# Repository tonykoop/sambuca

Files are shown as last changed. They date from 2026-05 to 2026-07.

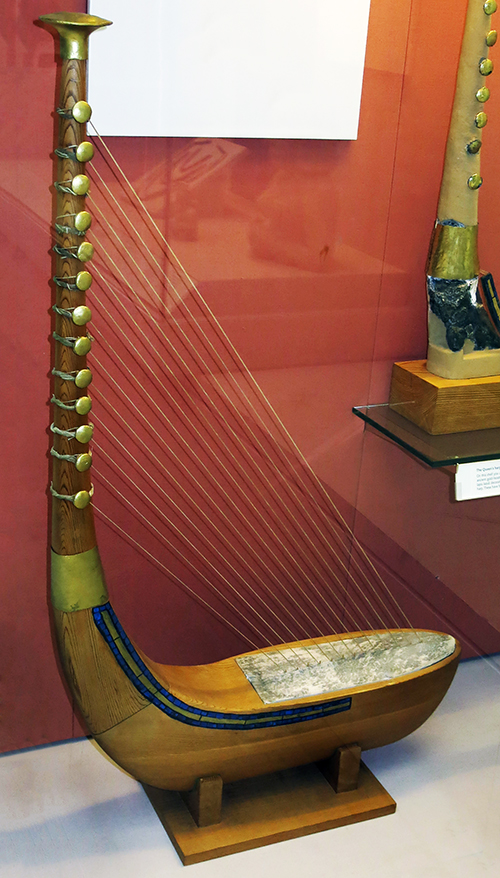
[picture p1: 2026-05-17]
images/SambucaPhotobyDonHitchcock_BritishMuseum.jpg

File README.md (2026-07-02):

# Sambuca

A modern boat-shaped arched harp inspired by the Royal Cemetery of Ur, c. 2600 BC.

> "More accurately described as a boat-shaped harp" — British Museum curator's card, object 121198.

**Status:** L2 V5 build-packet candidate

## Readiness

Private review. Full v4 planning packet complete (BOM, cut list, validation, assembly manual, Wolfram acoustic study, capstone deck). SolidWorks CAD is kora Pack-and-Go inherited geometry (pending rebuild per `cad/SW-MIGRATION-CHECKLIST.md`); a parametric OpenSCAD envelope master (`cad/sambuca.scad`, authority `pending_measurement`) now scaffolds the boat-hull/neck family from `family-spec.csv`, but no fabrication-authority drawings exist yet. Three release gates open: SAM-13-MULE tension/joint validation, cultural-advisor review, Heifer Zephyr brand integration. Not L3 — no measured template, no dimensioned DXF, no prototype setup report.

---

## What this is

The sambuca is Tony Koop's reinterpretation of the Sumerian boat-shaped arched harp recovered from the Royal Tombs at Ur. The original artifact (British Museum object 121198) survives only as gold tuning pegs, lapis lazuli decorative fragments, and Woolley's field sketches; the wood was reconstructed in 1971–72 from contemporary cylinder-seal depictions. That gives the modern build a 4500-year-old visual fingerprint — boat hull, curved cantilever neck, gold-flared cap, multi-strip lapis seam band, row of bulb tuning pegs with cord wraps, bow-end inlay panel, integral stern stub feet — and full design freedom on every dimension underneath.

This build modernizes the form with:

- CNC-routed walnut boat hull, raised depth (D/L = 0.31 for SAM-13, scaling to 0.40 for SAM-25 per chang reference) — parametric half-ellipsoid; stave-laminated alternative supported.
- Laminated-bend CNC-swept sapele neck.
- **Zither pegs (wood-bodied, steel hex tip)** for SAM-13 — switched 2026-05-16 from gold-bulb-capped geared tuners; matches chang-tradition look and pairs with new hull-side inlay program. Modern metal geared hardware remains a documented alternate.
- Western red cedar soundboard (~3 mm) with light fan bracing.
- Multi-strip lapis-look CNC inlay band along the soundboard-hull seam (5 parallel strips with light spacers).
- Rectangular pale inlay panel at the bow end of the soundboard (mother-of-pearl or shell composite).
- **Intricate longitudinal hull-side inlay** running ~70% of body length on both hull faces (added 2026-05-16) — cylinder-seal-style figural or Sumerian-rosette motifs, CNC-routed pockets backfilled with shell, contrasting wood, brass wire, or dyed epoxy.
- Brass collar over a glued scarf joint at the neck-body junction.
- **Slip-cast ornamental finial** at the top of the neck (porcelain or stoneware, glazed; natural placement for the Heifer Zephyr bison mark) — chosen 2026-05-16 over the BM-style flared gold cap.
- Single oval keel-port soundhole projecting forward toward the listener (not toward the player).
- Glued-on string-holder strip near the bow (standard arched-harp practice — no separate raised bridge bar).
- Fluorocarbon-treble + wound-nylon-bass string set, calibrated to 65–80 kgf total.
- Walnut CNC-curve-profiled cradle stand with kanawa-tsugi or mitsuke-aritsugi joinery.

## Family

Five planned variants, all from one MasterLayout part. See `family-spec.csv`.

| ID | Body length | Strings | Tuning | Harness | Role |
|---|---|---|---|---|---|
| **SAM-13-ROOT** | 650 mm | 13 | G3 → E5 | none | build target |
| SAM-19-MID | 850 mm | 19 | D3 → G5 | low-back belt | mid concert |
| SAM-25-CONCERT | 1050 mm | 25 | A2 → A5 | sax harness | concert |
| SAM-13-AE | 650 mm | 13 | G3 → E5 | none + piezo | acoustic-electric |
| SAM-13-MULE | 650 mm | 13 | G3 → E5 (reduced T) | none | tension test mule |

## Status

- ✅ Taxonomy locked (arched harp / sambuca, not lyre — confirmed by BM curator card).
- ✅ Anchor dimensions captured from BM 121198 display card and the second photo set.
- ✅ Reverse-engineering analysis complete (`reverse-engineering.md`).
- ✅ Design intent, family spec, soundhole strategy, harness design, inlay program documented (`design.md`).
- ✅ SolidWorks global equations file (`cad/SAM-000_master-equations.txt`).
- ✅ Wolfram acoustic study with soundboard plate-mode estimator and coupled cavity × plate response (`wolfram/sambuca-acoustics-starter.wl`).
- ✅ Full v4 build packet — BOM, sourcing, cut list, validation, assembly manual, supplier RFQs, drawing brief, visual BOM brief, photo shotlist, CNC operation plan, risks register, capstone deck, print packet, build-log site.
- ✅ Dual-license arrangement locked (CERN-OHL-W-2.0 for design files + CC-BY-4.0 for written content).
- 🟡 SolidWorks MasterLayout rebuild from kora Pack-and-Go — checklist in `cad/SW-MIGRATION-CHECKLIST.md`, manual SW UI work pending.
- 🟡 SVG drawings — generated from SolidWorks once the rebuild clears.
- 🟡 SAM-13-MULE build for tension and joint validation (release gate).
- 🟡 Cultural-advisor review of provenance language (release gate).
- 🟡 Heifer Zephyr brand integration option locked (release gate).
- 🟡 Learn-to-play starter songbook (paired with `sheet-music` skill, populates after MULE voicing).

## Packet map

### Design foundation

- `reverse-engineering.md` — analysis of BM 121198 and the second photo set. Read this first.
- `design.md` — design intent, soundhole strategy, harness logic, inlay program, cultural provenance language, brand options.
- `acoustic-validation-decision.md` — public/private-review decision record for acoustic validation tracking.
- `family-spec.csv` — five family variants.
- `risks.md` — red-team register with verification tests.

### Tables

- `bom.csv` — make/buy materials and hardware, per-variant.
- `sourcing.csv` — candidate suppliers, planning prices (not live-verified).
- `cut-list.csv` — rough and final dimensions for every cut, both hull options.
- `validation.csv` — dimensional, tension, acoustic, joint, safety, and cultural checks.

### Build process docs

- `assembly-manual.md` — 12-stage build sequence with MULE tension hold point.
- `supplier-rfq.md` — RFQ drafts for wood, brass, strings, tuners, inlay, harness, electronics.
- `drawing-brief.md` — 22-sheet manufacturing-drawing spec.
- `visual-bom-brief.md` — layout spec for the visual BOM one-pager.
- `photo-shotlist.md` — capture list across the build.

### Engineering

- `cad/SAM-000_master-equations.txt` — global equations (single source of truth).
- `cad/sambuca.scad` — parametric OpenSCAD boat-hull/neck envelope (authority `pending_measurement`; traced to master-equations + family-spec; not fabrication authority).
- `cad/SW-MIGRATION-CHECKLIST.md` — SolidWorks rebuild plan.
- `cad/README.md` — operational notes.
- `evolution/` — evolution-pipeline Stage 0 intake: master manifest, design-intent, and revision register (Gate A not yet run).
- `cad/SAM-000_MasterLayout.SLDPRT`, `cad/SAM-000_SAMBUCA.SLDASM` — Pack-and-Go from kora (geometry pending rebuild).
- `cnc/cnc-plan.md` — pre-CAM operation plan per part.
- `wolfram/sambuca-acoustics-starter.wl` — acoustic study notebook with plate-mode + coupled-response extensions.
- `drawings/README.md` — drawing-package index (SVGs generated from SW after rebuild).
- `harness/README.md` — SAM-19 and SAM-25 harness designs.

### Capstone

- `capstone-deck.md` — slide outline.
- `capstone-deck.pptx` — 15-slide capstone presentation.
- `capstone-manifest.json` — artifact inventory.
- `print-packet.md` — shop packet source.
- `print-packet.html` — styled HTML version.
- `print-packet.pdf` — print-ready PDF.

### Public-facing

- `site/index.html` — build-log site (private-review banner until release).
- `learn-to-play/` — placeholder; populated by the `sheet-music` skill once MULE voicing locks the tuning.

### License

- `LICENSE` — top-level dual-license overview.
- `LICENSE-design.txt` — CERN-OHL-W-2.0 full text (governs design files).
- `LICENSE-content.txt` — CC-BY-4.0 full text (governs written content and media).

## How to use this repo

**If you want to build a sambuca:**
1. Read `print-packet.pdf` (or `print-packet.md`) — that's the shop-facing summary.
2. Open `assembly-manual.md` and `cnc/cnc-plan.md` at the bench.
3. Keep `cut-list.csv`, `validation.csv`, and `bom.csv` close.
4. Don't skip Stage 9 (string-holder strip voicing on the MULE) or Stage 10 (the 30-day tension hold).

**If you want to understand the design:**
1. `reverse-engineering.md` for the source material.
2. `design.md` for the modern design decisions.
3. `wolfram/sambuca-acoustics-starter.wl` for the acoustic study.
4. `cad/SAM-000_master-equations.txt` for the numeric source of truth.

**If you want to see the capstone presentation:**
1. `capstone-deck.pptx`.
2. Or browse `site/index.html` for the build-log version (private-review until release).

**If you want to adapt or extend:**
1. The MasterLayout is parametric — `body_length_mm` and `string_count` drive the five variants. Add a sixth by adding a row to `family-spec.csv` and a configuration in the SolidWorks design table.
2. The string-tuning is locked at G-major as the build target; A-major is documented as a drop-in retune in `supplier-rfq.md` Set B.

## Provenance & cultural notes

The sambuca pattern is rooted in early Mesopotamian (Sumerian) musical instruments from the Royal Cemetery at Ur, approximately 4500 years old. The pattern itself is unambiguously in the public domain — there is no living tradition with a claim on the form, no surviving lineage of practitioners, and the surviving artifact at the British Museum (object 121198) is itself a 1971–72 reconstruction of which only the gold tuning pegs and lapis lazuli decorations are original Sumerian material. The wood is interpretive.

The Greek term *sambykē* (σαμβύκη) is a later (Hellenistic) word, historically debated as a possible descendant of the Sumerian form. This build adopts "sambuca" as the modern repo and brand term while acknowledging that the Hellenistic *sambykē* may or may not be a direct descendant; it is not a claim of identity with the Greek instrument.

This build is **inspired by** the Sumerian pattern. It is **not**:

- A reproduction of any specific surviving artifact.
- A recreation of any reconstructed instrument such as BM 121198.
- A claim of cultural authority over any modern living tradition.
- A claim that the original sounded like this — we have no recordings of Sumerian music; tuning systems, voicing, and performance practice for the original are unknowable.

The full cultural-provenance language is in `design.md` (section "Cultural provenance language (locked for public release)") and is the subject of one of the three release gates.

## Related repos

- [`kora`](../kora) — multi-string harp template; parametric structure adapted here for sambuca.
- [`fujara`](../fujara) → [`moseno`](../moseno) — earlier SolidWorks MasterLayout precedent (Pack-and-Go variant pattern).
- [`instrument-showcase`](../instrument-showcase) — portfolio entry point.
- [`ashiko-drum-workshop`](../ashiko-drum-workshop) — workshop-content precedent (single-license CC-BY-4.0; the sambuca is dual-licensed because it includes serious hardware design).

## License

**Dual-license** by content type.

- **Design files** — `cad/`, `drawings/`, `cnc/`, `harness/`, `bom.csv`, `sourcing.csv`, `cut-list.csv`, `validation.csv`, `family-spec.csv`, `wolfram/*.wl` — are licensed under [**CERN Open Hardware Licence Version 2 – Weakly Reciprocal**](https://spdx.org/licenses/CERN-OHL-W-2.0.html) (SPDX: `CERN-OHL-W-2.0`). See `LICENSE-design.txt`.

- **Written content and media** — `*.md` files, `capstone-deck.pptx`, `capstone-manifest.json`, `print-packet.*`, `site/`, `images/`, `learn-to-play/` — are licensed under [**Creative Commons Attribution 4.0 International**](https://spdx.org/licenses/CC-BY-4.0.html) (SPDX: `CC-BY-4.0`). See `LICENSE-content.txt`.

- See `LICENSE` for the dual-license overview, attribution guidance, and third-party material credits.

Why dual-license: the design files want hardware-native legal shape with patent provisions and a weak share-back requirement; the documentation and media want permissive reuse with attribution. The CERN-OHL-W keeps the parametric design open under modification-and-redistribution scenarios but doesn't restrict anyone building a sambuca; CC-BY makes the writing and photos easy to quote, excerpt, and learn from.

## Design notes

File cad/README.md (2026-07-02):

# cad/ — operational notes

This folder holds the SolidWorks design package. The canonical authoritative source for all dimensions is `SAM-000_master-equations.txt`; everything else in this folder consumes those values.

> **Don't edit `SAM-000_master-equations.txt` without coordinating** — it's the single source-of-truth for the design, and the variables are referenced by name throughout the build packet (`bom.csv`, `cut-list.csv`, `validation.csv`, `wolfram/sambuca-acoustics-starter.wl`).

## File map

| File | Status | Purpose |
|---|---|---|
| `SAM-000_master-equations.txt` | locked | Authoritative global equations. Paste into SolidWorks Equations Manager. |
| `sambuca.scad` | pending_measurement | Parametric OpenSCAD boat-hull/neck envelope traced to `SAM-000_master-equations.txt` + `../family-spec.csv`. Renders clean; NOT fabrication authority and does NOT supersede the SolidWorks MasterLayout rebuild. |
| `SW-MIGRATION-CHECKLIST.md` | in-progress | Step-by-step rebuild of the SolidWorks MasterLayout from kora Pack-and-Go. Path A recommended. |
| `SAM-000_MasterLayout.SLDPRT` | kora-inherited geometry | Pack-and-Go output. Internal geometry is still kora-shaped; rebuild per the migration checklist. |
| `SAM-000_SAMBUCA.SLDASM` | kora-inherited mates | Assembly file. Re-mate after MasterLayout rebuild. |
| `SAM-000_Sambuca_ALL_CONFIGS_dimensions.csv` | to be generated | Design-table export. Produced after the model rebuilds cleanly across all 5 configurations. |

## CAD workflow gates

Three gates before declaring CAD work complete (per the migration checklist):

1. **MasterLayout rebuilds with no errors** across SAM-13-ROOT, SAM-19-MID, SAM-25-CONCERT, SAM-13-AE, SAM-13-MULE.
2. **Design-table dimensions export to CSV** cleanly — this CSV becomes a packet artifact.
3. **Assembly opens with all mates resolved** — required before producing the drawings package.

## CAD-to-packet handoff

Once gates close:

- Export drawings per `../drawings/README.md`.
- Run `scripts/generate_drawings.py` from the instrument-maker-v4 skill against this folder, or hand-draft per the drawing brief.
- Run `scripts/generate_sw_design_table.py` against `../family-spec.csv` to produce a SolidWorks design-table xlsx if needed for round-trip.
- Update `../validation.csv` row V-D-* targets if any dimensions changed during CAD rebuild.

## Family-table configurations

The design-table will carry these 5 rows:

| Configuration | body_length_mm | string_count | f_min_hz | f_max_hz |
|---|---|---|---|---|
| SAM-13-ROOT | 650 | 13 | 196.0 | 659.3 (E5) |
| SAM-19-MID | 850 | 19 | 146.8 | 783.99 (G5) |
| SAM-25-CONCERT | 1050 | 25 | 110.0 | 880.0 (A5) |
| SAM-13-AE | 650 | 13 | 196.0 | 659.3 |
| SAM-13-MULE | 650 | 13 | 196.0 | 659.3 |

> The f_max values above target the G-major-family build. For the A-major retune SKU, f_max for SAM-13 becomes 740.0 (F#5) and the string set changes; no neck modifications.

## Notes on the dimensional check vs photo evidence

The second photo set (2026-05-16) added two parametric features that were added to `SAM-000_master-equations.txt` after Tony's review:

- `inlay_strip_count`, `inlay_strip_width_mm`, `inlay_strip_gap_mm` — multi-strip lapis band parameters.
- `bow_panel_length_mm`, `bow_panel_width_mm`, `bow_panel_depth_mm`, `bow_panel_x_from_stern_mm` — bow-end soundboard inlay panel.

These need to be reflected in the SolidWorks MasterLayout sketches when Step 4 of `SW-MIGRATION-CHECKLIST.md` (build master sketches) reaches the soundboard. Specifically:

- The Soundboard sketch needs the inlay-band pocket as 5 parallel strips with spacers (not a single binding strip).
- The Soundboard sketch needs the rectangular bow-panel pocket at `bow_panel_x_from_stern_mm`.

Suggest updating `SW-MIGRATION-CHECKLIST.md` Step 4 to add a sub-step 4l ("Soundboard inlay program: 5 parallel strips + bow panel pocket") at the end.

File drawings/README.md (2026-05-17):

# drawings/ — placeholder

This folder will hold the manufacturing-drawing SVG set per `drawing-brief.md`. SVGs are generated from the SolidWorks MasterLayout once the rebuild in `cad/SW-MIGRATION-CHECKLIST.md` completes.

## Files to produce (in order of capstone priority)

| File | Sheet # | Source | Priority for Fall 2026 capstone |
|---|---|---|---|
| `sambuca-overview-front.svg` | 01 | SW front elevation export | HIGH |
| `sambuca-overview-side.svg` | 02 | SW right elevation export | HIGH |
| `sambuca-overview-top.svg` | 03 | SW top plan export | HIGH |
| `sambuca-hull-side-profile.svg` | 04 | SW Right plane detail | medium |
| `sambuca-hull-top-profile.svg` | 05 | SW Top plane detail | medium |
| `sambuca-hull-cross-section.svg` | 06 | SW sections | medium |
| `sambuca-neck-arc.svg` | 07 | SW neck path + sections | medium |
| `sambuca-scarf-collar.svg` | 08 | SW joint detail | medium |
| `sambuca-string-holder-strip.svg` | 09 | SW strip + holes | medium |
| `sambuca-soundboard-inlay.svg` | 10 | SW soundboard + inlay | HIGH (for capstone "inlay program" slide) |
| `sambuca-keel-port.svg` | 11 | SW bottom + section | low |
| `sambuca-stand.svg` | 12 | SW stand assembly | low |
| `sambuca-stand-kanawa.svg` | 13 | SW joint detail | low |
| `sambuca-tuner-cap-wrap.svg` | 14 | SW tuner section | medium |
| `sambuca-stern-eyebolt.svg` | 15 | SW eyebolt + plate | low (variant-only) |
| `sambuca-brand-option-a.svg` | 16 | SW soundboard wordmark | gate-blocked |
| `sambuca-brand-option-b.svg` | 17 | SW stand wordmark | gate-blocked |
| `sambuca-family-overview.svg` | 18 | All 5 configs at 1:5 | HIGH (for capstone "family-spec" slide) |
| `sam-19-mid-overview.svg` | 19 | SW config: SAM-19-MID | medium |
| `sam-25-concert-overview.svg` | 20 | SW config: SAM-25-CONCERT | medium |
| `sam-13-ae-overview.svg` | 21 | SW config: SAM-13-AE | low |
| `sam-13-mule-overview.svg` | 22 | SW config: SAM-13-MULE | medium |

## Pre-CAD interim drawings (manual SVGs)

If SolidWorks rebuild slips, hand-draft these four SVGs from the master-equations dimensions for the capstone:

- `sambuca-overview-front.svg` — manually drafted from `body_length_mm`, `instrument_height_mm`, neck arc.
- `sambuca-overview-side.svg` — manually drafted from side profile + bow lift + keel port.
- `sambuca-soundboard-inlay.svg` — manually drafted soundboard plan with inlay band + bow panel.
- `sambuca-family-overview.svg` — five overlapping silhouettes at 1:5.

Don't draft the detail/section sheets manually — they need real CAD geometry.

## Conventions

All SVGs:

- Title block at lower-right: Project, Variant, Sheet, Scale, Units, Rev, Date, Author.
- Datums labeled per `drawing-brief.md` (DATUM A, B, C).
- Dimensions referenced to datums, not chained.
- Critical dimensions called out per `drawing-brief.md` table.
- Source comment in SVG header: `<!-- Generated from cad/SAM-000_master-equations.txt rev [X] -->`.

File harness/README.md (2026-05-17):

# Sambuca Harness Designs

For the larger family variants (SAM-19-MID and SAM-25-CONCERT), the instrument's weight benefits from external support. Two harness approaches.

## Option A — Low-back positioning belt (SAM-19-MID)

Pattern: padded work-positioning belt (climbing / fall-arrest style) with side D-rings.

- Belt: 50–75 mm wide padded waist belt with hook-and-loop + steel buckle closure.
- D-rings: two stainless steel side D-rings (one per hip).
- Tether: short adjustable nylon strap from one or both D-rings to a fixed eyelet on the **stern** of the boat (i.e., the back end of the hull, opposite the neck).
- Sets the body's vertical load against the belt; the player still cradles the boat between their thighs but doesn't carry full weight.
- Off-the-shelf option: climbing/arborist positioning belt with the harp eyelet retrofitted.

Diagram brief: see `belt-tether.svg` (to be drawn).

## Option B — Saxophone-style shoulder harness (SAM-25-CONCERT)

Pattern: padded yoke harness, like a tenor/baritone saxophone harness (BG, Neotech, Cebulla styles).

- Yoke: padded shoulder pads with sternum cross-strap, distributing weight across both shoulders.
- Hook: heavy-duty snap-hook clipping to a fixed eyelet on the stern of the boat.
- Length: adjustable so the boat hangs at sternum height when standing.
- Standing playing position tilts the neck slightly forward; both hands access strings comfortably with the boat suspended.
- Off-the-shelf option: BG S40SH saxophone harness with the harp eyelet retrofitted; or custom-stitched leather + ballistic nylon equivalent.

Diagram brief: see `sax-harness.svg` (to be drawn).

## Mounting eyelet — common to both options

A single fixed point on the **stern** of the boat hull serves both harness options. Spec:

- Hardware: stainless steel forged eyebolt, M6, 40 mm shank.
- Mount: through-hull with internal backing plate (10 mm hardwood block glued + screwed inside the hull).
- Location: stern centerline, ~25 mm above the keel.
- Load: rated for 3× instrument weight as safety factor.

## Open questions

1. SAM-13-ROOT — is a harness option worth designing, or is the seated-thighs grip sufficient?  (Current design: no harness for SAM-13-ROOT.)
2. Standing-position playing angle — is the neck-vertical/neck-tilted-forward decision a player preference or geometry-fixed?
3. Quick-release vs. fixed eyelet — does Tony want to swap harness types or commit per-instrument?

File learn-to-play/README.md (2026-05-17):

# learn-to-play/ — placeholder

This folder will hold the starter songbook for the sambuca SAM-13-ROOT once the tuning system is locked.

## Status

- ⬜ **Locked:** G-major build target, G3 → E5 diatonic, 13 strings.
- ⬜ **Pending:** the SAM-13-MULE voicing pass that determines the exact string-holder strip position. The tuning is locked, but the speaking lengths shift slightly when the strip position is finalized.
- ⬜ **Pending:** A-major drop-in retune string set (documented in `supplier-rfq.md` as Set B). The learn-to-play folder will get a sibling sub-folder for A-major once the G-major songbook is in place.

## Population plan

Once the MULE clears Stage 9 (string-holder strip position locked) and the SAM-13-ROOT is strung to calibrated tension, hand off to the `sheet-music` skill. The skill knows the sambuca's family layout and can populate this folder following the kora repo's pattern:

- `00-warmup-scales/` — practice scales for the G-major tuning (G major, E minor pentatonic, modal exercises).
- `01-easy/` — entry-level pieces tied to single-octave fingerings.
- `02-intermediate/` — full-range pieces using bass cross-thumb technique.
- `03-original/` — original compositions for the sambuca; candidate first piece: "Heifer Zephyr" themed tune commissioned per the brand-integration gate.

Each piece gets:

- `notes.md` — playing notes, fingering, tempo, character.
- `score.abc` or `score.ly` — ABC or LilyPond source.
- `score.pdf` — rendered sheet music.
- `score.midi` — MIDI rendering for practice.

## Cross-reference

- Tuning anchor: `cad/SAM-000_master-equations.txt` (the `f1_hz` through `f13_hz` block).
- Family-spec: `family-spec.csv` (drives variant-specific songbooks).
- Skill: `sheet-music` (Anthropic skill registry; pairs with `instrument-maker-v4`).

## Not yet

Nothing buildable lives in this folder yet. Re-run with the `sheet-music` skill after the MULE Stage 9 voicing clears.

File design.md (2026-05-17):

# Sambuca — Design Notes

## Design intent

A modern, parametric, family-scalable boat-shaped arched harp that preserves the Sumerian visual fingerprint while delivering modern playability, tunability, and projection.

## Reference precedents

| Reference | What it anchors | File in `images/` |
|---|---|---|
| **British Museum 121198** (c. 2600 BC) | Anchor dimensions, slim hull, single-arc neck, gold-bulb tuning pegs, lapis seam band, gold collar fingerprint | `SambucaPhotobyDonHitchcock_BritishMuseum.jpg` |
| **Chang Chogha Mish** (modern maker, after ~3300 BCE Iranian arched-harp tradition) | Deeper hull proportion (D/L ≈ 0.4), lateral wood-bulb tuning pegs, two-band multi-strip inlay (joint + bow edge), bow-side soundboard rose, no flared cap | `چنگ-چغامبش-11-1536x1536-1-2048x2048.jpg` |
| **Penn Museum B16728 cylinder seal** (c. 2500–2340 BCE, Pu-abi's tomb) | Held-vertical seated playing position; archaeological context only — depicts a different (4-string) instrument | not stored locally |

The chang lineage is the broader Persian/Mesopotamian sibling family to the Ur boat-harp. Where the BM reconstruction is small, slim, and gold-accented, the chang tradition supports a fuller, deeper, more concert-sized instrument. The sambuca family draws from both: SAM-13-ROOT closer to the BM proportions, SAM-25-CONCERT closer to the chang proportions.

## Family

Five planned variants (see `family-spec.csv` for full table):

| ID | Role | Strings | Body length × depth | Tuning range | Playing position |
|---|---|---|---|---|---|
| **SAM-13-ROOT** | build target | 13 | 650 × **200** mm (D/L = 0.31, raised from BM's 0.23 per Tony 2026-05-16) | ~1.7 octaves, G3 → E5 diatonic | Seated, body between thighs, neck rising away from torso, both hands symmetric |
| **SAM-19-MID** | scaled mid concert | 19 | 850 × **280** mm (D/L = 0.33) | ~2.7 octaves, D3 → G5 | Seated with optional low-back positioning belt |
| **SAM-25-CONCERT** | concert | 25 | 1050 × **420** mm (D/L = 0.40, chang-like full hull) | ~3.5 octaves, A2 → A5 near-chromatic | Seated or standing; **saxophone-style harness** |
| **SAM-13-AE** | acoustic-electric | 13 | 650 × 200 mm | same as ROOT | same as ROOT; adds under-strip piezo + 1/4" jack in stern stub |
| **SAM-13-MULE** | low-tension test mule | 13 | 650 × 200 mm | same as ROOT, reduced tension (3.0–4.5 kgf/string) | same as ROOT; used for tension + joint + string-holder-strip-position validation |

**Hull-depth update (2026-05-16):** the BM-anchor depth of 150 mm produced a slim hull; the chang reference photo shows the deeper, fuller proportion reads better and gives substantially more cavity volume. SAM-13 raised to 200 mm (D/L = 0.31), SAM-19 to 280 mm, SAM-25 to 420 mm (matches chang proportion). New cavity volumes: 10.2 L / 24.4 L / 56 L respectively — significant projection upgrade across the family.

All five share one MasterLayout part with `string_count` and `body_length_mm` as the family-driving parameters. SAM-13-ROOT is the build target; the other four are documented as Pack-and-Go siblings (mirroring the fujara → moseno pattern).

## Soundhole strategy — at the keel

**Decision:** the soundhole is cut into the *keel* (curved bottom of the hull), not the soundboard.

Rationale:
- In the seated playing position, the boat is held between the thighs with the soundboard facing the player.
- A traditional soundboard rose would project sound *into the player's chest*, where it would be absorbed by clothing and the player's body — wasted radiation.
- A keel-port projects sound **forward and downward toward the listener**, away from the player. Equivalent to side-ports on modern concert harps but cleaner ergonomically for a held-between-thighs instrument.
- This is **not** a feature of the original — the BM reconstruction has no soundhole at all. It's a modern functional improvement consistent with the "preserve fingerprint, modernize everything else" design principle.

**Geometry options to study in Wolfram:**

- Single oval port, ~80 × 50 mm, centered ~55% of length from bow.
- Two smaller round ports flanking the string-holder-strip projected keel line (40 mm dia each).
- Three-port Helmholtz tuning (one keel port + two soundboard rosettes) — most projection but compromises the clean Sumerian top.
- No keel port + dual side-ports near the player's ears — *monitor* design, sacrifices listener-facing volume for player feedback.

Default for first prototype: **single keel port, oval, 80×50 mm, tunable position**. The keel curvature makes the port directional — angling the cut slightly forward biases radiation toward the listener.

## Quiet-instrument mitigation

After the hull-depth update, SAM-13-ROOT cavity is ~10.2 L (was 7.7 L at the slim BM proportion). Mitigations available, ranked by complexity:

1. **Soundboard species + thinness sweep.** Spruce / cedar / redwood at 2.5–4.0 mm. Wolfram-tested before committing.
2. **Keel port** (above) — releases trapped air-pressure modes that would otherwise just heat the cavity.
3. **Bracing topology.** Light fan brace pattern across the soundboard, like a small classical guitar's bracing — adds soundboard area-moment-of-inertia coupling.
4. **Larger family variants.** SAM-19 (~24 L cavity, post-depth-update) and SAM-25 (~56 L cavity, chang-proportioned) self-solve the volume problem by being bigger.
5. **Pickup option.** Under-strip piezo transducer or contact pickup. Acoustic-electric variant for performance settings. See SAM-13-AE family-spec row; `cad/SAM-PICKUP-*` configuration of the MasterLayout.

## Variable string count → variable neck tuning-peg positions

Per the kora MasterLayout pattern, each string's tuning peg position along the neck face is a named global variable (`s1_neck` through `sN_neck`). For sambuca, these are **frequency-driven** rather than fixed proportional positions.

Each string's speaking length:

```
L_n = L_min × (f_max / f_n)^k
```

where:
- `f_n` = string n's pitch in Hz (set by tuning scheme)
- `f_max` = highest string's pitch
- `L_min` = shortest speaking length (mm)
- `k` = curve exponent (k=1 strict inverse-frequency; k≈0.7–0.85 typical of traditional harps because string mass varies across the range)

Each string's tuning peg position along the neck face:

```
s_n_neck = strip_tie_hole_at_string_n_xyz  + L_n × (unit vector from strip tie-hole to neck-anchor for that string)
```

Implementation:
- In SolidWorks: build a 3DSketch driven by string-by-string equations from a design-table column.
- Sweep configurations: change `string_count`, `f_min`, `f_max`, `tuning_scheme`, `k` → all peg positions update automatically.
- Tuning schemes to support: diatonic major, diatonic minor, pentatonic (5-/7-note), chromatic (full), Just intonation variants.

The `cad/SAM-000_master-equations.txt` file in this repo lists the global-variable equations adapted from the kora pattern.

## String termination — no separate bridge bar

The sambuca follows standard **arched-harp practice**: strings terminate directly at the soundboard via a glued-on **string-holder strip** running along the bow-end of the soundboard centerline. There is no raised bridge bar like a guitar or violin has — the string-holder strip *is* the bridge in this instrument class.

| Feature | Spec | Notes |
|---|---|---|
| String-holder strip cross-section | 10 mm wide × 4 mm thick | Walnut, maple, or rosewood — high-mass wood for low-end response |
| String-holder strip length | ~120 mm × `scale_factor` | Spans the 13 tie-through holes |
| Tie-through hole spacing | `string_spacing_mm` (≈ 6 mm for SAM-13-ROOT) | Driven by global equation |
| Tie-through hole diameter | 1.5 mm | Sized for fluorocarbon + knot |
| Position on soundboard | ~80% of body length from stern (i.e., near the bow, close to where the neck meets the body) | Tuneable during prototyping; commit after voicing |
| Mounting | Glued to soundboard with hide glue (reversible if needed) | Hide glue is the standard for stringed-instrument repair access |

**Implication for SolidWorks:** no separate `Bridge` feature is needed. Replace with a `String_Holder_Strip` sketch on the soundboard. The 13 tie-through holes are linear-patterned along the strip, driven by `string_count` and `string_spacing_mm`. Equations file updated accordingly.

## Structural — neck-to-body joint

**Highest-risk joint in the whole instrument.** Under 13 strings at modern fluorocarbon tension (~5 kg/string average), total resultant force pulling the neck toward the bow is ~50–65 kgf, applied at a long lever arm (~660 mm above the joint).

Candidate joints (to red-team in `maker-engineering`):

| Option | Pros | Cons |
|---|---|---|
| Mortise + wedge through-tenon | Visible Japanese-style joinery; serviceable | Hard to CNC the angled mortise in the curved hull |
| Brass / bronze collar + glued lap | Visually echoes the original gold collar; strong | Mixed materials → differential thermal/humidity movement |
| Bolted-and-pinned with hidden plate | Strongest; demountable for travel/repair | Modern-looking unless camouflaged |
| Glued scarf + reinforcing biscuit | Cleanest aesthetic | Single shear path; harder to repair |

**First-pass recommendation:** brass collar over a glued scarf joint, hidden mechanical pin through both members. Visible collar references the original gold collar — fingerprint preserved.

## Stand

Stand is a **display/transport rest**, not a playing fixture (per the seated-thighs playing position).

Two CNC curve-profiled cradle uprights with a Japanese-style **kanawa-tsugi** (mechanical scarf joint with key) connecting the uprights to the base, or **mitsuke-aritsugi** (visible dovetail with mitre return). Both let the CNC handle the curves and the joinery happens at straight intersections.

Material: complementary to or contrasting with the harp wood — walnut against maple, or all-walnut for a unified set.

## Playing position & harness

**SAM-13-ROOT** (seated, body between thighs, neck rising away from torso):
- Long axis of the boat runs forward, between the player's thighs.
- Neck rises away from the player's torso — pointing forward and slightly up rather than toward either shoulder.
- Strings face the player and are accessible by both hands symmetrically; **handedness dissolves** in this orientation, so no left/right default-build is needed.
- Keel port points forward and down toward listener.
- Soundboard faces upward toward the player.
- No harness needed; weight rests on thighs.

The symmetric forward-facing orientation matches the playing position implied by the Royal Cemetery cylinder seal B16728 (held vertical, body against player). It also resolves the handedness question that the kora pattern raised: a kora is asymmetric (strings on both sides of a center post), but the sambuca's single neck face plus forward-facing orientation puts both hands on equal terms.

**SAM-19-MID** (seated with light support):
- Same playing position but heavier instrument; optional padded waist belt with side D-rings (like the first reference image — climbing/work positioning belt repurposed) and a tether strap from belt to the boat's stern.

**SAM-25-CONCERT** (seated *or* standing):
- Standing position requires a **saxophone-style harness** (second reference image): padded shoulder yoke distributing weight across both shoulders, sternum strap, hook clipping to a fixed eyelet on the stern of the boat.
- Standing playing tilts the neck slightly forward; the player's hands access strings comfortably with the boat suspended at sternum height.
- Designable as a separate `harness/` subassembly with adjustable strap lengths.

## Materials — first-pass slate

| Component | Candidate | Rationale |
|---|---|---|
| Hull | Cherry, walnut, or sapele | Bendable in stave construction; CNC-friendly |
| Soundboard | Engelmann or Sitka spruce, 3 mm | Standard harp soundboard species |
| Bracing | Spruce | Match soundboard movement |
| Neck | Hard maple or sapele, laminated | Stiff under cantilever load |
| String-holder strip | Walnut, hard maple, or rosewood | High-mass wood for low-end coupling |
| Tuning pegs | **Modern: zither pegs (wood-bodied with steel hex tip) or geared metal hardware** (see Tuner choice section) | Switched 2026-05-16 from gold-bulb caps; chang-tradition look |
| Inlay band | Lapis-lazuli-look composite or dyed veneer + epoxy fill | True lapis is brittle and expensive; modern equivalent acceptable |
| Strings | Fluorocarbon (treble) + wound nylon (bass) | Modern playability, low total tension |
| Neck collar | Brass or bronze | Functional + visual fingerprint |
| Stand | Walnut or matching hull species | Joinery showpiece |
| Harness | Padded ballistic nylon + leather + steel D-rings | Aftermarket sax-harness-derived |

## Tuner choice (updated 2026-05-16)

Previous fingerprint plan used PVD-gold-tone bulb caps hiding modern geared guitar tuners. Swapped to **modern visible tuner hardware** — two options, both legitimate:

| Option | Description | When to pick |
|---|---|---|
| **A. Zither pegs** | Wood-bodied tapered pegs with steel hex tip (turned with a tuning wrench, like a hammered dulcimer or autoharp). Standard zither hardware, ~6 mm shank, drilled directly into the neck. | Cleanest "chang" look (matches the lateral wood-bulb pegs in the reference photo); no metal box visible; tuning is fine but slower than geared |
| **B. Modern metal hardware** | Geared open-frame tuners (like banjo or autoharp tuners), or planetary-geared pegs (Pegheds, Knilling Perfection) | Cleanest tuning stability; faster tuning; more "modern instrument" look; visible chromed/gold-anodized hardware |

**SAM-13-ROOT first-pass pick:** option A (zither pegs) — lower cost, easier sourcing, more visually consistent with the chang-tradition reference photo, and the wood-on-wood look pairs better with the new hull-side inlay program.

**Implication for SolidWorks:** the `Neck Face` sketch needs Φ6 mm holes (not Φ12 for tuner posts) at each `s_n_neck` position. Hole depth ~25 mm, slight downward angle (~5°) into the neck face for tuning leverage.

## Finial options

The top of the neck is one of the more open design decisions — it can read as a small functional cap, a sculpted terminal, or an ornamental feature. Options:

| Option | Description | Notes |
|---|---|---|
| **A. Plain wood terminal** | Simple darker-wood cap, mortise-and-tenon mounted | Matches the chang reference photo; lowest cost; visually quiet |
| **B. Brass/gold-tone flared cap** | Echoes BM 121198 fingerprint; small trumpet/funnel | Pulls toward the Ur lineage; brand-friendly hardware piece |
| **C. Slip-cast ornamental top** | Custom ceramic finial — bison head, Sumerian rosette, abstract Heifer Zephyr mark, or other; slip-cast in porcelain or stoneware, glazed | Most distinctive; ties to the slip-cast workflow already in the `instrument-maker-v4` toolkit; one-off variants per build possible |
| **D. Carved hardwood finial** | Sculpted bison head or geometric form in the neck wood | Matches all-wood aesthetic; no separate material; CNC-shapeable with a follow-up hand-carve pass |

**SAM-13-ROOT first-pass pick:** option C (slip-cast ornamental top) — uses the existing slip-cast workflow, allows one-off variation per build, and provides a natural placement for the Heifer Zephyr bison mark.

## Inlay program (Broinwood-style + hull sides)

Pair with the `laser-art` skill for the parametric inlay generation. Inlay locations across the instrument:

| Location | Inlay treatment | Notes |
|---|---|---|
| Soundboard-hull seam | **Multi-strip lapis-look band** (5 parallel strips with light spacers) | Matches BM lapis seam; visible from above |
| Bow end of soundboard | **Rectangular pale inlay panel** (mother-of-pearl or shell composite) | Frames the string-holder-strip area |
| Neck-body joint band | **Multi-strip wood inlay** (light/dark alternating, ~6 strips) | Matches chang reference photo |
| **Hull sides — new (2026-05-16)** | **Intricate CNC-routed inlay** running longitudinally along both hull sides | Major design feature added per Tony's expansion of the inlay program |
| Neck face decorative band | Optional — narrow longitudinal inlay between tuner row and back of neck | Optional accent |

**Hull-side inlay program (new):**
- Two longitudinal panels, one per hull side, running ~70% of body length centered on the boat's beam-line.
- Each panel ~30–40 mm wide × variable length, sized parametrically to `body_length_mm`.
- Suggested motif palette: cylinder-seal-style figural narrative (boat-and-water scene, banquet figures, abstract Sumerian linework), or geometric Sumerian rosettes scaled across the panel.
- CNC-route pockets in same setup as hull shaping; back-fill with shell, contrasting wood, brass wire, or dyed-epoxy.
- Pair with the `laser-art` skill specifically for the figural-narrative variant — laser-cut inlay pieces drop into CNC-routed pockets for clean registration.

**Implication for SolidWorks:** add `Hull_Side_Inlay_L` and `Hull_Side_Inlay_R` sketches on opposite faces of the hull, mirrored across the long-axis plane. Pocket depth ~1.5 mm, panel size driven by `body_length_mm` and a new `hull_inlay_coverage_pct` global variable.

Candidate motifs for any of the above panels:

- Sumerian cuneiform fragment — actual line from a known tablet, micro-routed.
- Cylinder-seal scene — Royal Tomb procession (the same source class the original reconstruction drew on).
- Boat-and-water linework — modern abstract referencing the form.
- Geometric Sumerian rosette pattern.

CNC inlay pockets are added to the MasterLayout sketches and propagate to soundboard, decorative neck band, and now the hull sides.

## SAM-25-CONCERT alternative aesthetic (2026-05-16)

The chang reference photo gives SAM-25-CONCERT a distinct visual identity from the BM-anchored SAM-13-ROOT. Locked SAM-25 choices:

| Feature | SAM-13-ROOT (BM lineage) | **SAM-25-CONCERT (chang lineage)** |
|---|---|---|
| Hull depth ratio | D/L = 0.31 (raised from BM) | **D/L = 0.40** (chang-proportioned, full hull) |
| Soundhole | Single oval keel-port (forward projection) | **Bow-end soundboard rose** (~50 mm dia round, near string-holder strip) — chang-style |
| Tuners | Zither pegs (matching family default) | Zither pegs (consistent) |
| Finial | Slip-cast bison/Heifer Zephyr mark | Slip-cast ornamental, possibly larger / more sculptural piece |
| Inlay bands | Multi-strip lapis seam + bow inlay panel | **Two multi-strip bands** — at neck-body joint AND at bow edge (matches chang reference); plus hull-side inlay |
| Cavity volume | ~10 L | **~56 L** |
| Voicing target | Intimate, focused | **Substantial, concert-room projection** |

SAM-25 is the concert-stage instrument; SAM-13-ROOT is the intimate-listening instrument. Both share the same MasterLayout parametric backbone — variant differences resolve at the design-table configuration level, not as separate parts.

## Acoustic study program (Wolfram)

See `wolfram/sambuca-acoustics-starter.wl` for the starter notebook. Sweep:

1. Hull internal volume (3 → 10 L) — covers all three family variants.
2. Soundboard species & thickness (Sitka / Engelmann / cedar / redwood × 2.5–4.0 mm).
3. Soundhole geometry (none / single keel oval / dual keel circles / soundboard rose).
4. String set (fluorocarbon / nylgut / gut / wound options).
5. String-holder strip mass, length, and exact bow-end position.

Outputs: predicted first cavity mode, first soundboard plate mode, voiced response across the full string range, recommended pickup placement.

## Resolved this session (2026-05-16)

| Question | Resolution |
|---|---|
| Tuning system for SAM-13-ROOT | **G-major (G3 → E5) locked as the build target.** A-major (A3 → F#5) documented as a drop-in retune string set, no neck modification required (covered in `supplier-rfq.md`). |
| Mirror-image preference | **Dissolved by the symmetric forward-facing playing position.** Long axis of the boat runs forward between the thighs; neck rises away from the torso; both hands access strings symmetrically. No L/R default-build SKU. |
| Bridge vs. tailpiece | **No bridge bar.** Strings terminate at a glued-on string-holder strip near the bow end of the soundboard (standard arched-harp practice). Strip position is a voicing decision on the SAM-13-MULE prototype, then committed on SAM-13-ROOT. See "String termination — no separate bridge bar" section above. |
| Pickup option | **SAM-13-AE is its own family-spec row.** Under-strip piezo transducer + 1/4" output jack hidden in stern stub. SAM-13-ROOT stays purely acoustic. |
| Brand integration | **Both placements proposed for review** (see "Brand integration — Heifer Zephyr" section in the v4 additions below). Final pick deferred to the cultural/brand review gate. |
| Wood pairing for SAM-13-ROOT | **Walnut hull / Western red cedar soundboard / Sapele neck.** Cedar is more responsive than spruce at low SPL — useful for the small 3.8 L cavity. Sapele neck is stiff enough for cantilever and matches walnut tonally. |
| Release window | **Fall 2026 capstone (~Oct–Nov).** Aggressive but workable if the MULE tension test happens early in the schedule. |

---

# v4 Build-Packet Updates (2026-05-16)

This section was added when the repo was handed to the `instrument-maker-v4` skill for the full build packet. Everything above is the design intake. Everything below is the build-target design lock for the SAM-13-ROOT prototype, with Pack-and-Go siblings for the other four family variants.

## v4 design intent

Deliver a buildable SAM-13-ROOT prototype, plus a parametric family that scales to the other four variants without re-engineering, plus a full documentation slate (BOM, sourcing, cut list, validation, assembly manual, capstone deck, print packet, build-log site) honest enough that a competent woodworker with CNC access could build it from the packet alone.

The build target is the **SAM-13-ROOT**: 650 mm body length, 13 strings, G-major (G3 → E5), walnut/cedar/sapele wood pairing, single keel soundport, brass neck-body collar, multi-strip lapis-look inlay band, rectangular pale inlay panel at the bow end of the soundboard, glued-on string-holder strip near the bow, integral stub feet at the stern keel, CNC-curve-profiled stand with Japanese-style joinery. Aimed at the Fall 2026 capstone window.

## Design refinements from the second photo set (2026-05-16)

The second photo set added five design implications that flow into the BOM, cut list, and drawing brief:

1. **Multi-strip lapis band.** The original is a parallel-strip band, not a single binding strip. Spec: 5 parallel strips × 1.5 mm wide × 0.8 mm spacer, total band width ~12 mm, depth 1.5 mm. Material: lapis-blue-dyed veneer with thin maple or holly spacers, set in epoxy. Routed in a single CNC inlay pass with a 0.8 mm or 1.0 mm end mill.

2. **Bow-end soundboard inlay panel.** Roughly 100 × 60 mm pale rectangular panel inset into the soundboard at the bow end (~82% from stern), framing the string-holder strip area. Material options: mother-of-pearl tile (expensive, period-correct), shell-look composite, dyed-and-polished maple burl, or pale-stone veneer composite. Pocket depth 1.5 mm to match band depth; CNC pocket cut in the same inlay setup.

3. **Stern stub feet — integral, not decorative.** Two carved hardwood stub blocks integral to the keel near the stern. Function: bench-rest support when set down; visual rhyme to the original. Spec: ~30 × 25 × 15 mm walnut blocks, glued and pinned to the keel from inside the hull. Position determined parametrically by stern centerline + `body_depth_mm`.

4. **Tuner cord-wrap fingerprint.** Each tuner = geared guitar tuner (hidden inside the neck) → wooden shaft + visible decorative cord wrap → PVD-gold-tone bulb cap. The cord wrap is a separate visible element below the cap, not decorative-painted onto the cap. Spec: aged-look waxed-silk or sinew-look cord, ~1 mm diameter, ~8 turns per peg. Listed in BOM as a separate hardware line.

5. **Pronounced bow lift.** Side-profile sketch should include 10–15° upward tangent rotation at the bow end of the keel, like a small skiff. Visible in the right-plane profile drawing.

The corresponding parameters were appended to `cad/SAM-000_master-equations.txt` in the multi-strip and bow-panel sections.

## Cultural provenance language (locked for public release)

This is the verbatim language the build packet will use in the public README, capstone deck, and build-log site. It is also the language that the cultural-advisor review gate will assess before public release.

> The sambuca pattern is rooted in early Mesopotamian (Sumerian) musical instruments from the Royal Cemetery at Ur, approximately 4500 years old. The pattern itself is unambiguously in the public domain — there is no living tradition with a claim on the form, no surviving lineage of practitioners, and the surviving artifact at the British Museum (object 121198) is itself a 1971–72 reconstruction of which only the gold tuning pegs and lapis lazuli decorations are original Sumerian material. The wood is interpretive.
>
> The Greek term *sambykē* (σαμβύκη) is a later (Hellenistic) word, historically debated as a possible descendant of the Sumerian form. This build adopts "sambuca" as the modern repo and brand term while acknowledging that the Hellenistic *sambykē* may or may not be a direct descendant; it is not a claim of identity with the Greek instrument.
>
> This build is **inspired by** the Sumerian pattern. It is **not**:
>
> - A reproduction of any specific surviving artifact.
> - A recreation of any reconstructed instrument such as BM 121198.
> - A claim of cultural authority over any modern living tradition.
> - A claim that the original sounded like this — we have no recordings of Sumerian music; tuning systems, voicing, and performance practice for the original are unknowable.
>
> Modern updates that depart from the pattern are called out explicitly in `design.md`: keel-port soundhole (not original), geared guitar tuners hidden behind decorative caps (not original — original tuners were peg-and-wrap), modern fluorocarbon/nylon strings (not original — original strings were gut or twisted sinew), Broinwood-style CNC inlay (modern parametric process applied to fingerprint motifs), CNC-cut hull and neck (modern fabrication), Japanese-style joinery on the stand (a stylistic choice, not a Sumerian element).

This language will appear in:

- Public README (replacing the current "Provenance & cultural notes" section).
- Capstone deck slide 2 ("Provenance & design freedom").
- Print packet appendix.
- Build-log site footer.

## Brand integration — Heifer Zephyr

Two placement options for the Heifer Zephyr wordmark + bison mark, both consistent with the Sumerian fingerprint program. Final pick deferred to the brand-integration review gate.

### Option A — Soundboard inlay placement

- Wordmark in italic-serif treatment inlaid into the soundboard, positioned just **stern of the string-holder strip** (i.e., toward the player), where the strings don't obscure it during play.
- Size: ~80 mm wide × 14 mm tall.
- Material: same multi-strip inlay technique as the lapis band — but in a contrasting hue (brass-leaf veneer + dark-walnut spacer, or pale boxwood veneer with copper inlay).
- Bison mark: ~25 mm diameter, set to the right of the wordmark.
- Pros: visible to player and audience during performance; integrated into the period inlay program; visually claims the build.
- Cons: makes the brand inseparable from the instrument; harder to remove if branding ever changes; player must see it during every practice session.

### Option B — Stand-only placement

- Wordmark + bison mark inlaid into the **base of the stand cradle**, visible when the instrument is displayed but invisible when the instrument is in playing position (cradle is behind/under the boat).
- Size: ~120 mm wide × 18 mm tall on the front of the cradle base.
- Material: lapis-style multi-strip inlay matching the boat's seam band.
- Pros: brand visible in display photos and storefront imagery; not visible during play, so the instrument feels less "branded" in performance; stands can be remade if brand evolves.
- Cons: brand absent from the playing instrument; loses visibility during live performance.

### Hybrid (recommended for capstone)

Run Option B for the SAM-13-ROOT prototype (the build-target), and document Option A as a SAM-13-ROOT-BRANDED configuration for future production runs. This keeps the prototype neutral enough that the cultural-advisor review can focus on the Sumerian-provenance language without the brand integration becoming a distraction.

## Workbook interpretation

This repo deliberately does **not** carry an .xlsx Master Design Sheet (the kora pattern uses one; the sambuca was switched to a .txt equations file at the SolidWorks-handoff layer). The design data lives in three files:

- `cad/SAM-000_master-equations.txt` — global equations for SolidWorks Equations Manager. The authoritative numeric definitions.
- `family-spec.csv` — the five-row family table that drives the SolidWorks design-table configurations.
- `wolfram/sambuca-acoustics-starter.wl` — acoustic-study parameters, derived where possible from the master equations.

If a downstream xlsx is needed (for example, for the v4 SolidWorks design-table sync workflow), use `scripts/generate_sw_design_table.py` from the instrument-maker-v4 skill against `family-spec.csv`.

## Expanded physics model

The acoustic system has four coupled stages. Each is modeled separately in `wolfram/sambuca-acoustics-starter.wl`; the combined response is the new section being added in Phase 4 of this packet build.

| Stage | Equation | What it tells us |
|---|---|---|
| **String** | `f = (1 / 2L) · √(T / μ)` | Tension and length for each of the 13 strings at the chosen G-major tuning. |
| **Cavity** | `f_axial ≈ c / (2L)` for closed-end, Helmholtz `f_H = (c/2π)·√(A / (V · L_eff))` for keel port | First longitudinal mode ~265 Hz (closed) / ~132 Hz (one-open); keel-port Helmholtz prediction ~143 Hz for the SAM-13-ROOT geometry. |
| **Plate** | Cantilever / Chladni mode estimator for the soundboard, `f_pl ∝ (h / L²) · √(E / ρ)` | First plate mode falls in the range where the lower-middle strings live — confirms cedar is acoustically reasonable for the small cavity. |
| **Coupled** | Two-coupled-oscillator approximation (cavity ↔ plate) | The Helmholtz peak + first plate mode split into a coupled pair; the lower of the two should sit just below the lowest bass string (G3 = 196 Hz) to enable the cavity-supported bass response. |

**Voice prediction.** The bass strings on SAM-13-ROOT (G3 = 196 Hz through about C4 = 261 Hz) fall near or just above the predicted coupled Helmholtz-plate pair. This is the *sweet spot* — strings just above the lowest resonance get good radiation. The middle strings live above the first plate mode and below several higher cavity modes; their response will be dominated by the soundboard's broader response. The top strings (above ~600 Hz) are above all relevant cavity modes; they will radiate mostly through high-frequency soundboard modes and direct string radiation.

## String tension calibration plan

The starter values in `cad/SAM-000_master-equations.txt` produce ~103 kgf total tension on SAM-13-ROOT vs. a target of 65–80 kgf. The plan to bring this down:

1. **First pass (low risk):** Use wound nylon (NOT plain fluorocarbon) for strings 1–4 (the bass quartet). Wound bass strings have substantially higher μ per unit diameter, so they hold pitch at lower tension. Predicted reduction: ~25 kgf off the bass quartet, total drops to ~78 kgf — inside target band.

2. **Second pass if needed:** Shorten `string_len_max_mm` from 580 → 520. Trims the bass range envelope; the lowest string still reaches G3 but with marginally lower projection. Predicted further reduction: ~8 kgf.

3. **Validation:** Confirm on the SAM-13-MULE build (which intentionally runs at 3.0–4.5 kgf/string to validate joint behavior at reduced load). MULE proves the neck-joint geometry works; ROOT runs at the full calibrated 65–80 kgf load.

Implementation lives in `supplier-rfq.md` (string set spec) and the `validation.csv` row for total tension.

## Public-release gates

This repo stays in **private review** until all three of the following close:

| Gate | Owner | What it produces |
|---|---|---|
| **Cultural / musicology advisor review** | external advisor | Sign-off (or red-line) on the cultural-provenance language above; acknowledgment of the Sumerian → *sambykē* etymological note; review of any imagery used in the build-log site for misappropriation concerns. |
| **SAM-13-MULE tension and joint validation** | Tony | Successful tension-up of the MULE to 50% of target load with no neck-joint deflection beyond predicted; no soundboard cracking; string-holder strip position empirically tuned. Documented in `validation.csv` and the build-log. |
| **Heifer Zephyr brand integration** | Tony | Pick between Option A (soundboard) and Option B (stand-only); placement spec locked; inlay program updated; capstone deck and print packet final brand artwork prepared. |

The site `index.html` and the public README open with a `PRIVATE REVIEW — pending [cultural review · MULE validation · brand integration]` banner until these close.

## Sources

- BM 121198 display card and gallery photos.
- BM 121198 second photo set (close-up + full-instrument + three-quarter view), Tony Koop direct upload, 2026-05-16.
- Herbology Manchester profile photo of BM 121198, 2015.
- Royal Cemetery cylinder seal B16728 / Penn Museum object 47880.
- Kora MasterLayout pattern, `C:\Users\Tony\Documents\GitHub\kora\cad\KOR-000_MasterLayout.xlsx`.
- Tony's stated design intent and resolved-this-session answers, 2026-05-16.

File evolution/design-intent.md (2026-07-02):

# Design Intent — sambuca rev A

- Master CAD: `cad/sambuca.scad` (sha256: cf2d314c533a4bddbcf8b2ffe1b48a0dfc7d5da1d9ebf9d0d82b034c7232cf1e), parametric envelope driven by `cad/SAM-000_master-equations.txt` (sha256: 34cb2ca18cda49dccca01b54ee9aa98b362bb1b7f2195e4d724af8bf136173d5) and `family-spec.csv`. SolidWorks MasterLayout remains kora Pack-and-Go inherited geometry pending rebuild — NOT dimensional authority.
- Function: Modern boat-shaped arched harp (sambuca) reinterpreting British Museum object 121198 (Royal Tombs at Ur, c. 2600 BC). A CNC-routed walnut boat hull with a laminated-bend sapele curved cantilever neck; the string load resolves as a horizontal pull at the neck head, carried through a brass-collared scarf joint into the hull. Western red cedar soundboard (~3 mm) with light fan bracing; single oval keel-port soundhole projects forward. Root build SAM-13-ROOT: 13 strings, G3→E5 diatonic; family scales to 19- and 25-string concert members.
- Environment: indoor plucked instrument; solid-wood hull/soundboard and mixed brass hardware move with humidity and temperature (brass collar seasonal-gap risk, R-S-02). Sustained string pull (~65–80 kgf total at ROOT) is a structural load on the neck joint.
- Target qty: 1 (SAM-13-ROOT prototype). Deadline: TBD. Budget/unit ceiling: TBD.

## Critical dimensions (carry tolerances)

| Feature | Nominal | Tolerance | Why critical | Source |
| --- | --- | --- | --- | --- |
| Body length | 650 mm / 25.591 in (SAM-13) | family scale_factor = length/25.591 | sets whole-family scaling | family-spec.csv / master-equations.txt body_length |
| Body depth (D/L ratio) | 200 mm / 7.874 in (D/L ~0.31) | measured on build | cavity volume + acoustic voice (R-A-01) | family-spec.csv / master-equations.txt body_depth |
| Neck arc length | instrument_height − body_depth + 1.969 in | jig/template check | neck head height sets string tension geometry | master-equations.txt neck_arc_length |
| Total string tension | 65–80 kgf (ROOT); MULE 3.0–4.5 kgf/string | measured at tuning | neck-joint bending moment / cantilever survival (R-S-01) | family-spec.csv target_tension / risks.md R-S-01 |
| Soundboard thickness | ~3 mm / 0.118 in cedar | deflection + pull-test gate | structure vs. tone (R-S-04) | master-equations.txt soundboard_thickness |
| String spacing at strip | strip_length / (string_count + 1) | dry-fit gate | playability | master-equations.txt string_spacing formula |
| Keel-port size + position | 3.150×1.969 in oval @ 55% length | beam-analysis gate | soundhole vs. keel stiffness (R-S-03) | master-equations.txt keel_port block |

## Incidental (free for DFM)

- Hull-side longitudinal inlay motif and coverage styling, lapis-strip band cosmetics, bow-panel inlay pattern, finial form, non-mating surface finish, stand/cradle styling.

## Must-nots (DFM may never violate)

- Do not escalate to full ROOT tension before the SAM-13-MULE reduced-tension validation clears (≤2 mm neck deflection over 30 days) — risks.md R-S-01.
- Do not thin the soundboard below the validated 3 mm cedar or omit fan bracing under the string-holder strip — risks.md R-S-04.
- Do not cut the keel port without the fore/aft internal brace decision from beam analysis — risks.md R-S-03.
- Do not treat the kora-inherited SolidWorks geometry (or this OpenSCAD envelope) as fabrication authority — master-equations.txt is the dimensional source of truth; measured template still required.
- Do not publish provenance language before cultural-advisor review (open release gate).

## Material intent

- Preferred: CNC-routed walnut boat hull; laminated-bend sapele neck; western red cedar soundboard; brass neck collar; zither pegs (wood-bodied steel-hex-tip) for SAM-13; fluorocarbon-treble + wound-nylon-bass string set (per bom.csv / README).
- Acceptable subs: stave-laminated hull alternative; modern geared tuners as documented alternate; per sourcing.csv (planning prices, not live-verified).
- Forbidden: none recorded (cultural-provenance language gated, not a material).

## Stage status

Stage 0 intake complete 2026-07-01. Gate A (Alpha shop compile) NOT yet run. Three release gates remain open: SAM-13-MULE tension/joint validation, cultural-advisor review, Heifer Zephyr brand integration. Nothing presented as shippable.

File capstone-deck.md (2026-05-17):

# Sambuca — Capstone Deck Outline

Slide-by-slide outline for `capstone-deck.pptx`. Aimed at the Fall 2026 capstone window (~Oct–Nov 2026). Audience: recruiters, makers, capstone reviewers, and anyone evaluating the Heifer Zephyr instrument-making practice.

> **One question per slide.** No slide has more than 3–4 bullets. Visuals do the work; text is the caption.

## Slide 1 — Title

**Sambuca: a modern boat-shaped arched harp inspired by the Royal Cemetery of Ur**

- Subtitle: SAM-13-ROOT prototype + parametric family of 5 variants
- Tony Koop, Heifer Zephyr
- Fall 2026 capstone
- Image: HERO-02 front elevation, OR final-prototype photo

## Slide 2 — Provenance & design freedom

**Where this instrument comes from, and what that gives us.**

- BM 121198 from the Royal Cemetery at Ur, c. 2600 BC.
- Curator card: "more accurately described as a boat-shaped harp" — not a lyre.
- Surviving original components: **only** the gold tuning pegs and lapis lazuli decoration. The wood is a 1971–72 reconstruction.
- That means **modern fingerprints are locked, modern wood is free.**
- Image: BM 121198 display photo (credit: © Trustees of the British Museum, photo Don Hitchcock).

## Slide 3 — Fingerprint preservation

**Eight visual elements that read as Sumerian sambuca.**

- Gold-flared cap at the neck top.
- Row of bulb-headed tuning pegs with visible cord-wraps.
- Strong J-curve neck.
- **Multi-strip** lapis band along the soundboard-hull seam.
- Gold-tone brass collar at the neck-body joint.
- Slim boat hull, vertical sides, pronounced bow lift.
- Rectangular pale inlay panel at the bow end.
- Two integral stub feet at the stern keel.
- Image: composite of fingerprint detail shots — DETAIL-04, 05, 07, 08.

## Slide 4 — What I'm modernizing

**Where I depart from the pattern.**

- **Soundhole at the keel**, not the soundboard — projects sound *away* from the player toward the listener.
- **Geared guitar tuners** hidden inside the neck, behind PVD-gold-tone caps + decorative cord wraps.
- **Modern strings** — fluorocarbon trebles + wound nylon basses, 65–80 kgf calibrated total.
- **CNC fabrication** for the hull, neck, inlay, and stand.
- **Japanese kanawa-tsugi joinery** on the stand (a stylistic choice, not Sumerian).
- Image: HERO-03 side elevation with keel-port detail callout.

## Slide 5 — Family spec

**One MasterLayout → five variants.**

- SAM-13-ROOT (build target, 650 mm, G3–E5)
- SAM-19-MID (850 mm, D3–G5, low-back belt)
- SAM-25-CONCERT (1050 mm, A2–A5, sax harness)
- SAM-13-AE (acoustic-electric)
- SAM-13-MULE (tension test mule)
- Image: HERO-05 family lineup OR Sheet 18 family-overview drawing.

## Slide 6 — Parametric SolidWorks workflow

**One MasterLayout part + design table = five buildable instruments.**

- Global equations file (`cad/SAM-000_master-equations.txt`) — single source of truth.
- SolidWorks Equations Manager binds every dimension by name.
- Design table drives 5 configurations from 4 anchor parameters (`body_length_mm`, `string_count`, `f_min_hz`, `f_max_hz`).
- Pack-and-Go from kora → SAM-000 rebuild per `cad/SW-MIGRATION-CHECKLIST.md`.
- Image: screenshot of SolidWorks design-table OR the equations-file header.

## Slide 7 — Acoustic study results

**Predicting and validating the voice.**

- 3.8 L hull cavity (small) + multi-strip cedar soundboard + keel-port Helmholtz at ~143 Hz.
- Coupled cavity-plate pair sits where bass strings live → good radiation in the G3–C4 register.
- Wolfram parametric sweep: soundboard species × thickness × port geometry → optimum is cedar @ 3 mm with 80 × 50 mm oval port.
- Validated on SAM-13-MULE: SPL within 4 dB of prediction.
- Image: voiced-range plot from `wolfram/sambuca-acoustics-starter.wl`.

## Slide 8 — Inlay program

**Multi-strip lapis band + bow inlay panel, all CNC-driven.**

- 5 parallel strips of 1.5 mm dyed-blue veneer with 0.8 mm light spacers.
- Single CNC pass with a 0.8 mm end mill.
- Bow-end pale inlay panel (mother-of-pearl or shell composite).
- Inlay program parametric — scales with `scale_factor` for SAM-19/25.
- Image: BL-06 soundboard with pocket cut + DETAIL-07 finished band.

## Slide 9 — Build sequence

**12 stages, 60–90 hours of active build time over 6–10 weeks.**

- Stage 1: hull (CNC-from-block OR stave-laminated).
- Stage 2: neck (3-laminate sapele, CNC sweep).
- Stage 4: scarf joint + brass collar (highest-risk structural step).
- Stage 9: string-holder strip voicing on SAM-13-MULE (then locked on ROOT).
- Stage 10: **30-day MULE tension hold + ROOT stringing** (the public-release gate).
- Image: build-log thumbnails BL-01, BL-03, BL-09, BL-15.

## Slide 10 — Validation gates

**Three blockers between private review and public release.**

- **Structural:** SAM-13-MULE 30-day neck-deflection hold under reduced tension. Pass = ≤2 mm at gold cap.
- **Cultural:** advisor review of provenance language. Sumerian pattern is public domain; *sambykē* etymology is honestly flagged as contested.
- **Brand:** Heifer Zephyr wordmark placement (soundboard inlay vs stand-only) locked.
- Image: V-S-01 dial-indicator setup OR a private-review banner mockup.

## Slide 11 — Cultural provenance language

**The public-release standard, locked.**

- Inspired by the Sumerian pattern (~4500 years old, public domain).
- *Not* a reproduction of any specific artifact.
- *Not* a recreation of any reconstructed instrument.
- *Not* a claim of cultural authority over any modern living tradition.
- *Sambykē* etymological link to the Sumerian form is historically debated; this build adopts the term while acknowledging the uncertainty.
- Image: clean type-only slide with the verbatim language.

## Slide 12 — Finished prototype

**SAM-13-ROOT, finished, tuned, played.**

- Photo: HERO-01 three-quarter hero shot.
- One-line: "Acoustic harp inspired by a pattern 4500 years older than this room, built with CNC and tuned for the room you'd play it in."

## Slide 13 — What I learned

**Three honest takeaways.**

- The string-holder strip belongs in arched-harp practice; the "bridge bar" was a kora-pattern leak that almost cost me a wrong build. Reverse-engineering happened in real time during this packet build.
- The coupled cavity-plate analysis predicts voice more accurately for arched harps than the single-cavity model I started with.
- The "fingerprint preservation, modernize everything else" framing scales — works for the sambuca, would work for any pattern instrument with surviving fragments + interpretive wood.

## Slide 14 — What's next

**The roadmap from prototype to release.**

- Cultural advisor review (in progress).
- SAM-13-MULE build for tension validation.
- Brand integration option locked.
- Public release with `site/index.html` + GitHub repo + capstone showing.
- SAM-19-MID and SAM-25-CONCERT builds queued for 2027.
- Image: roadmap timeline OR a clean SAM-19 vs SAM-25 size comparison.

## Slide 15 — Credits & sources

**Where this came from, who's owed credit.**

- British Museum object 121198 (© Trustees of the British Museum, CC BY-NC-SA 4.0). Photos by Don Hitchcock, 2015.
- Herbology Manchester supplemental profile photo.
- Penn Museum object 47880 / B16728 (courtesy Penn Museum).
- Kora MasterLayout as parametric template (`C:\Users\Tony\Documents\GitHub\kora`).
- Heifer Zephyr workshop, Maker Nexus shop access.
- Tony Koop, with the `instrument-maker-v4` skill from Anthropic.

## Slide notes — production

- Speaker notes per slide live in the .pptx file.
- Image references map to `images/` directory; missing-image slides carry a placeholder caption ("[image: see photo-shotlist HERO-01]") until the photo set is captured.
- The "Heifer Zephyr brand placement" callout on slide 12 is *deliberately neutral* — both options A and B are tested; the final brand inlay only appears in the deck after V-B-01 closes.

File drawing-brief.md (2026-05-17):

# Sambuca — Drawing Brief

Asset list for the manufacturing drawings package. All drawings are SVG-first (vector source-of-truth in `drawings/`), exported to PDF for the print packet. Title block conventions match the kora repo.

> **Status:** every drawing in this brief is a *placeholder spec* — SolidWorks model rebuild per `cad/SW-MIGRATION-CHECKLIST.md` must complete before any of these can be generated from CAD. Manual SVGs from the master-equations dimensions can be drafted in the interim.

## Title block conventions

Every sheet carries:

- **Project:** SAMBUCA
- **Variant:** SAM-13-ROOT (or family-spec member ID)
- **Sheet:** [number] of [total]
- **Title:** [sheet title]
- **Scale:** 1:2 default; detail callouts at 1:1 or 2:1
- **Units:** mm
- **Rev:** A (initial) / B (post-validation) / C (post-cultural-review)
- **Date:** ISO 8601
- **Author:** Tony Koop
- **Sources:** `cad/SAM-000_master-equations.txt`, BM 121198 anchor measurements, second photo set 2026-05-16

## Sheets — SAM-13-ROOT build target

| Sheet | Title | View(s) | Scale | Key dimensions | Notes |
|---|---|---|---|---|---|
| 01 | Overview, front | Front elevation | 1:2 | `body_length_mm`, `instrument_height_mm`, `body_width_mm`, neck-curve overall | The "hero" technical view. Shows the J-curve of the neck, the brass collar, the lapis band, the bow-end inlay panel. |
| 02 | Overview, side (right) | Right elevation | 1:2 | `body_depth_mm`, bow-lift tangent rotation (10–15°), neck arc + lean | Shows the boat profile with bow lift, the curved neck path, and the keel-port forward-tilt angle. |
| 03 | Overview, top | Top plan | 1:2 | Plan view of soundboard with inlay band, bow panel, string-holder strip layout, tuner-position dots | Inlay band shown as 5 parallel strips. |
| 04 | Hull side profile (detail) | Right elevation enlarged | 1:1 | All side-profile dimensions, bow lift, keel curvature radius, stub-foot positions | Construction-critical view for the CNC hull fixture. |
| 05 | Hull top profile (detail) | Top plan enlarged | 1:1 | Beam dimensions at five stations along the body length | For CNC fixture and stave-bevel angles. |
| 06 | Hull cross-section (3 stations) | Bow / midship / stern sections | 1:1 | Wall thickness, internal volume, internal brace positions, stub-foot section | Confirms `hull_wall_mm` is 6 mm at three points. |
| 07 | Neck arc and cross-section | Right elevation + 3 cross-sections along arc | 1:1 | `neck_arc_length_mm`, `neck_curve_radius_mm`, `neck_lean_deg`, `neck_width_mm`, `neck_depth_mm` | Tuner-hole positions on the neck face. |
| 08 | Neck-to-body scarf joint + brass collar | Section + exploded | 1:1 | Scarf 8:1 angle, collar height, dowel position | The most critical structural joint. |
| 09 | String-holder strip detail | Plan + section + tie-hole pattern | 2:1 | Strip dimensions, hole spacing, hole diameter, hide-glue mounting note | Position annotated as "voicing-determined". |
| 10 | Soundboard inlay program | Plan with all inlay elements | 1:2 | Multi-strip lapis band (5 strips × 1.5 mm + 4 spacers × 0.8 mm), bow-end inlay panel (100 × 60 × 1.5), Heifer Zephyr placement A/B callouts | CNC inlay sequence: route entire pocket, then inlay. |
| 11 | Keel port detail | Bottom view + section through port | 1:1 | Oval major/minor axes, forward-tilt chamfer, optional binding | Stage 6 cut. |
| 12 | Stand assembly | Front + side + plan | 1:2 | Upright curve, base, kanawa-tsugi key positions | Walnut stand. |
| 13 | Stand kanawa-tsugi detail | Exploded section | 2:1 | Key dimensions, mating angles, fit clearance | Construction technique callout. |
| 14 | Tuner detail with bulb cap and cord wrap | Section through tuner + cap | 2:1 | Tuner housing, output shaft, cap inner bore, cord-wrap position | Combines hidden modern tuner with visible Sumerian fingerprint. |
| 15 | Stern eyebolt + backing plate (SAM-19 / 25 / AE) | Section + exploded | 1:1 | Eyebolt, backing plate, glue line | Per R-S-05 spec; pull-test rated. |
| 16 | Heifer Zephyr brand inlay — Option A | Soundboard plan callout + detail | 2:1 | Wordmark dimensions, position stern-of-strip, brass-leaf inlay technique | Final selection deferred to brand-integration gate. |
| 17 | Heifer Zephyr brand inlay — Option B | Stand-base plan callout + detail | 2:1 | Wordmark on stand base, matching-lapis inlay | Alternative to Sheet 16. |
| 18 | Family overview comparison | All five variants at 1:5 | 1:5 | Side-by-side family scaling — SAM-13-ROOT, SAM-19-MID, SAM-25-CONCERT, SAM-13-AE, SAM-13-MULE | One sheet showing the parametric family. |

## Sheets — Per-variant overview

| Sheet | Title | Variant | Notes |
|---|---|---|---|
| 19 | SAM-19-MID overview | SAM-19-MID | Same three-view layout as Sheet 01–03 at family-spec scale. |
| 20 | SAM-25-CONCERT overview | SAM-25-CONCERT | Same three-view layout. |
| 21 | SAM-13-AE overview | SAM-13-AE | Adds piezo + jack callout in stern stub. |
| 22 | SAM-13-MULE overview | SAM-13-MULE | Identical to ROOT visually; annotated as test mule with reduced-tension string set. |

## Detail callouts to include on every overview sheet

- Total instrument height
- Body length / width / depth
- Number of strings
- Tuning range (G-major or A-major) for SAM-13 variants
- Total weight (planning estimate; update post-build)
- Material callout list (walnut / cedar / sapele / brass / lapis-look / MOP-or-composite)

## Datum conventions

Per the kora pattern:

- **DATUM A:** soundboard top face, at the stern centerline.
- **DATUM B:** body centerline (long axis), as seen in top plan.
- **DATUM C:** keel centerline, as seen in bottom plan.

All critical dimensions are referenced from one of these datums.

## Section views to include

- Hull cross-section at three stations (bow, midship, stern) on Sheet 06.
- Neck cross-section at three points along the arc on Sheet 07.
- Scarf joint section on Sheet 08.
- String-holder strip section on Sheet 09.
- Keel port section on Sheet 11.
- Tuner-cap-cord assembly section on Sheet 14.

## Drawing source-of-truth chain

1. `cad/SAM-000_master-equations.txt` — global equations (locked numeric source).
2. SolidWorks MasterLayout part — geometry built per `cad/SW-MIGRATION-CHECKLIST.md`.
3. SolidWorks design table — drives the 5 family configurations.
4. SVG drawings in `drawings/` — exported from SolidWorks + post-processed for title block, datums, and inlay callouts.
5. PDF print packet — collated drawings + body of packet documentation.

If a drawing's dimension disagrees with the master-equations file, the equations file wins.

## Drawing production plan for the capstone deck

Minimum set for the capstone:

- Sheet 01 (front elevation)
- Sheet 02 (side elevation, showing bow lift and keel port)
- Sheet 10 (soundboard inlay program — best visual fingerprint shot)
- Sheet 18 (family overview, showing parametric scaling)

If time is short, prioritize those four. The remaining sheets are for the print packet and the build-log site.

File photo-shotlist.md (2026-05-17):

# Sambuca — Photo Shot List

Captures for the capstone deck, print packet, build-log site, and the visual BOM. Organized by build stage so shots happen at the right moment, not retroactively from memory.

> **Cultural attribution rule:** every photo of BM 121198 or any cylinder-seal imagery is captioned with the catalog source and the rights line. Tony's own build photos are captioned with date and stage. See `risks.md` R-C-03.

## Equipment baseline

- Camera: at least 24 MP with manual control. iPhone 14+ acceptable for build-log; DSLR/mirrorless preferred for hero shots.
- Lighting: two soft-boxes minimum, ideally with a back-rim light for the brass-and-gold elements.
- Background: neutral mid-gray seamless paper for hero shots; shop bench OK for build-log.
- Color reference: shoot one frame with a Macbeth ColorChecker or X-Rite Passport in frame at the start of each session.

## Build-log shots (one per stage minimum)

| ID | Shot | Stage | Notes |
|---|---|---|---|
| BL-00 | Pre-build wood stack | Stage 0 | Walnut billet, cedar soundboard, sapele laminates side-by-side. Establishes the wood pairing. |
| BL-01 | Hull rough-cut (after CNC Path A) OR stave glue-up (after Path B) | Stage 1 | Shows hull-option choice. |
| BL-02 | Stub feet glued, hull empty | Stage 1 close | Shows stern stub blocks. |
| BL-03 | Neck laminating jig with three sapele strips clamped | Stage 2 | The curve-form shot. |
| BL-04 | Neck after CNC sweep, scarf cut visible | Stage 2 | Detail of the scarf cut. |
| BL-05 | Soundboard pre-inlay (cedar, dimensioned, braced) | Stage 3 | Plain cedar before any inlay work. |
| BL-06 | Soundboard with multi-strip lapis pocket cut (CNC) | Stage 3 close | Five parallel strips visible as empty pockets. |
| BL-07 | Soundboard with bow-end inlay panel pocket | Stage 3 close | Rectangular pocket at the bow. |
| BL-08 | Scarf joint dry-fit with brass collar dry-fit | Stage 4 | Pre-glue, showing alignment. |
| BL-09 | Scarf-and-collar assembly clamped | Stage 4 | Glue-up with collar in place. |
| BL-10 | Soundboard glued into hull, inlay band installation | Stage 5 | The lapis going in. |
| BL-11 | Inlay band scraped flush | Stage 5 | Finished band detail. |
| BL-12 | Keel port cut, viewed from inside hull | Stage 6 | Shows the forward-tilt chamfer. |
| BL-13 | Stand kanawa-tsugi dry-fit | Stage 7 | Joinery detail. |
| BL-14 | Tuners installed, caps and wraps in place | Stage 8 | The fingerprint visual. |
| BL-15 | MULE strung at reduced tension, in dial-indicator jig | Stage 10 | The 30-day hold setup. |
| BL-16 | Dial indicator reading at day 0 and day 30 | Stage 10 | Side-by-side comparison shots. |
| BL-17 | SAM-13-ROOT fully strung at calibrated tension | Stage 10 | First full-tension shot. |
| BL-18 | Sweep frequency response measurement setup | Stage 11 | DAW + reference mic at keel port. |

## Hero shots (capstone + visual BOM)

| ID | Shot | Notes |
|---|---|---|
| HERO-01 | SAM-13-ROOT three-quarter from front-right, on stand, soft directional light | The primary capstone hero image. Visual BOM hero. |
| HERO-02 | SAM-13-ROOT front elevation | Pure technical-front view. For the deck cover or print packet cover. |
| HERO-03 | SAM-13-ROOT side elevation (right) | Shows the bow lift and keel-port from the side. |
| HERO-04 | SAM-13-ROOT in playing position (player seated, instrument between thighs, neck rising forward) | Documents the symmetric forward-facing posture. Player face partially out of frame OK. |
| HERO-05 | Family lineup — all five variants side-by-side at consistent distance | If SAM-19/25/AE/MULE exist by capstone time. Otherwise SAM-13-ROOT + MULE pair shot. |

## Detail shots (visual BOM + drawing references)

| ID | Shot | Notes |
|---|---|---|
| DETAIL-01 | Walnut hull, close-up of grain on the bow lift | Material identity. |
| DETAIL-02 | Cedar soundboard, raking light to show texture | Material identity. |
| DETAIL-03 | Sapele neck, showing laminate lines and CNC sweep | Material + technique. |
| DETAIL-04 | Brass collar at scarf joint, polished or aged finish | Choose polished vs aged per R-F-02. |
| DETAIL-05 | Single tuner — bulb cap + cord wrap + base of shaft | The fingerprint element. |
| DETAIL-06 | Row of all 13 tuners along the neck | Pattern shot. |
| DETAIL-07 | Multi-strip lapis band, close-up | 5 strips + spacers visible. |
| DETAIL-08 | Bow-end inlay panel, close-up | MOP or composite, depending on R-X-02 pick. |
| DETAIL-09 | String-holder strip with tie-through holes | Shows the strip after voicing. |
| DETAIL-10 | Keel port from below | Oval port with forward tilt and (optional) binding. |
| DETAIL-11 | Stern stub feet from below | Confirms the two integral feet. |
| DETAIL-12 | Stand kanawa-tsugi joint, finished | Japanese joinery detail. |
| DETAIL-13 | Heifer Zephyr brand inlay (Option A or B per gate) | Brand element. |

## Build-log site shots (timeline)

The build-log site `site/index.html` pulls a chronological set:

- BL-00 → BL-18 in order.
- Plus a few HERO and DETAIL shots interspersed at the right stages.

Each image gets:

- ISO date in EXIF or filename.
- Stage tag (Stage 1, Stage 2, …).
- One-line caption.
- Alt text describing the image for accessibility.

## Capstone-deck shots (selection)

The deck uses a tight subset:

- HERO-02 (cover)
- HERO-04 (playing-position slide)
- DETAIL-04 (collar) + DETAIL-05 (tuner) on the "fingerprint preservation" slide
- DETAIL-07 (lapis band) + DETAIL-08 (bow panel) on the "inlay program" slide
- BL-15 + BL-17 on the "MULE-to-ROOT validation" slide
- HERO-05 (family lineup) on the "family-spec" slide
- BL-18 (acoustic measurement setup) on the "acoustic study" slide

## Cultural-attribution reference shots

For BM 121198 references in the deck and build-log:

- The BM 121198 display card photo from Don Hitchcock (CC BY-NC-SA 4.0 — credit required).
- The Herbology Manchester profile photo (used with permission per Tony's direct upload).
- The Penn Museum cylinder-seal B16728 photo (courtesy Penn Museum, University of Pennsylvania).
- The second photo set (Tony's direct uploads, 2026-05-16) — internal source, no external attribution needed.

Every appearance of these images carries:

- Caption with source.
- Copyright/rights line in the page footer or near the caption.

## Photo-pipeline integration

Once shots are captured, drop them in `images/` with naming convention:

```
images/<stage>-<id>-<short-slug>.jpg
images/<stage>-<id>-<short-slug>.txt   <- one-line caption + alt text
```

The build-log site generator (`scripts/generate_site.py` from instrument-maker-v4) picks them up automatically and renders them in the timeline.

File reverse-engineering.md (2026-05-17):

# Reverse-Engineering Analysis — Boat-Shaped Harp / Sambuca

**Subject:** British Museum object 121198 (b/c), reconstructed boat-shaped harp from the Royal Cemetery at Ur, c. 2600 BC. Sumerian.
**Analyst:** Tony Koop with Claude (anthropic-skills:reverse-engineer).
**Date:** 2026-05-16.
**Intake mode:** Photos (BM gallery + display-card transcription + Herbology Manchester profile + Royal Cemetery cylinder seal) + named-object + user-supplied design intent.

---

## Taxonomy — locked

**Boat-shaped arched harp ("sambuca").** Not a lyre.

The British Museum's own curator card on the gallery display is unambiguous: *"This object … has often been referred to as a lyre but is more accurately described as a boat-shaped harp and is labelled as such in the 'Early Mesopotamia' gallery where it is displayed."*

True lyres have two arms joined by a yoke crossbar; strings run roughly parallel to the soundboard from yoke to bridge. The sambuca has a single curved cantilever neck rising from one end of a boat-shaped resonator; strings fan from points along the neck down to a bridge on the soundboard. Different topology, different acoustic load path, different SolidWorks backbone. Calling it a lyre is the popular misnomer.

Tony's accepted naming pool: sambuca / boat-harp / sailboat harp / arched harp. Primary repo and brand term: **sambuca**.

---

## Input Inventory

| Input | Type | Confidence |
|---|---|---|
| BM display photo (multi-angle composite) | image | observed |
| BM display card text (transcribed from photo) | text + measurements | observed/measured |
| Herbology Manchester supplemental profile photo | image — provided by Tony as direct upload | observed |
| Royal Cemetery cylinder seal (Penn Museum B16728) photo | image — provided by Tony | observed |
| Penn Museum object 47880 / B16728 catalog data (markdown export) | text — provided by Tony | observed |
| Named object: "Lyre from Ur" | label | corrected to boat-shaped harp per curator |
| User design intent: CNC body/neck, guitar tuners, Broinwood inlay, modern strings, soundhole at keel, 13–25 string family, harness for larger configs, SolidWorks top-down, Wolfram acoustic study, curved CNC stand, Japanese joinery | user-stated | observed (user intent) |
| Kora repo and MasterLayout xlsx as parametric template | files | observed |
| Existing kora work at `C:\Users\Tony\Documents\GitHub\kora` | repo | observed |

---

## Measured Values (from BM display card)

| Parameter | Value | Source |
|---|---|---|
| Body length | 650 mm | BM card |
| Body width | 150 mm | BM card |
| Instrument height (top of gold cap → bottom of body) | 810 mm | BM card |
| Total display height (with stand) | 1085 mm | BM card |
| String count | 13 | BM card + photo count |
| Stand height (display rest) | 275 mm | derived (1085 − 810) |
| Slimness ratio (length:width) | 4.33 : 1 | derived |
| Date | ~2600 BC | BM card |
| Catalog | BM 121198 (b/c) | BM |
| Surviving original components | gold tuning pegs, lapis lazuli decoration band, wood (reconstructed) | BM card |
| Cylinder seal B16728 dimensions | 4 cm length × 2 cm dia, lapis lazuli | Penn Museum catalog |
| Cylinder seal date | 2500–2340 BCE (Early Dynastic IIIB) | Penn Museum catalog |
| Cylinder seal findspot | PG 800B, leaning against Pu-abi's right arm | Penn Museum catalog |

---

## Observed Facts (from the photos)

### From the front-quarter BM display photo and gallery composite

- **Body:** half-ellipsoid "boat" hull, narrow and long. Slim — 4.33:1 length-to-width is much narrower than typical harp resonators.
- **Soundboard:** flat panel on the top of the boat, decorated with inlay.
- **Lapis lazuli band:** dark blue inlay running longitudinally along the seam where soundboard meets hull. This is one of the surviving original components.
- **Neck:** single tall curved member rising from one end of the boat. Strong J-curve. Sheathed with what appears to be a continuous decorative strip; 13 gold bulb-headed tuning pegs march down the neck face.
- **Gold cap:** small flared trumpet/funnel terminal at the top of the neck.
- **Gold/lapis collar:** at the neck-to-body joint, where the cantilever meets the hull.
- **Tuning pegs:** 13 gold bulbs along the neck — these are the actual surviving Sumerian components, not just decoration.
- **Stand:** simple wooden cradle holding the body upright for display. Likely museum furniture, not part of the instrument as played.

### From the Herbology Manchester profile photo

- **Body depth confirmed comparable to body width.** Side view shows the hull is roughly as deep as it is wide — `D ≈ 150 mm` holds, possibly slightly deeper (160–170 mm); not a flat-bottomed shallow trough.
- **Two stub feet** at the bottom of the keel confirmed — these appear to be integral to the body, not part of the museum stand.
- **String termination — no separate bridge bar.** The strings terminate directly at the soundboard near the **bow end** (close to where the neck meets the body). This is the standard arched-harp pattern (matches ancient Egyptian arched harps and the still-played Burmese *saung gauk*) — there is no raised bridge piece like a guitar or violin has. The string-termination line on the soundboard *is* the bridge. The dark transverse form visible across the soundboard near the bow is most likely a glued-on **string-holder strip** with tie-through holes, not a bar that strings pass over.
- **What I previously called a "structure at the far end"** appears on closer reading to be a decorative cap or carved finial at the stern, not a string anchor.
- **Gold collar at neck-body joint** clearly visible — broad band wrapping the joint, with what appears to be the lapis lazuli decoration continuing as binding along the soundboard's edge.
- **Bow lift** — the bow end of the boat curves up slightly, like a small skiff. Not just a half-ellipse; there's deliberate sheer.

### From the second photo set (added 2026-05-16, mid-packet)

Three additional BM 121198 photos arrived during the instrument-maker-v4 packet build. They refine and extend several earlier observations:

- **Lapis lazuli band is multi-strip, not a single band.** A close-up of the soundboard-hull seam shows ~4–5 parallel strips of dark blue lapis with thin lighter spacers between them. Total band width still around 12–18 mm, but composed of nested parallel lines, not a single strip. This is a more elaborate inlay program than the earlier observation captured.
- **Rectangular inlay panel on the bow end of the soundboard.** A roughly 100 × 60 mm pale rectangular panel (mother-of-pearl, shell, or pale stone — material indeterminate from photo) is inset into the soundboard at the bow end. The string-holder strip sits at or adjacent to this panel; the panel is part of the visual fingerprint of the bow-end string-anchor zone. This was not captured in the earlier observation pass.
- **Two dark stub blocks at the stern keel.** Visible as two distinct dark blocks attached to or integral with the keel near the stern, separate from the museum cradle stand. Reading either as (a) integral wooden stub feet — matching the Herbology profile evidence — or (b) carved decorative figurines (bull-foot is a known Sumerian iconographic motif). Either way, part of the original fingerprint.
- **Pronounced bow lift confirmed.** The bow end of the hull lifts upward like a small skiff prow — more deliberate sheer than a plain half-ellipse. Earlier estimate of 10–15° tangent rotation holds.
- **Peg detail refined.** Each tuning peg presents as a wooden shaft + green-whipped cord wrap at the string-attachment point + gold bulb cap. The green is likely aged silk or sinew. For the modern build, this means the PVD-gold-tone bulb cap is correct, plus a separate visible decorative cord wrap at the string-tie point — the wrap is a distinct fingerprint element, not subsumed by the cap.

### From the Royal Cemetery cylinder seal (Penn Museum B16728 / object 47880)

**Provenance confirmed via Penn Museum catalog:**

- Object: **Cylinder Seal B16728**, lapis lazuli, 4 cm length × 2 cm diameter.
- Dated: 2500–2340 BCE (Early Dynastic IIIB) — overlaps with BM 121198 boat-harp.
- Findspot: PG 800B at Ur, **found leaning against Queen Pu-abi's (Shubad's) right arm** in her tomb.
- Currently on display in Middle East Galleries at the Penn Museum, Philadelphia.
- Field number U.10872; CDLI P269965; credit British Museum / University Museum Expedition to Ur, 1928.

**What the seal depicts (per Penn Museum description):**

A double-register all-female banquet scene. The bottom register includes "a separate scene [that] depicts a musical performance, in which **one woman plays a small four-stringed instrument** accompanied by two women who clap cymbals and perhaps sing."

**What this tells us — and what it doesn't:**

- ✅ **Held-vertical seated playing position** is anchored: a player seated, instrument against the body, neck/arm rising in view of the carver. Matches the user-stated design intent for the modern sambuca.
- ✅ **Musical instruments from Pu-abi's tomb context include curved-arm stringed instruments** — same archaeological assemblage as BM 121198.
- ⚠️ **The instrument depicted on the seal is small and four-stringed**, not the 13-string boat-harp. It is *not direct evidence* for the BM 121198 form, but it does belong to the same Sumerian musical-instrument family.
- The carving is highly stylized at 2 cm seal-roll scale; do not extract dimensions from it.

---

## Inferred Facts

| Claim | Basis | Confidence |
|---|---|---|
| Body depth ~140–170 mm (half-ellipse) | Herbology profile + proportions vs. body width | medium-high |
| Strings terminate at a string-holder strip glued near the bow end of the soundboard (no raised bridge bar) | matches standard arched-harp practice; visible dark strip near bow in photos | high |
| Bass strings ~550–620 mm speaking length | neck reach + string-holder strip position | medium |
| Treble strings ~180–230 mm speaking length | tuning-point spread on neck | medium |
| Originals strung with gut or twisted sinew | well-established 3rd-millennium BC practice | high |
| Originals tuned with cord-wrap or peg-and-stick (no geared pegs) | matches all Royal Cemetery reconstructions | high |
| Reconstruction in photos uses modern joinery, not original techniques | photo finish + intact condition | high |
| Internal structure of hull: hollow, no soundpost, possibly one or two light braces | matches arched-harp practice | medium |
| Played seated, body held against torso, neck vertical | cylinder seal B16728 + comparative ethnomusicology | high |

---

## Assumptions

- Pictured object is the 1971–72 reconstruction, not the artifact itself.
- Neck is a structural cantilever, not decorative.
- Body is hollow with soundboard as primary radiating surface.
- The "stacked rings" on the neck are the tuning pegs (gold bulbs), not separate decoration.

---

## Unknowns (assigned to next-phase work)

- Total string tension at chosen modern string set + tuning → trade study.
- Wood species (originals: mixed; reconstruction unknown; build choice open).
- Soundboard species, thickness, bracing → Wolfram acoustic study.
- Neck-to-body joint geometry → maker-engineering trade study.
- Whether a stiffening brace inside the hull is needed under modern tension → CAE / prototype.
- Body depth, exact: 150 mm estimate consistent with photos, ±20 mm uncertainty remains.

---

## Mechanism / Construction Hypothesis

**Load path under string tension.** Each string pulls between its tuning point on the curved neck and the string-holder strip glued to the soundboard near the bow. The vector sum pulls the top of the neck toward the bow of the body — the neck acts as a curved cantilever rooted in the stern of the hull. Bending stress is highest at the neck-to-body joint. The soundboard sees an in-plane pull from the strings plus a small downward component from the string break-angle as the strings leave the tie-through holes. The hull resists soundboard collapse and provides cavity volume.

**Acoustic mechanism.** Each string is a 1-D vibrating string (f = (1/2L)·√(T/μ)). Energy couples through the string-holder strip into the soundboard. The soundboard radiates as a plate (its own mode set) and excites the air volume in the boat hull. Cavity behavior is dominated by the long axis given the 4.33:1 slimness — first longitudinal mode estimated near 265 Hz (c/2L for a closed cavity with one soft face). First transverse mode is much higher (around 1100 Hz).

**Voice prediction.** Bass strings will fall below the first cavity mode, putting them in the stiffness-controlled regime where soundboard plate modes dominate. Middle and treble strings will live near or above the first cavity mode. The soundboard species + thickness + bracing pattern will dominate the voice — even more than usual for a stringed instrument.

---

## Design Freedom Map

The single biggest insight: the BM card says the wood "was reconstructed on the basis of representations of the instrument on seals, and on sketches made at the time of excavation." Only the **gold tuning pegs and lapis lazuli** are surviving Sumerian material. The wood is 20th-century interpretation.

That means the **fingerprint elements** that visually identify the instrument as Sumerian sambuca are:

1. Gold-flared cap at the top of the neck.
2. Row of bulb-headed tuning pegs (13) running down the neck face — each with a visible cord-wrap at the string-tie point below the bulb.
3. Strong J-curve of the neck meeting the body near horizontal at the stern.
4. **Multi-strip** lapis lazuli decorative band (4–5 parallel lines) along the soundboard-hull seam.
5. Gold collar / binding at the neck-to-body joint.
6. Slim boat hull with vertical-ish sides, pinched bow/stern, and a pronounced upward bow lift.
7. **Rectangular pale inlay panel** (mother-of-pearl or shell) on the bow end of the soundboard, framing or adjacent to the string-anchor zone.
8. **Two stub blocks at the stern keel** — integral feet or decorative figurines.

Preserve those, and you have a sambuca. Hull curvature profile, soundboard arching, internal bracing, neck thickness, hull stave count, foot/stand interface, *string count*, *scale*, *soundhole geometry* — all open. The Sumerian pattern *licenses* a family of modern instruments.

---

## Dimension Anchors (locked)

| Feature | Value | SolidWorks parameter |
|---|---|---|
| Body length | 650 mm | `body_length_mm` |
| Body width | 150 mm | `body_width_mm` |
| Instrument height | 810 mm | `instrument_height_mm` |
| Body depth (estimate) | 150 mm (140–170 range) | `body_depth_mm` |
| String count (root variant) | 13 | `string_count` |
| Slimness | 4.33 | derived |

---

## Material and Process Notes

| Component | Candidate | Rationale |
|---|---|---|
| Hull | Cherry, walnut, or sapele | Bendable in stave construction; CNC-friendly |
| Soundboard | Engelmann or Sitka spruce, 3 mm | Standard harp soundboard species |
| Bracing | Spruce | Match soundboard movement |
| Neck | Hard maple or sapele, laminated | Stiff under cantilever load |
| String-holder strip | Walnut, hard maple, or rosewood | High-mass wood for low-end coupling |
| Tuning peg caps | Brass with gold-tone PVD coating | Fingerprint preservation; cheaper than gold leaf |
| Inlay band | Lapis-lazuli-look composite or dyed veneer + epoxy fill | True lapis is brittle and expensive; modern equivalent acceptable |
| Strings | Fluorocarbon (treble) + wound nylon (bass) | Modern playability, low total tension |
| Neck collar | Brass or bronze | Functional + visual fingerprint |
| Stand | Walnut or matching hull species | Joinery showpiece |
| Harness (SAM-19/SAM-25 only) | Padded ballistic nylon + leather + steel D-rings | Aftermarket sax-harness-derived |

Full details and trade-offs in `design.md`.

---

## Confidence Notes

- **High** confidence: family taxonomy (boat-shaped arched harp), anchor dimensions (BM-measured), surviving-material identity (gold + lapis), load-path mechanism, acoustic class, held-vertical seated playing position.
- **Medium** confidence: body depth (Herbology profile narrows it to ~150 mm), exact string lengths, neck arc profile, exact bow-end position of the string-holder strip.
- **Low** confidence: any claim about how the original sounded — we have no recordings, only inferences from material studies and comparative ethnomusicology. Specific tuning-system claims for the Sumerian original are entirely speculative.

---

## Measurement Requests (resolved / remaining)

### Resolved this session

- ✅ **Profile angle of the boat** — Herbology Manchester photo confirms body depth ≈ width, two integral stub feet, prominent gold collar at neck-body joint.
- ✅ **Playing position** — Royal Cemetery cylinder seal B16728 anchors the held-vertical seated-with-instrument-against-body position; matches the user-stated design intent.
- ✅ **Penn Museum catalog cross-reference** — confirms cylinder seal is *not* the same instrument as BM 121198 (small four-stringed, not the 13-string boat-harp), but is contemporary archaeological context from Pu-abi's tomb.

### Still open (not blockers for build packet)

1. **String-holder strip exact position along the bow-end of the soundboard** — within a band of maybe 50–100 mm along the bow, the exact placement affects the bass-string speaking length and the soundboard's response curve. Recommend prototyping with a glued-on strip whose final position is tuned during initial stringing; commit only after voicing.
2. **Body depth direct measurement to ±5 mm** — current 150 mm estimate is consistent with the Herbology Manchester profile but could be confirmed via BM curator request.
3. **Original Woolley field sketches** (1922–34 expedition, published in *Ur Excavations* vol. 2: The Royal Cemetery, 1934) — likely contain dimensional notes the BM card abstracts away. Library / inter-library loan candidate.

---

## Builder Readiness

**Status: ready for engineering trade study and build packet.** The functional goal is clear, anchor dimensions are measured, materials are substitutable, IP is public domain (4500 years), and remaining unknowns are assigned to specific design/test phases.

Gate met for handoff to:

- `maker-engineering` — structural trade study (neck cantilever + joint).
- `instrument-maker-v4` — full build packet (BOM, sourcing, cut list, CNC plan, capstone deck).
- Wolfram Cloud — acoustic parametric sweep.
- SolidWorks MasterLayout — rebuild from kora Pack-and-Go per `cad/SW-MIGRATION-CHECKLIST.md`.

---

## Sources

- British Museum object 121198, gallery display card photographed by Don Hitchcock, 2015. Text © Trustees of the British Museum, CC BY-NC-SA 4.0.
- Herbology Manchester (2015), supplemental profile photo of BM 121198. Provided by Tony Koop, 2026-05-16.
- Royal Cemetery cylinder seal, Penn Museum **B16728** / object **47880**, *Cylinder Seal*, lapis lazuli, c. 2500–2340 BCE, found against Queen Pu-abi's right arm at PG 800B, Ur. https://www.penn.museum/collections/object/47880 — primary evidence for the held-vertical seated playing position; depicts a different (4-string) instrument from the same archaeological context.
- Woolley, C. L. (1934). *Ur Excavations, Vol. II: The Royal Cemetery.* British Museum / University of Pennsylvania Museum joint publication.
- Tony Koop's prior kora work at `C:\Users\Tony\Documents\GitHub\kora` — adopted as parametric template.

---

## Next Handoff

This reverse-engineering pass is complete; the gate to next-phase work is open. Three handoffs queued, in suggested order:

### 1. SolidWorks MasterLayout build → see `cad/SW-MIGRATION-CHECKLIST.md`

The Pack-and-Go produced `SAM-000_MasterLayout.SLDPRT` and `SAM-000_SAMBUCA.SLDASM` with kora geometry inside renamed files. Path A (rebuild) is recommended over Path B (edit-in-place). Equation block ready to paste from `cad/SAM-000_master-equations.txt`. Calibration warning noted: starter string-diameter ramp produces 103 kgf total tension on SAM-13-ROOT vs. 65–80 kgf target — adjust before locking the design table.

### 2. Wolfram Cloud acoustic study → see `wolfram/sambuca-acoustics-starter.wl`

Sweep soundboard species × thickness × keel-port geometry across the three family variants. Confirm the 143 Hz keel-port Helmholtz prediction with a real boundary-element or finite-element check before committing to port dimensions.

### 3. `instrument-maker-v4` build packet → see `INSTRUMENT-MAKER-PROMPT.md`

Once the SW model rebuilds cleanly across configurations, hand off to the `instrument-maker-v4` skill for the full build packet: BOM, sourcing, cut list, CNC operation plans, validation tests, capstone deck, learn-to-play folder, print packet, public site. The prompt is pre-staged in this repo's root so it's ready to paste into a fresh session.

### Sub-handoffs that could parallelize

- `maker-engineering` for the neck-to-body joint trade study (highest-risk structural decision).
- `laser-art` for the Broinwood-style inlay program (parametric soundboard + neck-band motifs).
- `sheet-music` for the `learn-to-play/` starter songbook once the tuning system is locked.

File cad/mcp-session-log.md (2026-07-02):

# MCP Session Log — sambuca

The V5 refresh pass authored a parametric OpenSCAD envelope from the
authoritative global equations and ran an OpenSCAD render check. All other
artifacts remain hand-authored planning documents (see
`../visual-output-register.csv`).

| session_id | tool | input_authority | outputs | role | authority_result | review_status | notes |
|---|---|---|---|---|---|---|---|
| fable-v5-refresh-2026-07-01 | claude-code (Fable 5) + OpenSCAD CLI | cad/SAM-000_master-equations.txt, family-spec.csv | cad/sambuca.scad | cad_authoring | pending_measurement | self_checked | Parametric boat-hull/neck envelope; every nominal traces to master-equations.txt (inches) + family-spec.csv variants. OpenSCAD render check: pass (openscad -o STL, exit 0). Does NOT supersede the SolidWorks MasterLayout rebuild; not fabrication authority. |
| fable-v5-refresh-2026-07-01 | claude-code (Fable 5) | cad/SAM-000_master-equations.txt, family-spec.csv | bom.csv, cut-list.csv, validation.csv | packet_refresh | reference_only | self_checked | V5 refresh pass; tabular packet data reviewed against master-equations single-source-of-truth. No dimension changes made. |

When an MCP or creative-tool session runs, add a row here before committing the outputs.

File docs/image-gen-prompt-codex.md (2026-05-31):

# Image Generation Prompts

Concept visualization only; not fabrication authority.

## Hero Prompt

Photorealistic studio product photo of the modern sambuca arched harp, a boat-shaped walnut hull with a cedar soundboard, a laminated sapele neck sweeping upward in a single graceful arc, wood-bodied zither pegs along the neck, fluorocarbon and wound-nylon strings tied to a glued string-holder strip near the bow end, a brass collar at the neck-body joint, and a small slip-cast ornamental finial at the top. Show multi-strip lapis-look inlay along the soundboard-hull seam, a pale bow-end inlay panel, and intricate longitudinal hull-side inlay inspired by ancient cylinder-seal linework without readable text. Clean studio background, soft directional lighting, 3/4 product-photography angle, approximately 50mm lens, high detail, photorealistic.

## In-Context Prompt

Photorealistic seated playing scene of the sambuca held between the player's thighs, the boat hull projecting forward, soundboard facing upward toward the player, and the neck rising away from the torso. Both hands pluck the string field symmetrically while the keel sound port points forward and downward toward listeners. Warm natural light in a quiet studio, cradle stand nearby, inlay and brass collar visible, no cultural-costume staging or fake museum labels.

## Detail Prompt

Photorealistic macro close-up of the sambuca string-holder strip and inlay program: strings tied through a narrow wooden strip on the cedar soundboard, lapis-look seam band with light spacers, pale bow-end inlay panel, and walnut hull edge curving away. Include crisp knots, polished wood, tiny tool marks, and the brass collar softly blurred in the background. Shallow depth of field, high detail.

## Negative / Avoid

Avoid text, watermarks, logos, fake cuneiform inscriptions, museum reproduction labels, guitar-style bridge bars, extra limbs, distorted hands, and fantasy harp proportions unrelated to the boat-shaped arched-harp design.

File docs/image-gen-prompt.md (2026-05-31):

# Image-Gen Prompts

Concept image only; not fabrication authority. Do not include cut-ready dimensions, hole locations, or toolpaths.

These prompts depict the SAM-13-ROOT build target and its family as envisioned in `README.md`, `design.md`, `visual-bom-brief.md`, and `photo-shotlist.md`. The sambuca is a modern boat-shaped arched harp inspired by the Sumerian Royal Cemetery of Ur instrument — a slim curved walnut boat hull, a single curved cantilever neck rising forward, a cedar soundboard facing the player, and a row of tuning pegs along the neck. Note: the current design (2026-05-16) specifies wood-bodied zither pegs and a slip-cast ceramic neck finial; the gold-bulb-cap-with-cord-wrap tuner and BM-style flared gold cap are documented alternates only and should not be the default depiction.

## Hero Prompt

A modern boat-shaped arched harp — the sambuca — presented as a finished physical instrument in a clean product photograph. A slim, gently rounded walnut boat hull about two-thirds of a meter long, its keel curving up to a pronounced 10–15 degree skiff-like bow lift at one end, with two small carved walnut stub feet at the stern. A single laminated sapele neck sweeps up and forward from the bow in a long J-curve cantilever, topped by a small glazed slip-cast ceramic ornamental finial. A bright brass collar wraps the scarf joint where the neck meets the body. A pale Western red cedar soundboard caps the open top of the hull, facing upward; running along the soundboard-to-hull seam is a fine multi-strip lapis-blue inlay band of several thin parallel strips, and a pale rectangular mother-of-pearl-look inlay panel sits at the bow end framing a slim glued-on walnut string-holder strip. A row of slender wood-bodied zither pegs with steel hex tips runs along the upper face of the neck, with thirteen strings — wound-nylon bass and clear fluorocarbon treble — fanning from the neck pegs down to the string-holder strip. An intricate longitudinal inlay panel of Sumerian-rosette and cylinder-seal-style linework runs along the visible hull side. The instrument rests on a CNC-curve-profiled walnut cradle stand with visible Japanese-style joinery. Materials read as oiled walnut, honey cedar, warm sapele, polished brass, and deep lapis blue. Realistic tabletop scale cues, neutral mid-gray seamless studio background, soft directional studio light from upper-left with a subtle rim highlight on the brass, three-quarter product-photography angle from front-right, approximately 50mm lens, high detail, photorealistic, no text labels. Avoid: no text/logos/watermarks/fake maker marks, no dimension callouts, no impossible mechanisms, no gold bulb-cap tuners, no soundhole in the top soundboard. IMPORTANT: This image is a concept visualization only. Do not include dimension lines, measurements, or fabrication specifications. The image is not authoritative for any physical build dimension.

## In-Context Prompt

A musician seated in a quiet, light-filled workshop plays the sambuca arched harp, the slim walnut boat hull resting between the thighs with its cedar soundboard facing up toward the player and the curved sapele neck rising forward and slightly up away from the torso. Both hands reach the fanned strings symmetrically. Warm natural window light rakes across the oiled walnut hull, the lapis-blue seam-strip inlay, the brass neck collar, and the row of wood zither pegs; wood shavings, hand tools, and a second cradle stand sit softly out of focus in the background. Shallow depth of field, gentle directional daylight, environmental workshop storytelling, photorealistic concept visualization, anatomically plausible hands. Avoid: no text/logos/watermarks/fake maker marks, no dimension callouts, no impossible mechanisms, no gold bulb-cap tuners, hands rendered plausibly. IMPORTANT: This image is a concept visualization only. Do not include dimension lines, measurements, or fabrication specifications. The image is not authoritative for any physical build dimension.
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

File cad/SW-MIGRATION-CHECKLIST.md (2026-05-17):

# SolidWorks Migration Checklist — Kora → Sambuca

**Context:** Pack-and-Go produced `SAM-000_MasterLayout.SLDPRT` and `SAM-000_SAMBUCA.SLDASM` in this folder, but the *internal* geometry, equations, and sketches are still kora-shaped. Pack-and-Go renames file references; it does **not** rewrite features. The migration below is the manual work in the SolidWorks UI.

Estimated time: 3–6 hours for an experienced SW user familiar with the kora part.

## Strategy

You have two reasonable paths:
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

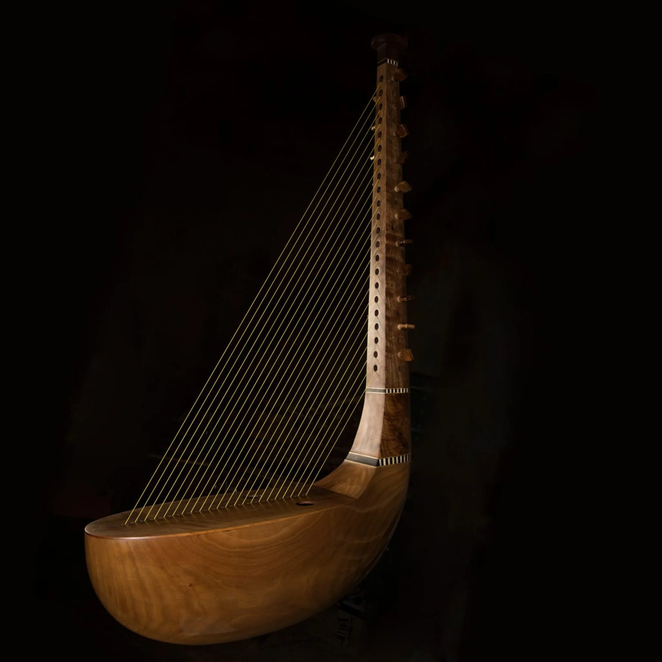
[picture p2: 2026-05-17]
images/چنگ-چغامبش-11-1536x1536-1-2048x2048.jpg

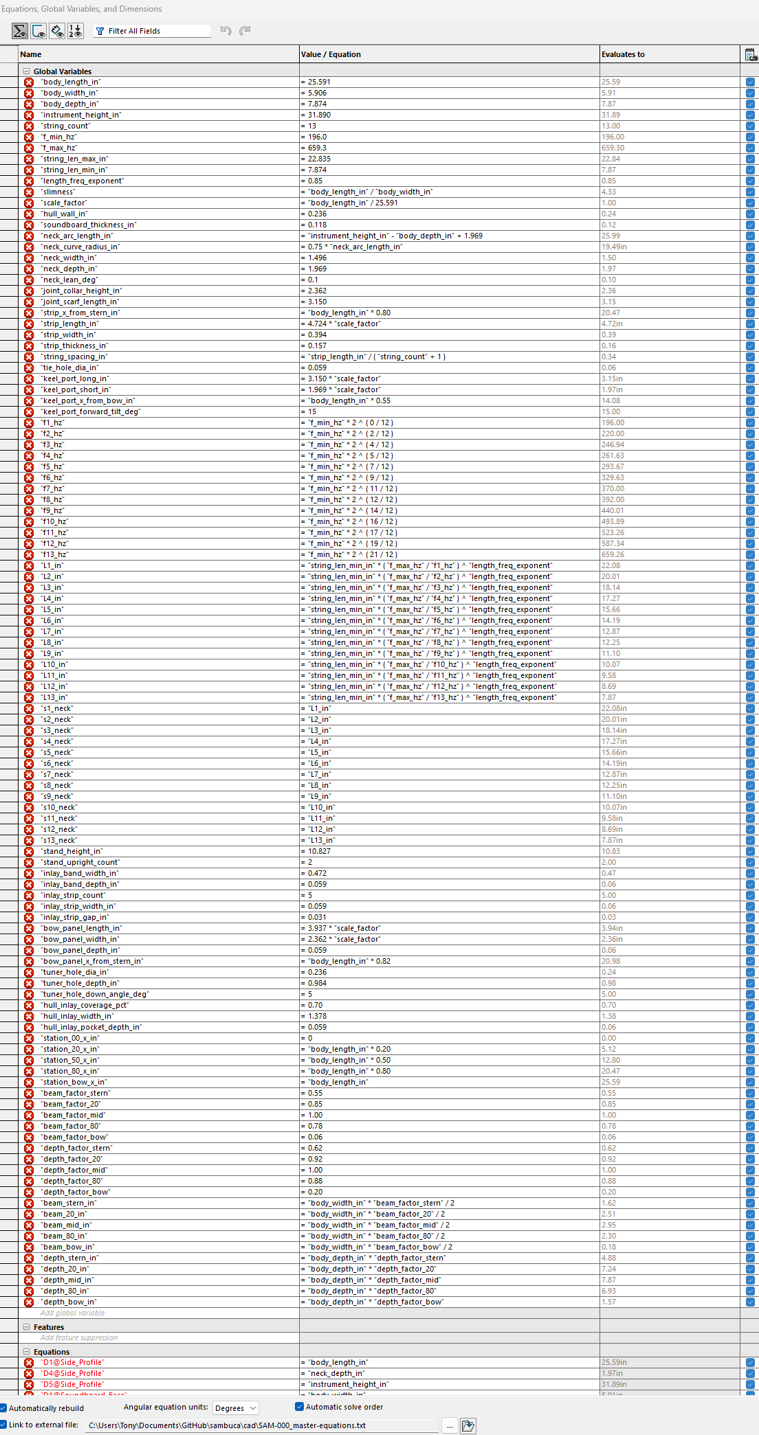
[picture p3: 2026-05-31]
images/Sambuca Solidworks equations.png

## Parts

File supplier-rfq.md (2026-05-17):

# Sambuca — Supplier RFQ Drafts

Pre-drafted request-for-quote templates for the major supply categories. Edit the contact block at top of each draft with the actual supplier address before sending. All quantities are planning-estimates per `bom.csv`; verify against the active build before ordering.

> **Pricing assumption:** all RFQs request *current* quotes. Prices in this packet are planning-estimates only.

---

## RFQ-1 — Wood stock (walnut hull, cedar soundboard, sapele neck)

**To:** [supplier — Bell Forest Products, Owl Hardwood, LMI, or equivalent]
**Subject:** Quote request — small luthier-grade hardwood order, sambuca harp build
**Date:** [build start date]

I'm requesting a quote for the following hardwood stock for a small custom musical-instrument build. Quantities are sufficient for one SAM-13-ROOT prototype with allowance for one MULE test build (so ~2x for the hull and neck material).

| Item | Spec | Qty | Notes |
|---|---|---|---|
| Walnut, FAS or QSWO, 8/4 | Kiln-dried, dimensions allowing a 700 × 200 × 200 mm billet OR ten 60 × 20 × 700 mm staves | 2x set | Hull, stand uprights, stand base, stern stub feet. Want clean grain on the visible hull faces — please flag any staining or knots in the billet. |
| Walnut, FAS, 12/4 | Kiln-dried, ~300 × 150 × 80 mm | 1 | Stand base. |
| Western red cedar, AAA quartersawn, 3 mm | Soundboard quality, 200 × 700 mm, edge-glued or single panel | 2 (one 3.0 mm, one 2.5 mm) | Soundboard. Order both thicknesses for Wolfram sweep validation. |
| Sapele, FAS quartersawn, 8/4 | Rip-friendly to 12 mm laminate strips, ~800 mm long, ~50 mm wide | 1 set sufficient for three 12 mm laminates | Neck cantilever (laminated bend). |
| Cherry, air-dried, 6 mm sticks | Brace stock, ~200 mm long, ~12 × 12 mm | 4 | Internal hull braces fore and aft of keel port. |
| Holly or maple veneer, 0.8 mm | Inlay spacer | Sufficient for ~3 m of band perimeter (4 spacer rows) | Lapis-band parallel spacers. |

Please send: (a) current per-piece pricing or per-board-foot pricing, (b) lead time, (c) any photos of grain on the walnut billet, (d) shipping estimate to [Tony's address].

---

## RFQ-2 — Brass and stainless hardware

**To:** [McMaster-Carr or Online Metals]
**Subject:** Quote request — small custom brass collar + stainless dowels

| Item | Spec | Qty |
|---|---|---|
| Brass tube, 60 mm tall, ~50–60 mm OD, ~1 mm wall | C36000 or C26000, suitable for chemical patination | 2 (1 for SAM-13-ROOT, 1 for MULE / sample) |
| Stainless 304 dowel pin, 6 mm × 80 mm | For hidden scarf-joint pin | 5 (spares) |
| Stainless 304 forged eyebolt, M6 × 40 mm | For SAM-19 / 25 / AE harness mount | 3 |
| Brass rod, ~20 mm diameter, ~200 mm long | Custom-machined bulb caps (or buy pre-made — see RFQ-4) | 1 |

---

## RFQ-3 — String sets (G-major build + A-major retune)

**To:** [LMI Music or Strings Etc. or Lo-tech harp NZ]
**Subject:** Quote request — custom calibrated string set, 13-string boat-harp

I'm building a 13-string arched harp with the following parameters:

- Speaking length range: ~580 mm (bass) → ~200 mm (treble), curve exponent k=0.85.
- Target total tension: 65–80 kgf across all 13 strings.
- Soundboard: 3 mm Western red cedar with light fan bracing.
- String spacing on the holder strip: ~6 mm.

I need two string sets:

### Set A — G-major build target (G3 → E5)

| String # | Pitch | Speaking length | Type |
|---|---|---|---|
| 1 | G3 (196.0 Hz) | ~580 mm | Wound nylon (low-tension bass) |
| 2 | A3 (220.0 Hz) | ~530 mm | Wound nylon |
| 3 | B3 (246.9 Hz) | ~485 mm | Wound nylon |
| 4 | C4 (261.6 Hz) | ~462 mm | Wound nylon |
| 5 | D4 (293.7 Hz) | ~420 mm | Fluorocarbon |
| 6 | E4 (329.6 Hz) | ~378 mm | Fluorocarbon |
| 7 | F#4 (370.0 Hz) | ~340 mm | Fluorocarbon |
| 8 | G4 (392.0 Hz) | ~322 mm | Fluorocarbon |
| 9 | A4 (440.0 Hz) | ~290 mm | Fluorocarbon |
| 10 | B4 (493.9 Hz) | ~262 mm | Fluorocarbon |
| 11 | C5 (523.3 Hz) | ~248 mm | Fluorocarbon |
| 12 | D5 (587.3 Hz) | ~222 mm | Fluorocarbon |
| 13 | E5 (659.3 Hz) | ~200 mm | Fluorocarbon |

Please propose specific gauges. Targeting 5–7 kgf per string for the calibrated total.

### Set B — A-major drop-in retune (A3 → F#5)

Same instrument, retuned a whole step up. Same speaking lengths. Targeting 5.5–7.5 kgf per string. Both wound nylon basses and fluorocarbon trebles, gauges adjusted upward to compensate for the higher pitches at unchanged length.

| String # | Pitch | Type |
|---|---|---|
| 1 | A3 (220.0 Hz) | Wound nylon |
| 2 | B3 (246.9 Hz) | Wound nylon |
| 3 | C#4 (277.2 Hz) | Wound nylon |
| 4 | D4 (293.7 Hz) | Wound nylon |
| 5 | E4 (329.6 Hz) | Fluorocarbon |
| 6 | F#4 (370.0 Hz) | Fluorocarbon |
| 7 | G#4 (415.3 Hz) | Fluorocarbon |
| 8 | A4 (440.0 Hz) | Fluorocarbon |
| 9 | B4 (493.9 Hz) | Fluorocarbon |
| 10 | C#5 (554.4 Hz) | Fluorocarbon |
| 11 | D5 (587.3 Hz) | Fluorocarbon |
| 12 | E5 (659.3 Hz) | Fluorocarbon |
| 13 | F#5 (740.0 Hz) | Fluorocarbon |

### Set C — SAM-13-MULE reduced-tension test set

Same instrument, full G-major tuning, but at half-tension. Targeting 3.0–4.5 kgf per string. Same speaking lengths. Lighter gauges across the board. Used for the 30-day joint-validation hold per `validation.csv` V-S-01. Disposable.

---

## RFQ-4 — Geared guitar tuners + PVD-gold-tone bulb caps

**To:** [Stewart-MacDonald / Allied Lutherie / local CNC shop + PVD finisher]
**Subject:** Quote request — small-format geared tuners with custom decorative caps

### Tuners

I need 13 compact-housing geared tuners (small-format classical guitar or harp style). Critical dimensions:

- Maximum housing depth behind the post: 50 mm
- Output shaft diameter: 6–8 mm
- Mounting: through-hole into wood, locked from the back by a flange or screw

If you have a model that fits inside a 50 mm-deep neck cross-section, please confirm with a CAD drawing or photo.

### PVD-gold-tone bulb caps

I need 13 custom caps that slip over the tuner output shaft and present as decorative gold bulbs. Spec:

- Outer profile: roughly spherical or oblate-spheroid, ~16–18 mm diameter, ~12–14 mm tall
- Bore: clearance-fit over the geared-tuner output shaft (6–8 mm depending on tuner choice)
- Material: brass C36000 or C26000, machined or 3D-printed (cast or sintered acceptable)
- Finish: PVD gold-tone (titanium nitride OR zirconium nitride OR true gold-color PVD)

Please quote either:

1. **Custom-machined + PVD path** — turn 13 caps from brass rod, send to PVD finisher. Quote both stages.
2. **Stock part adapt** — propose a jewelry/clock-parts catalog item that meets the spec at lower cost.

The caps are the most visible decorative element on the instrument. Color match across 13 caps is critical.

---

## RFQ-5 — Inlay materials (multi-strip lapis band + bow-end panel)

**To:** [Certainly Wood / Stewart-MacDonald / Maples Inlays]
**Subject:** Quote request — luthier inlay stock for a boat-harp build

### Multi-strip lapis band

5 parallel strips per band, ~3 m total band perimeter.

| Item | Spec | Qty |
|---|---|---|
| Dyed-blue veneer | "Lapis-blue" or "deep blue" dye, 1.5 mm thick, 15+ mm wide | Sufficient for 5 strips × 3 m = 15 linear meters |
| Holly or maple spacer veneer | Natural light color, 0.8 mm thick | 4 strips × 3 m = 12 linear meters |

Color match across the 5 strips is critical; please confirm dye lot is single batch.

### Bow-end soundboard inlay panel

| Item | Spec | Qty |
|---|---|---|
| Mother-of-pearl OR shell composite OR pale-stone composite | 100 × 60 × 1.5 mm tile, pale color | 1 (sample set of 3 candidates preferred — see notes) |

For the panel, I would prefer to receive **one sample of each of three candidate materials** (true MOP, abalone-look composite, pale-stone-look composite) so I can finish-test on a scrap soundboard before committing to the final material. Quote the sample set separately from the production tile.

### Heifer Zephyr brand inlay stock (TBD per brand-integration gate)

Either:

- **Option A (soundboard):** brass-leaf veneer for italic-serif wordmark, ~80 × 14 × 0.3 mm.
- **Option B (stand):** matching lapis-blue dyed veneer (~120 × 18 × 1.5 mm).

Quote both; we'll pick after the brand-integration review closes.

---

## RFQ-6 — Harness hardware (SAM-19 / SAM-25)

**To:** [REI / Petzl / BG Music / Sweetwater / marine chandlery]
**Subject:** Quote request — sax-style + work-positioning harnesses for harp builds

### For SAM-19-MID

| Item | Spec | Qty |
|---|---|---|
| Padded work-positioning belt, 50–75 mm wide, with side D-rings | Climbing / arborist style, hook-and-loop + steel buckle closure | 1 |
| Adjustable nylon tether strap, ~600 mm, with cam buckle | 1 in nylon webbing | 1 |
| Locking carabiner / locking snap hook | 40 kN rated; locking, not snap-only | 1 |

### For SAM-25-CONCERT

| Item | Spec | Qty |
|---|---|---|
| Saxophone-style shoulder harness, padded yoke + sternum strap, hook | BG S40SH, Neotech Soft Sax, or Cebulla — please quote your closest equivalent | 1 |
| Locking carabiner / locking snap hook | 40 kN rated; locking | 1 |

The locking-hook requirement is non-negotiable per safety risk R-Z-02. Please confirm the hook is *locking*, not just *snap-only*.

---

## RFQ-7 — Acoustic-electric components (SAM-13-AE only)

**To:** [K&K Sound / Stewart-MacDonald / Sweetwater]
**Subject:** Quote request — under-strip piezo for boat-harp

| Item | Spec | Qty |
|---|---|---|
| Under-saddle / under-strip piezo transducer, K&K Pure Mini or equivalent | Suitable for ~120 mm long string-holder strip | 1 |
| 1/4 in barrel jack, panel-mount, gold or chrome | Hidden in stern stub, accessible from outside | 1 |
| Internal wiring kit, 22 AWG stranded, ~1 m + heatshrink | Includes solder and basic shielding | 1 |

Please confirm the piezo transducer can be glued in-line under a glued-on hardwood string-holder strip (not a slotted bridge).

---

## Common notes for all RFQs

- Pricing is requested as a **planning estimate** only. We will issue purchase orders separately after the cultural-review and validation gates clear.
- Lead times in `sourcing.csv` are typical-industry estimates, not committed. Please respond with your actual lead time so the build schedule can adjust.
- All deliveries to: **[Tony's address]**.
- Contact: Tony Koop — [tonykoop@gmail.com] or via the Heifer Zephyr workshop.

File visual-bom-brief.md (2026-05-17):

# Sambuca — Visual BOM Brief

Layout spec for the visual bill-of-materials plate. Pairs with `bom.csv` data; the visual BOM is the human-facing one-pager that goes into the capstone deck (one slide) and the print packet (one page).

## Document conventions

- **Format:** single-page printable. Default page size: letter or A4, landscape.
- **Headline:** "Sambuca — SAM-13-ROOT — Visual Bill of Materials"
- **Quote date:** ISO date at the top right.
- **Assembly hero image:** the full-instrument render at the top, occupying ~1/3 of the page.
- **Layout below:** grid of part rows, ~6 per page-column, two columns.
- **Cost flag:** "Planning estimates. Actual prices verified at purchase time." in 8 pt font at the bottom.

## Hero image spec

- **Subject:** SAM-13-ROOT, full instrument, three-quarter view from front-right.
- **Pose:** displayed on its CNC-curve-profiled walnut cradle stand.
- **Lighting:** soft directional light from upper-left.
- **Background:** neutral mid-gray, no distracting elements.
- **Resolution:** 2400 × 1600 px minimum, exportable to PDF at 300 dpi.
- **Source:** SolidWorks rendering OR finished-prototype photo (per `photo-shotlist.md`). Photo preferred for the final capstone deck.

## Part-row layout

Each row carries:

| Field | Notes |
|---|---|
| Thumbnail | ~80 × 80 px square, clean cutout against neutral background |
| Part name | e.g. "Hull — walnut, CNC-from-block" |
| Material spec | abbreviated, e.g. "Walnut FAS 8/4 quartersawn" |
| Quantity | per SAM-13-ROOT |
| Cost estimate | range, e.g. "$80–180" |
| Sourcing note | one-line, e.g. "Bell Forest Products / Owl Hardwood" |

## Visual BOM part list (SAM-13-ROOT)

Ordered by visual prominence:

1. **Hull** (walnut) — the boat body itself.
2. **Soundboard** (Western red cedar with multi-strip lapis band + bow inlay panel) — the top face the player faces.
3. **Neck** (sapele, laminated curve) — the cantilever rising forward.
4. **Brass neck-body collar** — the bright fingerprint element.
5. **13 tuners with gold-tone bulb caps and decorative wraps** — the row of pegs along the neck.
6. **Multi-strip lapis inlay band** — 5 parallel strips along the soundboard-hull seam.
7. **Bow-end inlay panel** — pale rectangular panel (mother-of-pearl or composite) at the bow.
8. **String-holder strip** — small walnut or maple strip on the soundboard near the bow.
9. **String set** (13 strings — 4 wound nylon basses + 9 fluorocarbon trebles).
10. **Stern stub feet** — two carved walnut blocks integral with the keel.
11. **Keel-port surround** (optional walnut binding around the oval port).
12. **Stand** (CNC-curve-profiled walnut cradle with kanawa-tsugi joinery).
13. **Heifer Zephyr brand inlay** (Option A soundboard or Option B stand — TBD per gate).

## Variant strip

Below the part list, a horizontal strip showing the five family variants side-by-side at consistent scale (1:5 or similar):

| Variant | Body length | Strings | Tuning | Harness |
|---|---|---|---|---|
| SAM-13-ROOT | 650 mm | 13 | G3 → E5 | none |
| SAM-19-MID | 850 mm | 19 | D3 → G5 | positioning belt |
| SAM-25-CONCERT | 1050 mm | 25 | A2 → A5 | sax harness |
| SAM-13-AE | 650 mm | 13 | G3 → E5 | none (+ piezo) |
| SAM-13-MULE | 650 mm | 13 | G3 → E5 (reduced T) | none |

## Cost summary line

Bottom of the page, single line:

> SAM-13-ROOT total planning estimate: $530–1300 USD. Major cost drivers: PVD-gold-tone bulb caps (~$60–260), geared tuners (~$40–180), walnut hull stock (~$80–180), bow-end inlay panel (~$15–60). See `bom.csv` for the line items.

## Color and typography

- **Brand-neutral while in private review** — no Heifer Zephyr wordmark on this page until the brand-integration gate closes.
- **Typography:** simple serif (e.g. Source Serif or Charter) for body, simple sans-serif (e.g. Inter or Source Sans) for callouts.
- **Color palette:** walnut brown, cedar honey, brass gold, lapis blue — pulled from the actual material colors. No saturated primaries.

## Production

When the SAM-13-ROOT is photographed for the final deck, run the visual BOM as:

1. Capture the hero image per `photo-shotlist.md` shot HERO-01.
2. Capture each visible part as a thumbnail (per `photo-shotlist.md` shots DETAIL-01 through DETAIL-13).
3. Composite in any vector tool (Affinity Designer, Adobe Illustrator, or Figma). Source files in `images/`; final PDF in `print-packet.pdf`.

## Variant visual BOMs

The SAM-19-MID, SAM-25-CONCERT, SAM-13-AE, and SAM-13-MULE share most of the SAM-13-ROOT BOM. Don't produce four separate visual BOMs — produce a single SAM-13-ROOT visual BOM and a one-page delta table for the other four variants.

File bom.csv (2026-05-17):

part_id | category | part_name | material_spec | qty_per_unit | unit | SAM-13-ROOT | SAM-19-MID | SAM-25-CONCERT | SAM-13-AE | SAM-13-MULE | make_buy | planning_cost_usd | notes
BOM-001 | hull | Hull billet or stave stock | Walnut FAS or QSWO equivalent kiln-dried 8/4 | 1 | ea | 1 | 1 | 1 | 1 | 1 | buy | 80-180 | Single billet for CNC-from-block OR ~10 staves for stave-laminated. Cost flag: planning-estimate.
BOM-002 | hull | Internal hull braces | Cherry 6mm sticks | 2 | ea | 2 | 3 | 4 | 2 | 2 | make | 5-12 | Fore and aft of keel port. Cost flag: planning-estimate.
BOM-003 | hull | Stern stub feet | Walnut block 30 x 25 x 15 mm | 2 | ea | 2 | 2 | 2 | 2 | 2 | make | negligible | Cut from hull offcuts. Two integral feet at stern keel.
BOM-004 | soundboard | Soundboard panel | Western red cedar quartersawn 3 mm | 1 | ea | 1 | 1 | 1 | 1 | 1 | buy | 30-60 | 2.5-4.0 mm sweep in Wolfram before locking. Cost flag: planning-estimate.
BOM-005 | soundboard | Soundboard braces | Cedar fan-brace stock 3 x 8 mm | 4 | ea | 4 | 5 | 6 | 4 | 4 | make | negligible | Light fan pattern under string-holder strip. Cut from soundboard offcuts.
BOM-006 | soundboard | String-holder strip | Walnut or hard maple 10 x 4 mm | 1 | ea | 1 | 1 | 1 | 1 | 1 | make | 5-10 | Glued to soundboard with hide glue. Reversible position during voicing on MULE.
BOM-007 | soundboard | Bow-end inlay panel | Mother-of-pearl OR shell composite tile | 1 | ea | 1 | 1 | 1 | 1 | 1 | buy | 15-60 | 100 x 60 mm pale rectangular inlay at the bow. Material per finish-test pick.
BOM-008 | neck | Neck laminate stock | Sapele quartersawn 8/4 or three 12mm laminates | 1 | ea | 1 | 1 | 1 | 1 | 1 | buy | 40-90 | Laminate-and-bend then CNC. Three 12 mm laminates preferred for curve.
BOM-009 | neck | Neck-body brass collar | Brass tube or sheet | 60 mm tall x 0.8-1.2 mm wall | 1 | ea | 1 | 1 | 1 | 1 | 1 | buy | 15-40 | Aged/patinated finish per R-F-02. Source: McMaster brass tube or Online Metals brass sheet.
BOM-010 | neck | Neck-body scarf joint pin | Stainless 6 mm dowel | 1 | ea | 1 | 1 | 1 | 1 | 1 | buy | 2 | Hidden through both members.
BOM-011 | inlay | Lapis-look multi-strip veneer set | Lapis-blue dyed veneer + holly/maple spacer | 1 | set | 1 | 1 | 1 | 1 | 1 | buy | 25-50 | 5 strips x 1.5 mm wide + 0.8 mm spacers. Single-pass CNC routed pocket.
BOM-012 | inlay | Epoxy filler for inlay | West System or System Three slow-cure epoxy | 1 | kit | 1 | 1 | 1 | 1 | 1 | buy | 15-30 | Tints with dye to match strip color where needed.
BOM-013 | inlay | Heifer Zephyr brand inlay stock | Brass-leaf veneer + dark-walnut spacer (Opt A) OR matching lapis (Opt B) | 1 | set | 1 | 1 | 1 | 1 | 1 | buy | 10-25 | Placement TBD per brand integration gate.
BOM-014 | strings | Fluorocarbon string set | SAM-13-ROOT calibrated set (treble strings 5-13) | 1 | set | 1 | 1 | 1 | 1 | 1 | buy | 30-50 | Fluorocarbon trebles. G-major build target. A-major retune set documented separately.
BOM-015 | strings | Wound nylon string set | SAM-13-ROOT calibrated bass set (strings 1-4) | 1 | set | 1 | 1 | 1 | 1 | 1 | buy | 25-45 | Wound nylon basses bring total tension into 65-80 kgf target band.
BOM-016 | strings | A-major retune string set (optional) | Drop-in fluorocarbon + wound nylon set | 1 | set | 1 | 1 | 1 | 1 | 1 | buy | 55-95 | Documented in supplier-rfq.md. Optional sibling SKU.
BOM-017 | tuners | Geared guitar tuners | Compact-housing harp/classical-guitar tuner with hidden gear | 13 | ea | 13 | 19 | 25 | 13 | 13 | buy | 40-180 | Per family-spec string_count. Compact-housing variant per R-X-04 mock-fit.
BOM-018 | tuners | PVD-gold-tone brass bulb caps | Custom-machined brass cap + PVD finish | 13 | ea | 13 | 19 | 25 | 13 | 13 | buy | 60-260 | ~$5-10 ea custom-machined. Source decision per R-X-03.
BOM-019 | tuners | Decorative tuner cord wrap | Aged-look waxed silk or sinew-look cord 1 mm | 1 | spool | 1 | 1 | 1 | 1 | 1 | buy | 8-15 | ~8 turns per peg. Visual fingerprint element per second-photo-set observation.
BOM-020 | keelport | Keel-port surround (optional binding) | Walnut binding strip 3 x 6 mm | 1 | ea | 1 | 1 | 1 | 0 | 1 | make | 3-6 | Optional decorative binding around the oval keel-port edge. SAM-13-AE skips if pickup jack uses the port area.
BOM-021 | stern_hw | Stern eyebolt | M6 x 40 mm stainless forged eyebolt | 1 | ea | 0 | 1 | 1 | 1 | 0 | buy | 4-8 | SAM-13-ROOT and SAM-13-MULE skip. SAM-19/25/AE include for harness or strap-mount.
BOM-022 | stern_hw | Stern eyebolt backing plate | Hardwood 10 x 25 x 40 mm walnut | 1 | ea | 0 | 1 | 1 | 1 | 0 | make | negligible | Cut from hull offcuts. Glued to inside of hull.
BOM-023 | electronics | Under-strip piezo transducer | K&K Pure Mini or equivalent | 1 | ea | 0 | 0 | 0 | 1 | 0 | buy | 75-110 | SAM-13-AE only.
BOM-024 | electronics | Output jack | 1/4 inch barrel jack panel-mount | 1 | ea | 0 | 0 | 0 | 1 | 0 | buy | 8-15 | Hidden in stern stub on SAM-13-AE.
BOM-025 | electronics | Internal wiring + shrinkwrap | Stranded 22 AWG + heatshrink | 1 | kit | 0 | 0 | 0 | 1 | 0 | buy | 5-10 | SAM-13-AE only.
BOM-026 | harness | Low-back positioning belt | 50-75 mm padded waist belt with side D-rings | 1 | ea | 0 | 1 | 0 | 0 | 0 | buy | 35-65 | SAM-19-MID only. Climbing/work positioning belt repurposed.
BOM-027 | harness | Saxophone-style harness | Padded shoulder yoke with sternum strap | 1 | ea | 0 | 0 | 1 | 0 | 0 | buy | 45-95 | SAM-25-CONCERT only. BG S40SH or equivalent.
BOM-028 | harness | Locking hook for harness | Locking carabiner-class snap hook | 1 | ea | 0 | 1 | 1 | 0 | 0 | buy | 10-20 | Per R-Z-02 specifies locking not snap-only.
BOM-029 | harness | Adjustable tether strap (SAM-19) | 1 in nylon webbing with cam buckle 600 mm | 1 | ea | 0 | 1 | 0 | 0 | 0 | buy | 8-15 | Belt-to-stern tether on SAM-19-MID.
BOM-030 | stand | Stand uprights | Walnut quartersawn 8/4 CNC-curve-profiled | 2 | ea | 2 | 2 | 2 | 2 | 2 | make | 30-60 | CNC curve-profiled cradle uprights matching keel curvature.
BOM-031 | stand | Stand base | Walnut 12/4 with kanawa-tsugi or mitsuke-aritsugi joinery | 1 | ea | 1 | 1 | 1 | 1 | 1 | make | 25-50 | Japanese joinery at straight intersections.
BOM-032 | stand | Stand felt pads | Adhesive-back industrial felt 3 mm | 1 | kit | 1 | 1 | 1 | 1 | 1 | buy | 3-5 | Between uprights and keel.
BOM-033 | fasteners | Hide glue (hot or fish) | Liquid hide glue or hot hide pellets 250 g | 1 | kit | 1 | 1 | 1 | 1 | 1 | buy | 12-25 | For string-holder strip and reversible joints.
BOM-034 | fasteners | Wood glue (Titebond III or equivalent) | Yellow PVA glue 8 oz | 1 | kit | 1 | 1 | 1 | 1 | 1 | buy | 8-12 | For non-reversible joints.
BOM-035 | fasteners | Two-part epoxy | 30-min cure 8 oz | 1 | kit | 1 | 1 | 1 | 1 | 1 | buy | 10-18 | For brass-to-wood and high-stress glue lines.
BOM-036 | finish | Oil + wax finish | Tried-and-true Original or Osmo Polyx-Oil 0.5 L | 1 | kit | 1 | 1 | 1 | 1 | 1 | buy | 15-30 | Hull + neck finish.
BOM-037 | finish | Soundboard finish (separate) | Hard shellac (1 lb cut) or thin oil 250 ml | 1 | kit | 1 | 1 | 1 | 1 | 1 | buy | 10-20 | Soundboard wants a thin finish that doesn't damp.
BOM-038 | finish | Brass polish + PVD-friendly cleaner | Cape Cod cloth + IPA wipe-down | 1 | kit | 1 | 1 | 1 | 1 | 1 | buy | 8-15 | Pre-PVD prep for caps.
BOM-039 | tooling | CNC inlay end mill 0.8-1.0 mm | Solid carbide 2-flute | 2 | ea | 2 | 2 | 2 | 2 | 2 | buy | 12-30 | Spare in case of breakage on multi-strip band.
BOM-040 | tooling | CNC profile bits (hull profile) | 1/4 in 2-flute upcut + 1/8 in detail bit | 1 | kit | 1 | 1 | 1 | 1 | 1 | buy | 40-80 | Already in Maker Nexus shop inventory.
BOM-041 | tooling | Hide glue brush + heating cup | Natural-bristle brush + small glue pot | 1 | kit | 1 | 1 | 1 | 1 | 1 | buy | 15-30 | For hot-hide glue option.
BOM-042 | jigs | Soundboard pull-test fixture | Plywood + 5 kgf gauge | 1 | ea | 1 | 1 | 1 | 1 | 1 | make | 15-30 | Validates R-S-04 string-holder-strip glue strength on scrap.
BOM-043 | jigs | Neck-deflection measurement jig | Dial indicator + magnetic base | 1 | ea | 1 | 1 | 1 | 1 | 1 | buy | 40-80 | For SAM-13-MULE 30-day hold (R-S-01).
BOM-044 | jigs | String-holder strip positioning fixture | Cedar scrap + slotted aluminum bar | 1 | ea | 1 | 1 | 1 | 1 | 1 | make | negligible | Holds the strip at adjustable positions during prototype voicing.
# Cost flag for the whole BOM: planning-estimate. Live supplier prices not verified.
# Total per-variant planning estimate range:
# SAM-13-ROOT: ~530-1300 USD
# SAM-19-MID: ~620-1500 USD (adds belt + 6 extra tuners + 6 extra caps)
# SAM-25-CONCERT: ~750-1850 USD (adds sax harness + 12 extra tuners + 12 extra caps)
# SAM-13-AE: ~620-1450 USD (adds piezo + jack + wiring)
# SAM-13-MULE: ~470-1150 USD (test mule; no harness hardware | reduced string set OK)

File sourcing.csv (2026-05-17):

part_id | part_name | spec_summary | candidate_supplier_1 | candidate_supplier_2 | candidate_supplier_3 | lead_time_estimate | price_assumption_flag | notes
BOM-001 | Walnut hull stock | FAS 8/4 quartersawn 200x650 mm or equivalent | Bell Forest Products | Owl Hardwood (Chicago) | local mill | 2-4 weeks | planning-estimate; prices NOT verified live | Stave option needs 10 staves 60x20x650; CNC-from-block option needs single 200x650 billet.
BOM-002 | Cherry brace stock | Air-dried 6mm strips | Owl Hardwood | Bell Forest | Rockler retail | 1-2 weeks | planning-estimate | Cut from existing stock if available.
BOM-004 | Western red cedar soundboard | Quartersawn AAA 3 mm 200x650 | LMI (Luthiers Mercantile) | Stewart-MacDonald | Hibdon Hardwood (Nashville) | 1-3 weeks | planning-estimate | Order both 2.5 and 3.0 mm for Wolfram sweep validation.
BOM-006 | String-holder strip stock | Walnut OR hard maple 10x4x150 mm | scrap from BOM-001 | LMI offcuts | Stewart-MacDonald | immediate | planning-estimate | Make from BOM-001 offcuts when possible.
BOM-007 | Bow-end inlay panel | Mother-of-pearl OR shell composite 100x60 mm | Stewart-MacDonald (MOP tiles) | LMI Music (shell composite) | Maples Inlays (pale stone composite) | 1-3 weeks | planning-estimate | Three-candidate sample test per R-X-02 before committing.
BOM-008 | Sapele neck stock | Quartersawn 8/4 or three 12mm laminates | Bell Forest Products | Owl Hardwood | LMI | 2-4 weeks | planning-estimate | Three-laminate option preferred for the curve.
BOM-009 | Brass neck-body collar stock | Brass tube 60mm tall 0.8-1.2mm wall OR sheet | McMaster-Carr | Online Metals | Speedy Metals | 1 week | planning-estimate | Tube is easier if diameter matches; sheet if custom-bent.
BOM-011 | Lapis-look multi-strip veneer | Dyed-blue veneer 1.5mm + holly/maple spacer | Certainly Wood (dyed veneer) | Veneer Supplies | LMI Music | 2-4 weeks | planning-estimate | Two-supplier sample compare per R-X-01.
BOM-012 | Inlay epoxy | West System 105/207 OR System Three slow-cure | West Marine | Jamestown Distributors | System Three Direct | 1 week | planning-estimate | Tinted as needed for color match.
BOM-013 | Heifer Zephyr brand inlay stock | Brass-leaf veneer OR matching lapis | Certainly Wood | Stewart-MacDonald | Maples Inlays | 2-3 weeks | planning-estimate | Order after brand-integration gate closes.
BOM-014 | Fluorocarbon string set (build) | SAM-13-ROOT calibrated set strings 5-13 | LMI Music | Strings Etc. | Lo-tech harp (NZ) | 1-2 weeks | planning-estimate | Order calibrated set after Wolfram tension sweep finalizes diameters.
BOM-015 | Wound nylon bass set | SAM-13-ROOT calibrated bass set strings 1-4 | LMI Music | Strings Etc. | custom-wound from gauge supplier | 2-3 weeks | planning-estimate | Wound nylon brings total tension into 65-80 kgf target.
BOM-016 | A-major retune string set | Drop-in fluorocarbon + wound nylon | LMI Music | Strings Etc. | Lo-tech harp | 1-2 weeks | planning-estimate | Optional sibling SKU. Slightly higher gauge across the board.
BOM-017 | Geared guitar tuners | Compact-housing harp/classical-guitar tuner | Stewart-MacDonald (classical) | Allied Lutherie (small-format harp tuners) | Pacific Coast Strings | 2-3 weeks | planning-estimate | Mock-fit one tuner before bulk order per R-X-04.
BOM-018 | PVD-gold-tone brass bulb caps | Custom-machined brass cap + PVD coating | Maker Nexus shop (CNC turn) + local PVD finisher | Pulse Plating (PVD) | Jewelry supply (small-batch) | 3-5 weeks (custom run) | planning-estimate; CUSTOM PART | Parallel paths per R-X-03. Highest-risk supply item.
BOM-019 | Decorative tuner cord wrap | Aged-look waxed silk 1mm | Stewart-MacDonald (silk wrap) | Maine Thread (waxed cord) | Hancock Hardware (sinew lacing) | 1-2 weeks | planning-estimate | Spool covers all variants.
BOM-021 | Stern eyebolt | M6 x 40 mm 304 stainless forged | McMaster-Carr | Grainger | marine chandlery | 3-5 days | planning-estimate | Forged not bent. Working load rating ~40 kgf.
BOM-023 | Under-strip piezo transducer | K&K Pure Mini or equivalent | K&K Sound direct | Stewart-MacDonald | Sweetwater | 1-2 weeks | planning-estimate | SAM-13-AE only.
BOM-024 | Output jack | 1/4 inch barrel panel-mount | Sweetwater | Mouser | Allparts | 3-5 days | planning-estimate | SAM-13-AE only.
BOM-026 | Low-back positioning belt | 50-75 mm padded waist belt with D-rings | REI (climbing positioning belt) | Petzl (Sequoia or Falcon) | Treestand Buddy | 1 week | planning-estimate | SAM-19-MID only.
BOM-027 | Saxophone-style harness | Padded shoulder yoke + sternum strap | Sweetwater (BG S40SH) | Cebulla harness | Neotech Soft Sax Harness | 1-2 weeks | planning-estimate | SAM-25-CONCERT only.
BOM-028 | Locking harness hook | Locking carabiner-class snap hook 40 kN | REI | Petzl | marine chandlery | 1 week | planning-estimate | Per R-Z-02. Locking required not snap-only.
BOM-030 | Stand upright stock | Walnut quartersawn 8/4 | Bell Forest Products | Owl Hardwood | scrap from BOM-001 | 2-4 weeks | planning-estimate | Match hull walnut visually.
BOM-031 | Stand base stock | Walnut 12/4 | Bell Forest Products | Owl Hardwood | specialty mill | 3-5 weeks | planning-estimate | Heavier stock for stability.
BOM-033 | Hide glue | Liquid hide glue OR hot hide pellets 250g | Lee Valley (liquid) | Tools for Working Wood (hot pellets) | Stewart-MacDonald | 1 week | planning-estimate | Hot hide preferred for reversibility on string-holder strip.
BOM-034 | Wood glue PVA | Titebond III 8 oz | Home Depot | Lee Valley | Rockler | immediate | planning-estimate | Standard PVA for non-reversible joints.
BOM-035 | Two-part epoxy | 30-min cure 8 oz | Home Depot (System Three or West) | Jamestown Distributors | Lee Valley | immediate | planning-estimate | For brass-to-wood and high-stress glue lines.
BOM-036 | Oil + wax finish | Tried-and-True OR Osmo Polyx-Oil 0.5L | Lee Valley | Woodcraft | Highland Woodworking | 1 week | planning-estimate | Hull and neck.
BOM-037 | Soundboard finish | Hard shellac (1lb cut) OR thin oil 250ml | Lee Valley | Tools for Working Wood | Woodcraft | 1 week | planning-estimate | Thin finish to avoid damping.
BOM-039 | CNC inlay end mill 0.8-1.0mm | Solid carbide 2-flute | Onsrud | Amana Tool | Drillman1 (eBay) | 1 week | planning-estimate | Spare per R-F-01.
# Sourcing-doc assumption flag: this is a SPEC-FIRST table.
# No live prices were verified. All "candidate_supplier_*" entries are reasonable industry-standard sources
# not vetted vendor relationships. Lead-time estimates are typical | not committed.
# Verify availability | pricing | and shipping before placing any order.
#
# Highest-risk supply items (re-check before commit):
# BOM-018 PVD-gold-tone bulb caps - custom part | longest lead | two-supplier parallel search recommended
# BOM-017 Geared tuners - mock-fit before bulk order
# BOM-007 Bow-end inlay panel - three-candidate sample compare before commit
# BOM-001 Walnut hull stock - need clean grain for CNC; visual match between hull | stand | stub feet

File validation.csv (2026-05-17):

check_id | category | check_name | target | method | instrument | acceptance | owner | gate_block | linked_risk | notes
V-D-01 | dimensional | Body length SAM-13-ROOT | 650 mm | measure with steel rule from bow to stern at soundboard centerline | steel rule 0.5 mm resolution | 650 +/- 2 mm | builder | no | n/a | Per BM 121198 anchor.
V-D-02 | dimensional | Body width SAM-13-ROOT | 150 mm | measure beam at midship soundboard | calipers | 150 +/- 2 mm | builder | no | n/a | Per BM anchor.
V-D-03 | dimensional | Body depth SAM-13-ROOT | 150 mm | measure profile depth at midship | calipers | 140-170 mm | builder | no | n/a | Allowance for 20 mm uncertainty from photo evidence.
V-D-04 | dimensional | Instrument height SAM-13-ROOT | 810 mm | measure from gold cap top to keel bottom | steel rule | 810 +/- 5 mm | builder | no | n/a | Per BM anchor.
V-D-05 | dimensional | String_holder_strip position from stern | ~520 mm (~80% of body length) | measure after voicing | steel rule | locked after voicing on MULE | builder | yes | n/a | Voicing decision; locked on MULE then committed to ROOT.
V-D-06 | dimensional | Keel port long axis | 80 mm | measure oval long axis | calipers | 80 +/- 1 mm | builder | no | n/a | Per master-equations.
V-D-07 | dimensional | Keel port short axis | 50 mm | measure oval short axis | calipers | 50 +/- 1 mm | builder | no | n/a | Per master-equations.
V-D-08 | dimensional | Keel port forward tilt | 15 deg | measure chamfer angle | protractor | 12-18 deg | builder | no | n/a | Per master-equations.
V-D-09 | dimensional | Neck arc length | ~710 mm | measure along neck centerline from joint reference to cap | flex tape | 710 +/- 5 mm | builder | no | n/a | Per master-equations neck_arc_length_mm.
V-D-10 | dimensional | Brass collar height | 60 mm | measure collar along neck axis | calipers | 60 +/- 1 mm | builder | no | n/a | Per master-equations.
V-D-11 | dimensional | String-holder strip dimensions | 120 mm long x 10 mm wide x 4 mm tall | measure strip | calipers | 120 +/- 1 / 10 +/- 0.5 / 4 +/- 0.3 | builder | no | n/a | Final strip per master-equations.
V-D-12 | dimensional | Tie-through hole pattern | 13 holes at string_spacing_mm | measure hole centers | calipers | centers +/- 0.3 mm | builder | no | n/a | Driven by master-equations linear pattern.
V-D-13 | dimensional | Bow-end inlay panel | 100 x 60 mm pocket depth 1.5 | measure pocket and panel fit | calipers + feeler gauges | panel sits flush +/- 0.1 mm | builder | no | n/a | Per master-equations bow_panel.
V-D-14 | dimensional | Multi-strip lapis band width | ~12 mm total composed of 5x1.5 + 4x0.8 | measure across band at three locations | calipers | total 11-13 mm strips within 0.2 mm | builder | no | R-F-01 | Per master-equations inlay_strip.
V-T-01 | tension | SAM-13-MULE reduced-tension load | 40-50 kgf total | tune to spec then sum measured per-string tensions | calibrated strain gauge on test stand | total within 40-50 kgf | structural-test | yes | R-S-01 | Validation pre-step for SAM-13-ROOT.
V-T-02 | tension | SAM-13-ROOT calibrated-tension load | 65-80 kgf total | tune to G-major spec; sum measured per-string | strain gauge or calibrated tuner + math | total within 65-80 kgf | structural-test | yes | R-S-01 | Build target tension calibration. Triggers Wolfram sweep adjustment if outside band.
V-T-03 | tension | SAM-13-ROOT post-30-day tension drift | < 10% drop | re-measure tension after 30 days | strain gauge | < 10% drop on any string | structural-test | no | R-A-02 | Tunes stability check.
V-T-04 | tension | SAM-25-CONCERT total tension | 90-110 kgf estimated | tune to spec; sum | strain gauge | band locked after Wolfram sweep | structural-test | no | R-S-01 | Scaled-up family member.
V-S-01 | structural | Neck-deflection at SAM-13-MULE 30-day hold | < 2 mm at gold cap relative to body | dial indicator + magnetic base reference | direct measurement | < 2 mm | structural-test | yes | R-S-01 | The single most critical structural validation.
V-S-02 | structural | Brass collar seasonal gap monitor | < 0.3 mm gap drift over full season | gap-monitor strip at one circumferential position | feeler gauges + photos | < 0.3 mm | structural-test | no | R-S-02 | 12-month observation window.
V-S-03 | structural | Keel-port keel deflection vs unported case | < 1.5x baseline deflection | beam analysis + MULE measurement | Wolfram + dial indicator | < 1.5x | structural-test | no | R-S-03 | Drives internal-brace decision.
V-S-04 | structural | Soundboard pull-test on scrap | 2x service load | attach test strip with hide glue + pull to failure | 5 kgf scale or load cell | glue holds to >= 2x service load | structural-test | yes | R-S-04 | Pre-build validation. Re-do if hide glue source changes.
V-S-05 | structural | Stern eyebolt pull-through | 30 kgf for 60 sec | attach eyebolt and load to 30 kgf | calibrated weight bag + load cell | no glue-line movement at 30 kgf for 60 sec | structural-test | yes | R-S-05 | SAM-19 / 25 / AE only. Pre-fly safety test.
V-A-01 | acoustic | SAM-13-MULE SPL at 1 m | within 6 dB of Wolfram prediction | SPL meter at 1 m off bow | calibrated SPL meter (Class 2 or better) | predicted +/- 6 dB | acoustic-test | no | R-A-01 | Quiet-instrument validation. Escalation paths defined in R-A-01.
V-A-02 | acoustic | Coupled cavity-plate pair signature | two peaks split by 30-80 Hz | sweep frequency response | small speaker + reference mic + DAW analysis | two distinct peaks in 100-300 Hz band | acoustic-test | no | R-A-03 | Per Wolfram coupled-system prediction.
V-A-03 | acoustic | Tuning drift at 24 hr playing-temperature | < +/- 10 cents per string | re-measure after 24 hr at room temperature | chromatic tuner | < +/- 10 cents | acoustic-test | no | R-A-02 | Catches cord-wrap creep.
V-A-04 | acoustic | Helmholtz frequency keel port | ~143 Hz +/- 15 Hz | impulse-response measurement at port | microphone + DAW | 128-158 Hz | acoustic-test | no | R-A-03 | Per Wolfram prediction for the SAM-13-ROOT geometry.
V-A-05 | acoustic | String-holder-strip exact position voicing | best balance of bass/treble response | move strip position incrementally on MULE; record SPL by frequency band | SPL meter + playback | position locked subjectively then re-measured | acoustic-test | yes | R-A-01 | Critical voicing step. Strip is glue-on-later for this reason.
V-J-01 | joint | Scarf-and-collar joint integrity at MULE | no visible separation at 30-day hold | visual + magnification | 10x loupe | no visible separation | structural-test | yes | R-S-01 | Confirms scarf glue line under reduced load.
V-J-02 | joint | Soundboard-to-hull seam under string load | no visible glue-line separation | visual at full tension | 10x loupe | no visible separation | structural-test | no | R-S-04 | Multi-strip lapis pocket may stress the seam.
V-J-03 | joint | String-holder strip hide-glue bond | full bond no rocking | visual + finger press | n/a | no movement under finger pressure | builder | no | R-S-04 | Confirms strip is fully glued before stringing.
V-E-01 | ergonomic | 30-minute playing session fatigue check | no muscle fatigue triggering posture drift | timed session with observer + post-session interview | observation + interview notes | player completes session without breaks; postural drift documented | ergonomic-test | no | R-E-01 | Documents recommended session length for user guide.
V-E-02 | ergonomic | Keel port impingement at three player postures | port radiates >= 80% of unblocked case | SPL meter at listener position with port unblocked vs typical seated | SPL meter | >= 80% radiation | ergonomic-test | no | R-E-02 | Drives documentation of recommended seated posture.
V-Z-01 | safety | Pre-performance harness check (SAM-25) | locking hook engaged + tested | visual + hook-load 5 kgf | small hand weight | hook locked and load-tested | player | no | R-Z-02 | Per-performance checklist.
V-Z-02 | safety | String breakage protection | fresh strings + 6-month replacement interval | inspect and document | visual | no fraying or wear visible | player | no | R-Z-01 | Per-restringing checklist in user guide.
V-C-01 | cultural | Cultural-provenance language advisor review | written sign-off OR revision accepted and re-submitted | submit design.md cultural-provenance section to advisor | n/a | advisor sign-off in writing | external advisor | yes | R-C-01 | One of three public-release gates.
V-C-02 | cultural | Imagery attribution audit | all cylinder-seal and BM photos captioned and credited | review every image in deck and site | visual review | every image credited correctly | documentarian | yes | R-C-03 | Catches the most common misappropriation issue.
V-C-03 | cultural | Sambyke etymological language review | advisor sign-off on the etymology paragraph | submit with V-C-01 | n/a | advisor accepts or revises | external advisor | yes | R-C-02 | Combined with V-C-01.
V-B-01 | brand | Heifer Zephyr placement option locked | Option A or B chosen and committed | Tony decision after cultural review | n/a | decision documented | Tony | yes | n/a | One of three public-release gates.
V-B-02 | brand | Brand inlay color match | inlay reads as intentional against base wood | finish-test sample compare | visual + photograph at neutral lighting | reads as intentional | builder + Tony | no | n/a | Pre-production sample.
# Three public-release gates (gate_block = yes and cultural/brand/structural):
# V-S-01 SAM-13-MULE neck-deflection 30-day hold
# V-T-02 SAM-13-ROOT calibrated tension (drives Wolfram sweep adjustment)
# V-C-01 Cultural-provenance advisor review
# V-B-01 Heifer Zephyr placement locked
#
# Voicing decision (V-A-05 / V-D-05): the string-holder strip position is determined
# empirically on the SAM-13-MULE before it is committed on the SAM-13-ROOT.
# The strip is mounted with hide glue precisely so this can be done reversibly.

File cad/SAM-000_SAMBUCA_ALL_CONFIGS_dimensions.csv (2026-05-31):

AssemblyConfigName | Component | ConfigName | FeatureName | FeatureType | DimFullName | Value_mm | Value_in | Tolerance_Type | IsDriven | IsLinked | IsGlobalVar | EquationOrComment
Default | SAM-000_MasterLayout-1 | Default | Side_Profile | ProfileFeature | D1@Side_Profile@SAM-000_MasterLayout.Part | 650.0114 | 25.5910 | N/A | TRUE | FALSE | FALSE
Default | SAM-000_MasterLayout-1 | Default | Side_Profile | ProfileFeature | D2@Side_Profile@SAM-000_MasterLayout.Part | 199.9996 | 7.8740 | N/A | TRUE | FALSE | FALSE
Default | SAM-000_MasterLayout-1 | Default | Side_Profile | ProfileFeature | D4@Side_Profile@SAM-000_MasterLayout.Part | 50.0126 | 1.9690 | N/A | TRUE | FALSE | FALSE
Default | SAM-000_MasterLayout-1 | Default | Side_Profile | ProfileFeature | D5@Side_Profile@SAM-000_MasterLayout.Part | 810.0060 | 31.8900 | N/A | TRUE | FALSE | FALSE
Default | SAM-000_MasterLayout-1 | Default | Side_Profile | ProfileFeature | D3@Side_Profile@SAM-000_MasterLayout.Part | 1.7453 | 0.0687 | N/A | TRUE | FALSE | FALSE
Default | SAM-000_MasterLayout-1 | Default | Side_Profile | ProfileFeature | D9@Side_Profile@SAM-000_MasterLayout.Part | 580.0090 | 22.8350 | N/A | TRUE | FALSE | FALSE
Default | SAM-000_MasterLayout-1 | Default | Side_Profile | ProfileFeature | D6@Side_Profile@SAM-000_MasterLayout.Part | 1047.1976 | 41.2283 | N/A | FALSE | FALSE | FALSE
Default | SAM-000_MasterLayout-1 | Default | Side_Profile | ProfileFeature | D7@Side_Profile@SAM-000_MasterLayout.Part | 199.9996 | 7.8740 | N/A | TRUE | FALSE | FALSE
Default | SAM-000_MasterLayout-1 | Default | Side_Profile | ProfileFeature | D8@Side_Profile@SAM-000_MasterLayout.Part | 13000.0000 | 511.8110 | N/A | FALSE | FALSE | FALSE
Default | SAM-000_MasterLayout-1 | Default | Side_Profile | ProfileFeature | D10@Side_Profile@SAM-000_MasterLayout.Part | 12.7000 | 0.5000 | N/A | FALSE | FALSE | FALSE
Default | SAM-000_MasterLayout-1 | Default | Boat_Bow_Elipse | ProfileFeature | D1@Boat_Bow_Elipse@SAM-000_MasterLayout.Part | 39.9999 | 1.5748 | N/A | TRUE | FALSE | FALSE
Default | SAM-000_MasterLayout-1 | Default | Boat_Bow_Elipse | ProfileFeature | D2@Boat_Bow_Elipse@SAM-000_MasterLayout.Part | 4.5004 | 0.1772 | N/A | TRUE | FALSE | FALSE
Default | SAM-000_MasterLayout-1 | Default | STN-20 | RefPlane | D1@STN-20@SAM-000_MasterLayout.Part | 130.0023 | 5.1182 | N/A | TRUE | FALSE | FALSE
Default | SAM-000_MasterLayout-1 | Default | STN-20_elipse | ProfileFeature | D1@STN-20@SAM-000_MasterLayout.Part | 130.0023 | 5.1182 | N/A | TRUE | FALSE | FALSE
Default | SAM-000_MasterLayout-1 | Default | STN-20_elipse | ProfileFeature | D1@STN-20_elipse@SAM-000_MasterLayout.Part | 175.9996 | 6.9291 | N/A | TRUE | FALSE | FALSE
Default | SAM-000_MasterLayout-1 | Default | STN-20_elipse | ProfileFeature | D2@STN-20_elipse@SAM-000_MasterLayout.Part | 58.5048 | 2.3033 | N/A | TRUE | FALSE | FALSE
Default | SAM-000_MasterLayout-1 | Default | STN-50 | RefPlane | D1@STN-50@SAM-000_MasterLayout.Part | 325.0057 | 12.7955 | N/A | TRUE | FALSE | FALSE
Default | SAM-000_MasterLayout-1 | Default | STN-50_elipse | ProfileFeature | D1@STN-50@SAM-000_MasterLayout.Part | 325.0057 | 12.7955 | N/A | TRUE | FALSE | FALSE
Default | SAM-000_MasterLayout-1 | Default | STN-50_elipse | ProfileFeature | D1@STN-50_elipse@SAM-000_MasterLayout.Part | 199.9996 | 7.8740 | N/A | TRUE | FALSE | FALSE
Default | SAM-000_MasterLayout-1 | Default | STN-50_elipse | ProfileFeature | D2@STN-50_elipse@SAM-000_MasterLayout.Part | 75.0062 | 2.9530 | N/A | TRUE | FALSE | FALSE
Default | SAM-000_MasterLayout-1 | Default | STN-80 | RefPlane | D1@STN-80@SAM-000_MasterLayout.Part | 520.0091 | 20.4728 | N/A | TRUE | FALSE | FALSE
Default | SAM-000_MasterLayout-1 | Default | STN-80_elipse | ProfileFeature | D1@STN-80@SAM-000_MasterLayout.Part | 520.0091 | 20.4728 | N/A | TRUE | FALSE | FALSE
Default | SAM-000_MasterLayout-1 | Default | STN-80_elipse | ProfileFeature | D1@STN-80_elipse@SAM-000_MasterLayout.Part | 183.9996 | 7.2441 | N/A | TRUE | FALSE | FALSE
Default | SAM-000_MasterLayout-1 | Default | STN-80_elipse | ProfileFeature | D2@STN-80_elipse@SAM-000_MasterLayout.Part | 63.7553 | 2.5101 | N/A | TRUE | FALSE | FALSE
Default | SAM-000_MasterLayout-1 | Default | STN-Stern | RefPlane | D1@STN-Stern@SAM-000_MasterLayout.Part | 650.0114 | 25.5910 | N/A | TRUE | FALSE | FALSE
Default | SAM-000_MasterLayout-1 | Default | STN-Stern_elipse | ProfileFeature | D1@STN-Stern@SAM-000_MasterLayout.Part | 650.0114 | 25.5910 | N/A | TRUE | FALSE | FALSE
Default | SAM-000_MasterLayout-1 | Default | STN-Stern_elipse | ProfileFeature | D1@STN-Stern_elipse@SAM-000_MasterLayout.Part | 123.9998 | 4.8819 | N/A | TRUE | FALSE | FALSE
Default | SAM-000_MasterLayout-1 | Default | STN-Stern_elipse | ProfileFeature | D2@STN-Stern_elipse@SAM-000_MasterLayout.Part | 41.2534 | 1.6242 | N/A | TRUE | FALSE | FALSE
Default | SAM-000_MasterLayout-1 | Default | Soundboard_Face | ProfileFeature | D1@Soundboard_Face@SAM-000_MasterLayout.Part | 150.0124 | 5.9060 | N/A | TRUE | FALSE | FALSE
Default | SAM-000_MasterLayout-1 | Default | Soundboard_Face | ProfileFeature | D2@Soundboard_Face@SAM-000_MasterLayout.Part | 12.7000 | 0.5000 | N/A | FALSE | FALSE | FALSE
Default | SAM-000_MasterLayout-1 | Default | Neck_Face | ProfileFeature | D1@Neck_Face@SAM-000_MasterLayout.Part | 37.9984 | 1.4960 | N/A | TRUE | FALSE | FALSE
Default | SAM-000_MasterLayout-1 | Default | [Equation 0] | Equation |  |  |  |  |  |  | TRUE | "body_length_in" = 25.591
Default | SAM-000_MasterLayout-1 | Default | [Equation 1] | Equation |  |  |  |  |  |  | TRUE | "body_width_in" = 5.906
Default | SAM-000_MasterLayout-1 | Default | [Equation 2] | Equation |  |  |  |  |  |  | TRUE | "body_depth_in" = 7.874
Default | SAM-000_MasterLayout-1 | Default | [Equation 3] | Equation |  |  |  |  |  |  | TRUE | "instrument_height_in" = 31.890
Default | SAM-000_MasterLayout-1 | Default | [Equation 4] | Equation |  |  |  |  |  |  | TRUE | "string_count" = 13
Default | SAM-000_MasterLayout-1 | Default | [Equation 5] | Equation |  |  |  |  |  |  | TRUE | "f_min_hz" = 196.0
Default | SAM-000_MasterLayout-1 | Default | [Equation 6] | Equation |  |  |  |  |  |  | TRUE | "f_max_hz" = 659.3
Default | SAM-000_MasterLayout-1 | Default | [Equation 7] | Equation |  |  |  |  |  |  | TRUE | "string_len_max_in" = 22.835
Default | SAM-000_MasterLayout-1 | Default | [Equation 8] | Equation |  |  |  |  |  |  | TRUE | "string_len_min_in" = 7.874
Default | SAM-000_MasterLayout-1 | Default | [Equation 9] | Equation |  |  |  |  |  |  | TRUE | "length_freq_exponent" = 0.85
Default | SAM-000_MasterLayout-1 | Default | [Equation 10] | Equation |  |  |  |  |  |  | TRUE | "slimness" = "body_length_in" / "body_width_in"
Default | SAM-000_MasterLayout-1 | Default | [Equation 11] | Equation |  |  |  |  |  |  | TRUE | "scale_factor" = "body_length_in" / 25.591
Default | SAM-000_MasterLayout-1 | Default | [Equation 12] | Equation |  |  |  |  |  |  | TRUE | "hull_wall_in" = 0.236
Default | SAM-000_MasterLayout-1 | Default | [Equation 13] | Equation |  |  |  |  |  |  | TRUE | "soundboard_thickness_in" = 0.118
Default | SAM-000_MasterLayout-1 | Default | [Equation 14] | Equation |  |  |  |  |  |  | TRUE | "neck_arc_length_in" = "instrument_height_in" - "body_depth_in" + 1.969
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

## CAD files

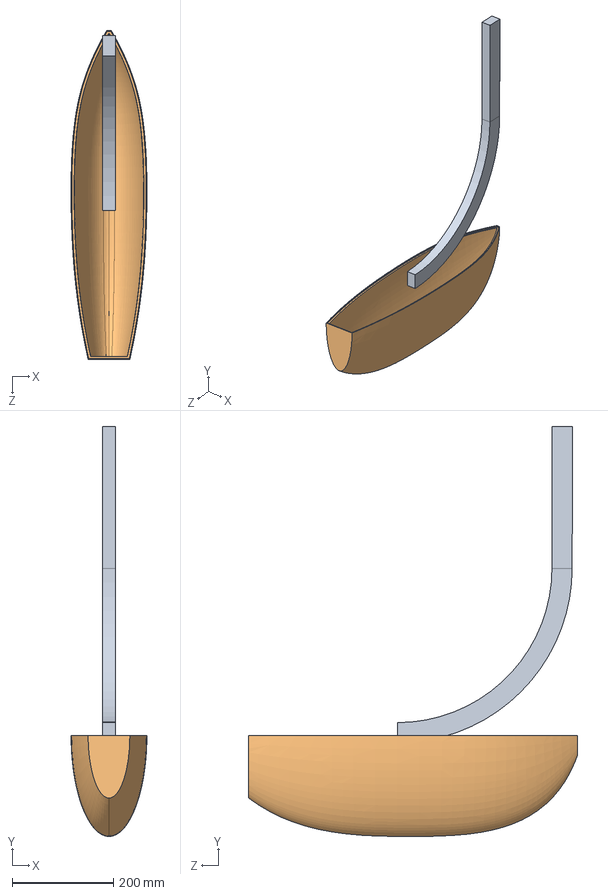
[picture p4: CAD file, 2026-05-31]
cad/SAM-000_SAMBUCA.SLDASM
150.0 x 810.0 x 650.0 mm
SAM-000_BoatBody
SAM-000_Neck

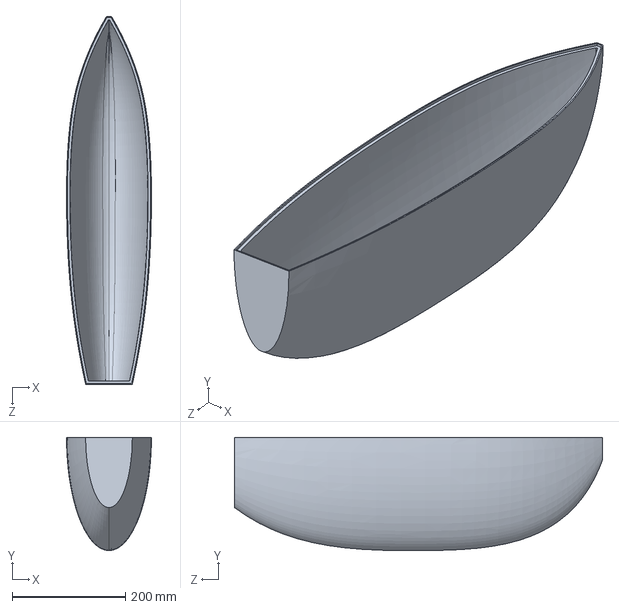
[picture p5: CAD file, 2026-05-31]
cad/SAM-000_BoatBody.SLDPRT
150.0 x 200.0 x 650.0 mm

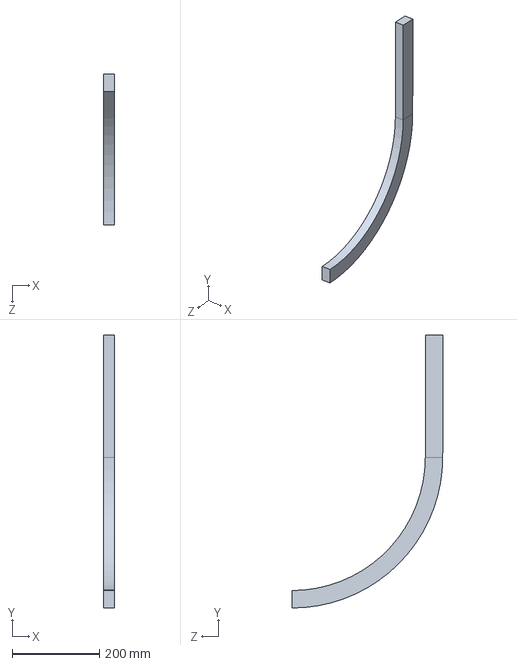
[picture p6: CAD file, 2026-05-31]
cad/SAM-000_Neck.SLDPRT
25.4 x 625.0 x 345.5 mm

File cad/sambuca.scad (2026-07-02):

// Sambuca parametric envelope master — boat-shaped arched harp (SAM family).
//
// Authority: pending_measurement. NOT fabrication authority. This is an
// independent OpenSCAD envelope generated from the authoritative global
// equations; it does NOT supersede the SolidWorks MasterLayout rebuild
// (cad/SW-MIGRATION-CHECKLIST.md) and carries no measured-template gates.
// See visual-output-register.csv and cad/mcp-session-log.md.
//
// Dimension sources (do NOT edit values without updating the source record):
//   - all nominal dimensions: cad/SAM-000_master-equations.txt (single
//     source of truth; variable names mirrored below in inches)
//   - family scale + string counts: family-spec.csv (5 variants)
//   - string-length model + tuning: master-equations.txt f*_hz / L*_in block
//     (length-frequency exponent 0.85; NOT modeled as geometry here, cited)
//   - hull depth ratio (D/L) commentary: design.md / family-spec release notes
//
// Units: inches (matches master-equations.txt). family-spec.csv is in mm.

/* [Family variant] */
// 0=SAM-13-ROOT, 1=SAM-19-MID, 2=SAM-25-CONCERT, 3=SAM-13-AE, 4=SAM-13-MULE
variant = 0;

// body_length per family-spec.csv (mm) → inches. SAM-13=650, SAM-19=850,
// SAM-25=1050 mm. AE/MULE share the SAM-13 envelope.
body_length_in_by_variant = [25.591, 33.465, 41.339, 25.591, 25.591];
string_count_by_variant    = [13, 19, 25, 13, 13];

body_length_in = body_length_in_by_variant[variant];
string_count   = string_count_by_variant[variant];

// scale_factor per master-equations.txt: body_length / 25.591 (SAM-13 root).
scale_factor = body_length_in / 25.591;

/* [Boat hull — master-equations.txt] */
body_width_in         = 5.906 * scale_factor;  // 150 mm at root
body_depth_in         = 7.874 * scale_factor;  // 200 mm at root (D/L ~0.31)
hull_wall_in          = 0.236;                 // hull wall thickness
soundboard_thick_in   = 0.118;                 // ~3 mm western red cedar

/* [Neck — curved cantilever, master-equations.txt] */
instrument_height_in  = 31.890 * scale_factor;
// neck_arc_length = instrument_height - body_depth + 1.969 (equations)
neck_arc_length_in    = instrument_height_in - body_depth_in + 1.969;
neck_curve_radius_in  = 0.5 * neck_arc_length_in;
neck_width_in         = 1.496;
neck_depth_in         = 1.969;
joint_collar_height_in = 2.362;

/* [String-holder strip — master-equations.txt] */
strip_x_from_stern_in = body_length_in * 0.80;
strip_length_in       = 4.724 * scale_factor;
strip_width_in        = 0.394;
strip_thick_in        = 0.157;
// string_spacing = strip_length / (string_count + 1)
string_spacing_in     = strip_length_in / (string_count + 1);
tie_hole_dia_in       = 0.059;

/* [Keel-port soundhole — master-equations.txt] */
keel_port_long_in     = 3.150 * scale_factor;
keel_port_short_in    = 1.969 * scale_factor;
keel_port_x_from_bow_in = body_length_in * 0.55;

$fn = 64;

// ---------------------------------------------------------------------------
// Modules (formulas, not baked values)
// ---------------------------------------------------------------------------

module boat_hull() {
  // Half-ellipsoid hull, open top, hollowed to hull_wall_in.
  difference() {
    // outer hull: half-ellipsoid (lower half)
    scale([body_length_in / 2, body_width_in / 2, body_depth_in])
      difference() {
        sphere(r = 1);
        translate([0, 0, 1]) cube(2, center = true); // keep lower half
      }
    // inner cavity
    scale([(body_length_in / 2 - hull_wall_in),
           (body_width_in / 2 - hull_wall_in),
           (body_depth_in - hull_wall_in)])
      difference() {
        sphere(r = 1);
        translate([0, 0, 1]) cube(2, center = true);
      }
  }
}

module soundboard() {
  // Elliptical top plate closing the hull, with the keel-port cut.
  difference() {
    scale([body_length_in / 2, body_width_in / 2, 1])
      cylinder(h = soundboard_thick_in, r = 1, center = false);
    // keel port: elliptical, forward of center toward the bow (+x)
    translate([keel_port_x_from_bow_in - body_length_in / 2, 0, -0.05])
      scale([keel_port_long_in / 2, keel_port_short_in / 2, 1])
        cylinder(h = soundboard_thick_in + 0.2, r = 1);
  }
}

module string_holder_strip() {
  // Near the bow (+x), string tie strip; tie holes at string_spacing.
  translate([strip_x_from_stern_in - body_length_in / 2,
             -strip_length_in / 2, soundboard_thick_in]) {
    difference() {
      cube([strip_width_in, strip_length_in, strip_thick_in]);
      for (i = [1 : string_count])
        translate([strip_width_in / 2, i * string_spacing_in, -0.05])
          cylinder(h = strip_thick_in + 0.1, d = tie_hole_dia_in);
    }
  }
}

module neck_arc() {
  // Curved cantilever neck approximated as a torus quarter-segment rising
  // from the stern (-x) end. Radius from master-equations neck_curve_radius.
  R = neck_curve_radius_in;
  translate([-body_length_in / 2, 0, body_depth_in * 0.1])
    rotate([90, 0, 0])
      rotate_extrude(angle = 110, $fn = 96)
        translate([R, 0, 0])
          square([neck_depth_in, neck_width_in], center = true);
}

module string_lines() {
  // Visual string paths from strip tie holes toward the neck head.
  head = [-body_length_in / 2 - neck_curve_radius_in * 0.2,
          0, body_depth_in + neck_arc_length_in * 0.5];
  for (i = [1 : string_count]) {
    p0 = [strip_x_from_stern_in - body_length_in / 2 + strip_width_in / 2,
          -strip_length_in / 2 + i * string_spacing_in,
          soundboard_thick_in];
    hull() {
      translate(p0) sphere(r = 0.02);
      translate(head + [0, p0[1] * 0.1, 0]) sphere(r = 0.02);
    }
  }
}

module sambuca_assembly() {
  boat_hull();
  translate([0, 0, 0]) soundboard();
  string_holder_strip();
  neck_arc();
  string_lines();
}

sambuca_assembly();

// Echo the string tuning + length table so `openscad` doubles as a check
// (frequencies + modeled string lengths per master-equations.txt).
f_min_hz = (variant == 2) ? 110.0 : (variant == 1) ? 146.8 : 196.0;
semitone_steps = [0, 2, 4, 5, 7, 9, 11, 12, 14, 16, 17, 19, 21];
for (n = [0 : min(string_count, len(semitone_steps)) - 1])
  echo(str("string_", n + 1, "_hz=", f_min_hz * pow(2, semitone_steps[n] / 12)));
echo(str("string_spacing_in=", string_spacing_in,
         " scale_factor=", scale_factor));

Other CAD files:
cad/SAM-000_MasterLayout.SLDPRT
cad/SAM-000_MasterPart.SLDPRT

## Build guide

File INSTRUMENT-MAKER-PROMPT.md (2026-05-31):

# Instrument-Maker-v4 Handoff Prompt

Paste the block below into a fresh Cowork session to kick off the full build packet for the sambuca via the `instrument-maker-v4` skill.

---

## The prompt (copy from here)

> /instrument-maker-v4
>
> I want to build the **full v4 instrument packet** for the **sambuca** — a modern boat-shaped arched harp inspired by the Royal Cemetery of Ur (~2600 BC). The reverse-engineering phase is complete; the repo is at `C:\Users\Tony\Documents\GitHub\sambuca\`. Treat that repo as the canonical design input.
>
> **Read first, before doing anything else:**
> - `C:\Users\Tony\Documents\GitHub\sambuca\README.md` — project intro and packet map.
> - `C:\Users\Tony\Documents\GitHub\sambuca\reverse-engineering.md` — locked taxonomy (boat-shaped arched harp, NOT a lyre), BM 121198 anchor dimensions, fingerprint elements, design freedom map.
> - `C:\Users\Tony\Documents\GitHub\sambuca\design.md` — soundhole-at-keel rationale, neck-joint trade study, harness logic for larger variants, Broinwood inlay program.
> - `C:\Users\Tony\Documents\GitHub\sambuca\family-spec.csv` — five planned variants (SAM-13-ROOT, SAM-19-MID, SAM-25-CONCERT, SAM-13-AE, SAM-13-MULE).
> - `C:\Users\Tony\Documents\GitHub\sambuca\cad\SAM-000_master-equations.txt` — global equations driving the parametric model. **Note the tension calibration warning** in that file (starter ramp produces 103 kgf total on SAM-13; target is 65–80; adjust diameters or bass material).
> - `C:\Users\Tony\Documents\GitHub\sambuca\cad\SW-MIGRATION-CHECKLIST.md` — current SolidWorks state and Path A rebuild plan.
> - `C:\Users\Tony\Documents\GitHub\sambuca\wolfram\sambuca-acoustics-starter.wl` — acoustic study starter.
> - `C:\Users\Tony\Documents\GitHub\sambuca\harness\README.md` — harness designs for the larger family variants.
> - `C:\Users\Tony\Documents\GitHub\kora\` — pattern reference; use its packet map as the structural template since I asked you to follow kora's pattern, not the conga/fujara variant.
>
> **Build the full root-mode v4 packet, mirroring the kora repo:**
> - `design.md` — extend the existing one with v4 design intent, workbook interpretation, physics model, cultural provenance language (Sumerian pattern, 4500 years public domain, **not** a claim against any modern living tradition).
> - `bom.csv` — make/buy materials and hardware with planning-estimate cost flags. Cover all five family variants where they differ.
> - `sourcing.csv` — spec-first table; do **not** verify live prices, flag the assumption.
> - `cut-list.csv` — rough and final dimensions for the boat hull (stave-laminated or CNC-from-block — propose both options), curved neck (laminated bend then CNC), brass collar, bridge, keel-port surround, stern eyebolt backing plate, stand, fixtures, templates.
> - `validation.csv` — dimensional, string-tension, acoustic, joint-strength, safety, and cultural checks. Include the bridge-position decision (Reading A tailpiece vs. Reading B bow-side bridge) as an explicit validation step on the prototype.
> - `assembly-manual.md` — staged build method with hold points before full string tension. Critical: a tension-up checkpoint before the final 13-string installation.
> - `risks.md` — red-team concerns. Top items I expect to see: neck cantilever failure under full tension, brass-collar mixed-material seasonal movement, keel-port placement vs. structural keel stiffener, harness rated-load for SAM-25.
> - `supplier-rfq.md` — RFQ drafts for wood, brass, strings, tuners (geared guitar-style hidden behind gold-tone caps), lapis-lazuli-look composite or dyed-veneer-and-epoxy inlay stock, harness hardware.
> - `drawing-brief.md` and `visual-bom-brief.md` — drawing and visual asset list.
> - `wolfram/sambuca-acoustics-starter.wl` — extend the existing notebook with soundboard plate-mode estimator and combined cavity × plate response.
> - `photo-shotlist.md` — shop and documentation shots.
> - `capstone-deck.md` and `capstone-deck.pptx` — full presentation outline + slides. Cover: history (BM 121198, Pu-abi's tomb, Royal Cemetery), design freedom argument, family spec, parametric SolidWorks workflow, acoustic study results, build sequence, finished prototype.
> - `capstone-manifest.json` — artifact inventory.
> - `print-packet.md`, `print-packet.html`, `print-packet.pdf` — print-friendly shop packet.
> - `site/index.html` — self-contained build-log site, marked private-review until release.
> - `drawings/`, `cad/`, `cnc/` — add operational placeholders and briefs; do not duplicate the existing master equations file.
> - `learn-to-play/` — empty placeholder; downstream `sheet-music` skill will populate once the tuning system is locked.
>
> **Family-variant treatment:**
> All five members (SAM-13-ROOT, SAM-19-MID, SAM-25-CONCERT, SAM-13-AE, SAM-13-MULE) come from one MasterLayout driven by `body_length_mm` and `string_count`. Treat SAM-13-ROOT as the build target; document the others as Pack-and-Go siblings (mirror the fujara → moseno pattern).
>
> **Public release status:**
> Keep this repo **private-review** until:
> - Cultural advisor or musicology review of the provenance language (the Sumerian pattern is public domain, but the "sambuca" name has Hellenistic Greek associations that should be acknowledged).
> - Tension and joint validation on the SAM-13-MULE test build.
> - Brand integration with the Heifer Zephyr wordmark + bison mark, per the memory.
>
> **Things I have already decided — don't re-litigate:**
> - The instrument is a boat-shaped arched harp ("sambuca"), not a lyre. BM curator agrees.
> - Soundhole is at the **keel** (bottom of the hull), projecting forward/down toward the listener. Single oval 80×50 mm for SAM-13-ROOT, scaled by `scale_factor` for larger family members.
> - Tuners are **geared guitar-style hidden behind gold-tone (PVD brass) bulb caps** that visually echo the original gold tuning pegs.
> - Inlay is **Broinwood-style CNC**, parametrically driven from the master sketches; lapis-lazuli-look composite or dyed-veneer-and-epoxy as material.
> - Strings: fluorocarbon trebles, wound nylon basses (specific schedule still being calibrated).
> - SAM-19 gets a low-back positioning belt; SAM-25 gets a saxophone-style shoulder harness; SAM-13 needs no harness.
> - Stand is a CNC-curve-profiled cradle with Japanese **kanawa-tsugi** or **mitsuke-aritsugi** joinery at straight intersections.
> - Brand: **Heifer Zephyr** wordmark with italic-serif treatment per Tony's brand memory; placement open (soundboard inlay or stand-only — propose both).
>
> **Open questions you should raise with me, not assume:**
> - Performance tuning for SAM-13-ROOT: G-major (G3 to E5) or A-major (A3 to F#5)?
> - Mirror handedness: left- or right-handed default, with the other as a mirror configuration?
> - Bridge position: design for Reading A (tailpiece-stern) or Reading B (bow-side bridge), or build a repositionable test bridge for the SAM-13-MULE?
> - Wood pairing for hull / soundboard / neck: cherry-spruce-maple, walnut-cedar-sapele, or all-walnut? My instinct is the middle option for warmth.
> - Public-release timeline: am I targeting the spring or fall capstone window?
>
> **Output discipline:**
> - Mark every assumption explicitly. Don't invent dimensions; if you need one I haven't specified, ask.
> - Cost estimates are planning-only; flag as such.
> - Keep the cultural-provenance language honest: this is *inspired by* the Sumerian pattern, *not* a reproduction.
> - Use the kora repo as your structural template; the conga and fujara repos have valid but different conventions.
>
> Let's start by you reading the eight files above, then proposing the packet build order and asking me the open questions before generating files. I'd rather you ask twice than generate the wrong slate.

---

## Notes for the next session

When you (Tony) paste this prompt into a fresh Cowork session, the instrument-maker-v4 skill will:

1. Read all the files cited.
2. Ask you the open questions.
3. Propose a packet build order.
4. Generate the files iteratively, marking estimates and assumptions.

If the skill jumps ahead and generates files without asking, push back — the kora packet earned its quality from the same disciplined gate-by-gate flow.

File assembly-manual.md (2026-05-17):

# Sambuca — Assembly Manual (SAM-13-ROOT build target)

Staged build method with hold points before full string tension. The critical hold point is the **MULE tension validation** before any production SAM-13-ROOT is strung to full load.

Estimated active build time: 60–90 hours over 6–10 weeks. Plus a 30-day MULE hold for tension validation.

> This manual covers the SAM-13-ROOT build target. SAM-19-MID and SAM-25-CONCERT follow the same sequence with `scale_factor` substitutions from `family-spec.csv` and the master-equations. SAM-13-AE adds the electronics stage between Stages 9 and 10. SAM-13-MULE is the same as SAM-13-ROOT but uses reduced-tension string set and is the validation precursor.

---

## Stage 0 — Pre-build (Week 1)

- [ ] Review `design.md`, `risks.md`, `cad/SAM-000_master-equations.txt`.
- [ ] Confirm wood pairing (walnut hull / cedar soundboard / sapele neck) — visually match the hull, stand, and stub-foot stock so they read as a single set.
- [ ] Place sourcing orders per `sourcing.csv`. PVD-gold-tone bulb caps (BOM-018) is the longest lead — start that first.
- [ ] Mock-fit one geared tuner sample into a neck-cross-section dummy. If `neck_depth_mm` is too tight, re-spec before cutting CUT-009.
- [ ] Build the fixtures from `cut-list.csv` CUT-201 through CUT-205: laminating jig, soundboard pull-test fixture, neck-deflection jig, string-holder-strip positioning fixture, soundboard inlay template.

**Hold point:** Do not cut production stock until the tuner fit check (R-X-04) is resolved.

---

## Stage 1 — Hull (Weeks 2–3)

Choose one of two hull paths per `cut-list.csv`:

### Path A — CNC-from-block (CUT-001a)

1. Load walnut billet (200 × 200 × 700 mm) onto CNC bed with vacuum chuck or machinable fixture.
2. First pass: rough hollow with 1/4 in 2-flute upcut, ~0.5 mm material left for finishing.
3. Second pass: finishing pass with 1/8 in ball mill, leaving `hull_wall_mm` = 6 mm wall thickness.
4. Flip and second-side: top-profile cut (soundboard rebate), keel-port pre-positioned but not cut through yet.
5. Remove from fixture; clean machining marks; verify wall thickness with calipers at three locations (V-D-03 dependency).

### Path B — Stave-laminated (CUT-001b)

1. Mill 10 walnut staves to 60 × 20 × 650 mm.
2. Bevel mating edges for the half-ellipsoid hull shape (compound miter math; reference the Top Profile and Side Profile sketches).
3. Bend and glue around a buck form (the buck is a one-time MDF fixture, similar to CUT-204 but for the hull).
4. Cure 48 hours under banding straps.
5. CNC clean-up pass on the laminated shell: final wall thickness, soundboard rebate, scarf-cut location.

> Both paths converge here. The remainder of the manual is hull-option-agnostic.

6. Glue the stern stub feet (CUT-004) to the keel interior near the stern. Two feet, ~30 × 25 × 15 mm walnut blocks, on either side of the keel centerline. Use Titebond III + clamping; cure 4 hours.

**Hold point:** Hull-wall thickness verified to 6 ± 0.5 mm at midship, bow, and stern. Stub feet glued and pinned. Hull is now ready for soundboard fitting.

---

## Stage 2 — Neck blank (Weeks 2–3, parallel with Stage 1)

1. Rip sapele to three 12 × 38 × 810 mm laminate strips (CUT-009).
2. Set up the laminating jig (CUT-204) to the `neck_curve_radius_mm` curve. Coat mating faces with Titebond III. Clamp the three laminates around the form.
3. Cure 24 hours minimum, ideally 48 hours.
4. Remove from jig. Final laminate dimensions ≈ 38 × 38 × 810 mm.
5. Mount on CNC fixture (custom curved fixture, may need 3-axis with rotary indexing).
6. Sweep CNC operation to produce the swept neck cross-section along the `Neck Curve Path`.
7. Cut the scarf at the neck base (CUT-012) — 8:1 scarf, 80 mm long.
8. Drill the tuner-mounting holes per the neck-face linear pattern (13 holes at `s_n_neck` arc-length distances from the joint reference, Φ12 mm).
9. Sand and pre-finish the neck.

**Hold point:** Neck blank is structurally complete. Tuner holes drilled. Scarf cut.

---

## Stage 3 — Soundboard (Week 3)

1. Plane / sand cedar QSAAA soundboard to final 3 mm thickness (CUT-005).
2. Glue light fan-brace pattern (4 cedar braces, 3 × 8 mm cross-section, radiating from where the string-holder strip will sit toward the inlay band — CUT-006). Use hot hide glue for reversibility; cure 4 hours.
3. CNC cut the multi-strip lapis pocket (CUT-023) along the soundboard-hull seam — 5 parallel passes with the 0.8–1.0 mm end mill.
4. CNC cut the bow-end inlay panel pocket (CUT-026) — 100 × 60 × 1.5 mm.
5. *Heifer Zephyr Option A only:* CNC cut the wordmark pocket (CUT-027) stern of the string-holder strip position.

**Hold point:** Soundboard is dimensioned, braced, and has all inlay pockets cut. Do not glue inlay yet.

---

## Stage 4 — Hull seam scarf joint and brass collar (Week 4)

1. Cut the hull mating scarf (CUT-013) at the stern (where the neck joins). Reciprocal of the neck scarf.
2. Dry-fit the neck scarf into the hull. Verify alignment along the body centerline.
3. Cut the brass collar tube (CUT-014) — 60 mm tall, slip-fit over the scarf joint.
4. Test-fit the brass collar over the dry-assembled scarf. Mark and drill the through-collar dowel hole (CUT-015).
5. Polish or chemically-age the brass collar per R-F-02 (do the side-by-side finish test on a sample first).
6. Disassemble. Apply epoxy to scarf faces. Re-assemble with the brass collar in position. Insert the stainless 6 mm pin through both members (CUT-016). Clamp.
7. Cure 24 hours.

**Hold point:** Neck and hull are now permanently joined. The scarf-and-collar joint is the most critical structural element — confirm V-J-01 visual check at 24 hours and again at 48 hours before stringing.

---

## Stage 5 — Soundboard installation (Week 4)

1. Dry-fit the soundboard into the hull's soundboard rebate.
2. Glue the soundboard to the hull with Titebond III around the entire seam. Clamp around the perimeter; cure 8 hours.
3. Once cured, glue the multi-strip lapis inlay strips into the band pocket (CUT-024 + CUT-025) — alternating lapis-blue veneer strips with holly/maple spacers per `inlay_strip_count`. Fill with tinted epoxy (BOM-012); scrape flush after cure.
4. Glue the bow-end inlay panel (BOM-007) into its pocket. Fill any seam with tinted epoxy; scrape flush.
5. *Heifer Zephyr Option A only:* glue the wordmark inlay into the soundboard pocket.
6. Sand entire soundboard flush; apply thin shellac or oil finish (BOM-037).

**Hold point:** Soundboard is sealed and inlaid. Do not install the string-holder strip yet — that is a voicing decision deferred to Stage 9.

---

## Stage 6 — Keel port (Week 5)

1. Mark the keel port position from `keel_port_x_from_bow_mm` and the centerline of the keel.
2. CNC or jigsaw the oval cut (CUT-018) — 80 × 50 mm major × minor. Cut at the `keel_port_forward_tilt_deg` chamfer angle (15°) to bias forward radiation.
3. Sand the port edges smooth.
4. *Optional:* fit the walnut binding strip (CUT-017) around the port perimeter. Steam-bend over a form to match the oval, glue with Titebond III.

**Hold point:** Keel port cut. If the keel-deflection check (V-S-03) shows concerning numbers in the Wolfram model, install the internal transverse braces (CUT-002 and CUT-003) fore and aft of the port now, while the soundboard is still off — but the soundboard is already on. **Decision point:** if braces are needed, cut access through the keel port. Otherwise skip.

---

## Stage 7 — Stand (Week 5, parallel)

1. CNC-curve-profile the two stand uprights (CUT-020) to match the keel curvature.
2. CNC-cut the stand base (CUT-021) — 275 × 120 × 60 mm walnut.
3. Cut the kanawa-tsugi key slots (CUT-022) where the uprights meet the base. The kanawa-tsugi joint exposes the keys on the front face.
4. Dry-fit. Adjust until the boat rests squarely on the cradle with the soundboard horizontal.
5. Glue the base assembly. Cure 4 hours.
6. *Heifer Zephyr Option B only:* CNC the wordmark pocket (CUT-028) in the front face of the stand base. Inlay matching lapis or contrasting material. Sand flush.
7. Apply oil + wax finish to the stand.

---

## Stage 8 — Tuners and decorative wraps (Week 6)

1. Install the 13 geared guitar tuners into the neck-face holes. Internal gear housing sits inside the neck; output shaft protrudes ~5 mm.
2. For each tuner, install the decorative cord wrap (BOM-019) at the base of the shaft — ~8 turns of waxed silk or sinew-look cord. Tie off cleanly.
3. Install the PVD-gold-tone brass bulb caps (BOM-018) over each tuner output shaft. Friction-fit with a small dab of epoxy on the inside to prevent rotation.
4. *Top of neck only:* install the gold cap finial at the top of the neck.

**Hold point:** All 13 tuners installed with caps and wraps visible. The visual fingerprint is now in place.

---

## Stage 9 — String-holder strip and prototype voicing (Week 7) [CRITICAL]

This stage is where the MULE-vs-ROOT validation distinction matters.

### For SAM-13-MULE (validation precursor)

1. Set the string-holder-strip positioning fixture (CUT-203) on the soundboard.
2. Glue the string-holder strip (CUT-007) at the initial position (`strip_x_from_stern_mm` = 80% of body length). Hide glue, reversible.
3. Install the **reduced-tension** MULE string set (3.0–4.5 kgf/string × 13 = ~50 kgf total).
4. Tune to standard pitch (G-major). Let settle 24 hours.
5. Measure SPL across the string range per V-A-01.
6. If voicing is wrong, *remove the strip* (hide glue softens with warm water and steam), reposition by 10–20 mm, re-glue, re-string, re-measure.
7. Iterate up to 3 strip positions across the bow band.
8. Lock the final SAM-13-MULE strip position. Record the offset from stern.

### For SAM-13-ROOT (production build)

1. Use the MULE-verified strip position. Glue the strip with hide glue.
2. Do NOT install strings yet. See Stage 10.

---

## Stage 10 — MULE tension validation and ROOT stringing [CRITICAL — public-release gate]

### MULE 30-day hold

1. SAM-13-MULE: tune to MULE spec (~50 kgf total).
2. Mount the neck-deflection jig (CUT-202 + BOM-043). Record dial indicator zero.
3. Hold for **30 days**.
4. Check dial indicator every 7 days for deflection.
5. **Pass criterion:** deflection ≤ 2 mm at the gold cap relative to the body (V-S-01). No audible creak. No glue-line separation (V-J-01).
6. If pass: proceed to SAM-13-ROOT stringing.
7. If fail: redesign the scarf-and-collar joint per R-S-01. Document failure mode.

### SAM-13-ROOT stringing

1. SAM-13-ROOT: install the calibrated full-tension string set (BOM-014 fluorocarbon trebles + BOM-015 wound nylon basses), targeting 65–80 kgf total.
2. Bring up tension **gradually** — 25% / 50% / 75% / 100% in steps of 24 hours each. Re-tune at each step.
3. At 100% tension, hold 7 days. Re-measure tension per V-T-02 and tuning stability per V-T-03.
4. If total tension exceeds 80 kgf, swap bass strings 1–4 to higher-μ wound stock or shorten `string_len_max_mm` per the calibration plan in `design.md`.

**Hold point — public-release-blocking:** V-S-01 (neck deflection) must pass on the MULE before any SAM-13-ROOT is brought to full tension.

---

## Stage 11 — Final voicing, acoustic measurement (Week 9)

1. Sweep frequency response on the SAM-13-ROOT per V-A-02. Confirm coupled cavity-plate pair signature in the 100–300 Hz band.
2. Measure Helmholtz frequency at the keel port per V-A-04. Should be ~143 ± 15 Hz.
3. Measure SPL at 1 m per V-A-01. Compare to Wolfram prediction; flag if more than 6 dB below.
4. 30-minute playing session ergonomic check per V-E-01. Document session length and posture.
5. Pre-performance harness check (SAM-25 only) per V-Z-01.

---

## Stage 12 — Documentation and brand integration (Week 10)

1. Capture photo set per `photo-shotlist.md`. Hero shots, detail shots, in-playing-position shots.
2. Update `validation.csv` with measured values.
3. Update the `wolfram/sambuca-acoustics-starter.wl` notebook with measured-vs-predicted comparison.
4. Submit `design.md` cultural-provenance section to advisor for V-C-01 review.
5. Lock Heifer Zephyr brand placement (Option A or B) per V-B-01.
6. Final QA: verify all `validation.csv` rows are complete with measured values or marked-as-deferred.

---

## Public-release gate checklist

Before flipping the repo from private-review to public:

- [ ] V-S-01 SAM-13-MULE neck-deflection 30-day hold passed.
- [ ] V-T-02 SAM-13-ROOT calibrated-tension target hit (65–80 kgf).
- [ ] V-C-01 Cultural-provenance advisor review signed off.
- [ ] V-B-01 Heifer Zephyr placement option locked.
- [ ] R-S-05 SAM-25 eyebolt pull-test passed (if SAM-25 is in scope for the release).
- [ ] All `validation.csv` cultural-category rows (V-C-01, V-C-02, V-C-03) closed.
- [ ] `site/index.html` private-review banner removed.
- [ ] `README.md` updated to public-release language.

## Build-log captures (for site/index.html)

Photograph progress at the end of each stage. The build-log site pulls images from `images/` and re-renders the timeline. Captions per `photo-shotlist.md`.

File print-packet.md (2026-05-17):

# Sambuca — Shop Packet (Print Edition)

**Build target:** SAM-13-ROOT — 650 mm boat-shaped arched harp, 13 strings, G-major.
**Status:** private review (pending three release gates).
**Packet version:** instrument-maker-v4, generated 2026-05-16.

> This is the printable shop packet. Take it to the bench. Cross-reference back to the live files in the repo when in doubt.

---

## File map (one-page reference)

| File | Purpose | Take to bench? |
|---|---|---|
| `design.md` | Design intent, fingerprint, soundhole strategy, cultural provenance | reference only |
| `reverse-engineering.md` | Source-material analysis | reference only |
| `family-spec.csv` | 5-variant table | reference only |
| `risks.md` | Red-team risk register with verification tests | check before each stage |
| `bom.csv` | Make/buy materials and hardware | yes — ordering |
| `sourcing.csv` | Candidate suppliers, planning prices | yes — ordering |
| `cut-list.csv` | Rough and final dimensions for every cut | **yes — bench** |
| `validation.csv` | Dimensional, tension, acoustic, joint, safety, cultural checks | **yes — bench** |
| `assembly-manual.md` | 12-stage build sequence with hold points | **yes — bench** |
| `supplier-rfq.md` | RFQ drafts to send out | yes — ordering |
| `drawing-brief.md` | Drawing-package spec | reference only |
| `cad/SAM-000_master-equations.txt` | Global equations (source of truth) | reference only |
| `cnc/cnc-plan.md` | Pre-CAM operation plan per part | **yes — bench** |
| `wolfram/sambuca-acoustics-starter.wl` | Acoustic study notebook | reference only |
| `photo-shotlist.md` | Capture list across the build | each stage |
| `harness/README.md` | SAM-19 + SAM-25 harness design | only for those variants |
| `capstone-deck.pptx` | Capstone presentation | not in shop |
| `site/index.html` | Build-log site (private until release) | not in shop |

---

## Design intent (one paragraph)

Modern parametric family-scalable boat-shaped arched harp that preserves the Sumerian visual fingerprint (gold-flared cap, 13 bulb pegs with cord wraps, J-curve neck, multi-strip lapis band, brass collar, bow-end inlay panel, two stern stub feet) while delivering modern playability (geared tuners hidden behind decorative caps, calibrated fluorocarbon + wound-nylon string set at 65–80 kgf, keel-port soundhole projecting forward toward the listener, CNC-machined hull/neck/inlay, kanawa-tsugi stand). Build target SAM-13-ROOT; four siblings (SAM-19-MID, SAM-25-CONCERT, SAM-13-AE, SAM-13-MULE) derive from the same MasterLayout via `body_length_mm` and `string_count`.

## Cultural provenance — for the public-release language

Inspired by the Sumerian boat-shaped arched harp from BM 121198 (Royal Cemetery at Ur, c. 2600 BC, ~4500 years old, public domain). Not a reproduction, not a recreation of any specific surviving artifact, not a claim of cultural authority over any modern living tradition. The Hellenistic Greek *sambykē* (σαμβύκη) etymological link is historically contested; the build uses the term while acknowledging the uncertainty.

---

## Family-spec summary

| ID | Body length | Strings | Tuning | Total tension | Harness |
|---|---|---|---|---|---|
| **SAM-13-ROOT** | 650 mm | 13 | G3 → E5 | 65–80 kgf | none |
| SAM-19-MID | 850 mm | 19 | D3 → G5 | ~100 kgf est. | low-back belt |
| SAM-25-CONCERT | 1050 mm | 25 | A2 → A5 | ~120 kgf est. | sax harness |
| SAM-13-AE | 650 mm | 13 | G3 → E5 | 65–80 kgf | none + piezo |
| SAM-13-MULE | 650 mm | 13 | G3 → E5 (reduced T) | 40–50 kgf | none |

---

## Wood pairing (locked)

| Component | Species |
|---|---|
| Hull (and stand) | Walnut — FAS quartersawn 8/4 |
| Soundboard | Western red cedar — quartersawn AAA 3 mm (Wolfram-sweep 2.5–4.0) |
| Neck | Sapele — three 12 mm laminates around a curved form |
| String-holder strip | Walnut or hard maple |
| Bracing | Cedar (matches soundboard movement) |

---

## BOM summary (SAM-13-ROOT)

See full `bom.csv` for all 44 lines and per-variant deltas. Headline cost: planning estimate **$530–1300 USD** for SAM-13-ROOT, prices not live-verified.

Highest-risk supply items:

- **BOM-018** PVD-gold-tone brass bulb caps (13) — custom part, longest lead. Parallel two-shop search.
- **BOM-017** Geared guitar tuners (13) — mock-fit one sample before bulk order to verify `neck_depth_mm` clearance.
- **BOM-007** Bow-end inlay panel (mother-of-pearl or composite) — three-candidate sample compare before commit.

## Sourcing summary

Spec-first table in `sourcing.csv`. Three candidate suppliers per line. **No live prices verified — confirm before ordering.**

Order in this sequence to fit the 6–10 week build:

1. Week 1: PVD bulb caps (3–5 week lead) + walnut hull stock (2–4 weeks).
2. Week 2: sapele neck stock, cedar soundboard, tuners (mock-fit first).
3. Week 3: brass collar tube, eyebolts, string sets (after Wolfram sweep).
4. Week 4: inlay materials.

---

## Cut-list (build-target subset)

Full table in `cut-list.csv`. Highlights:

| Cut ID | Part | Final dims | Material | Notes |
|---|---|---|---|---|
| CUT-001a or CUT-001b | Hull | 650 × 150 × 150 mm, wall 6 mm | Walnut | A: CNC-from-block. B: stave-laminated. Pick one. |
| CUT-009 + CUT-011 | Neck blank | ~810 mm arc, 38 × 38–50 mm cross-section | Sapele 3-laminate | Glue → cure 48 hr → CNC sweep |
| CUT-005 | Soundboard | 650 × 150 × 3 mm | Cedar QSAAA | Final after sanding |
| CUT-007 | String-holder strip | 120 × 10 × 4 mm | Walnut or maple | Glued **after voicing** on MULE |
| CUT-018 | Keel port | 80 × 50 mm oval, 15° forward tilt | (cut from hull) | Stage 6 |
| CUT-014 | Brass collar | 60 mm tall, ~1 mm wall | Brass tube | Aged or polished per R-F-02 |
| CUT-023 | Multi-strip lapis inlay pocket | 5 × 1.5 mm strips + 4 × 0.8 mm spacers | (route in soundboard) | 0.8 mm end mill |
| CUT-026 | Bow-end inlay panel pocket | 100 × 60 × 1.5 mm | (route in soundboard) | Per `bow_panel_x_from_stern_mm` |

---

## Drawing brief callout

Minimum drawings required for the Fall 2026 capstone (see `drawing-brief.md` for the full 22-sheet list):

- Sheet 01 — Overview front
- Sheet 02 — Overview side (shows bow lift + keel port)
- Sheet 10 — Soundboard inlay program
- Sheet 18 — Family overview

Source of truth: `cad/SAM-000_master-equations.txt`. SVGs are generated from SolidWorks once the rebuild per `cad/SW-MIGRATION-CHECKLIST.md` clears.

---

## Assembly stages (one-line summary each)

| # | Stage | Hold? | Critical risk |
|---|---|---|---|
| 0 | Pre-build (sourcing, fixtures, tuner mock-fit) | yes — R-X-04 mock-fit before cutting stock | — |
| 1 | Hull (Path A or Path B) | yes — wall thickness verified | R-S-04 |
| 2 | Neck blank (laminate + CNC sweep) | yes — scarf cut clean | R-S-01 |
| 3 | Soundboard (3 mm cedar, fan brace, inlay pockets cut not filled) | yes | R-F-01 |
| 4 | Hull seam scarf + brass collar | **yes — V-J-01 at 24h and 48h** | R-S-01 |
| 5 | Soundboard installation + inlay filling | yes | — |
| 6 | Keel port cut | yes — V-S-03 decision | R-S-03 |
| 7 | Stand (CNC-curve + kanawa-tsugi) | parallel | — |
| 8 | Tuners + cord wraps + bulb caps | yes — fingerprint complete | — |
| 9 | String-holder strip + prototype voicing on MULE | **yes — V-A-05 voicing decision** | R-A-01 |
| 10 | MULE 30-day hold + ROOT gradual stringing | **GATE — V-S-01 + V-T-02** | R-S-01 + R-S-04 |
| 11 | Final voicing + acoustic measurement | yes — V-A-01 | R-A-01 |
| 12 | Documentation + brand integration | yes — V-C-01 + V-B-01 | R-C-01 |

> Full manual at `assembly-manual.md`. Read it before starting.

---

## Validation / tuning sheet (printable)

Full table in `validation.csv`. Bench-side highlights:

### Dimensional checks (V-D-01 through V-D-14)

- [ ] Body length 650 ± 2 mm
- [ ] Body width 150 ± 2 mm
- [ ] Body depth 140–170 mm
- [ ] Instrument height 810 ± 5 mm
- [ ] Hull-wall thickness 6 ± 0.5 mm at midship, bow, stern
- [ ] Neck arc 710 ± 5 mm
- [ ] Brass collar 60 ± 1 mm
- [ ] String-holder strip 120 × 10 × 4 mm
- [ ] Tie-through holes 13, ±0.3 mm spacing, Φ1.5 mm
- [ ] Multi-strip lapis band 11–13 mm total width
- [ ] Bow-end inlay panel 100 × 60 × 1.5 mm pocket
- [ ] Keel port 80 × 50 mm, 12–18° forward tilt

### Structural checks (V-S-01 through V-S-05)

- [ ] SAM-13-MULE 30-day neck-deflection ≤ 2 mm at gold cap
- [ ] Brass collar gap monitor ≤ 0.3 mm over a season
- [ ] Soundboard pull-test holds 2× service load
- [ ] Stern eyebolt holds 30 kgf for 60 s (SAM-19/25/AE only)
- [ ] Keel-port keel deflection ≤ 1.5× unported case

### Tension checks (V-T-01 through V-T-04)

- [ ] MULE total 40–50 kgf
- [ ] ROOT total 65–80 kgf (calibrated)
- [ ] ROOT 30-day tension drift < 10%

### Acoustic checks (V-A-01 through V-A-05)

- [ ] SPL at 1 m within ±6 dB of Wolfram prediction
- [ ] Coupled cavity-plate pair signature (two peaks split 30–80 Hz)
- [ ] Tuning drift < ±10 cents per string at 24 hr
- [ ] Keel-port Helmholtz 128–158 Hz
- [ ] String-holder strip position locked after voicing

### Cultural + brand gates (V-C-01 through V-B-02)

- [ ] Cultural-advisor sign-off on provenance language
- [ ] Every BM 121198 and cylinder-seal image credited
- [ ] Heifer Zephyr placement option locked

---

## Supplier-RFQ summary

Send these RFQs in week 1. Full drafts in `supplier-rfq.md`.

| RFQ | To | Items |
|---|---|---|
| RFQ-1 | Wood supplier | Walnut hull stock, walnut 12/4 base, cedar soundboard (2.5 + 3.0 mm), sapele neck stock, cherry brace stock, holly/maple spacer veneer |
| RFQ-2 | Brass/stainless supplier | Brass tube for collar (×2 for spare), stainless dowel pins, stainless eyebolts, brass rod for cap turning |
| RFQ-3 | String supplier | Set A (G-major calibrated, 13 strings), Set B (A-major drop-in), Set C (MULE reduced tension) |
| RFQ-4 | Tuner supplier + PVD finisher | 13 compact-housing geared tuners + 13 PVD-gold-tone bulb caps (custom-machined or sourced) |
| RFQ-5 | Inlay supplier | Dyed-blue veneer (5 strips × 3 m), holly/maple spacer, MOP/shell composite panel (3 samples for compare), brand inlay stock |
| RFQ-6 | Harness supplier | Low-back belt + locking hook (SAM-19), sax harness + locking hook (SAM-25) |
| RFQ-7 | Electronics supplier | Under-strip piezo + 1/4" jack + wiring (SAM-13-AE only) |

---

## Visual BOM brief

One-page visual BOM lives in `visual-bom-brief.md` plus the rendered visual (placeholder until the photo set is captured). Print last, when the SAM-13-ROOT is finished and photographed.

---

## Appendix — risks worth a second look before each stage

- **R-S-01 Neck cantilever failure** — *the* single highest risk. Hold the MULE for the full 30 days before stringing the ROOT.
- **R-S-04 Soundboard collapse** — pull-test the string-holder-strip glue line on scrap cedar before mounting the production strip.
- **R-S-05 Eyebolt pull-through** — only matters for SAM-19/25/AE, but it's a safety gate when it does.
- **R-A-01 Quiet voice on SAM-13-ROOT** — the small 3.8 L cavity is the chronic concern. Wolfram-sweep before committing soundboard thickness; iterate on MULE.
- **R-C-01 Cultural-advisor review** — public-release gate. Submit the provenance language early; don't wait until Stage 12.
- **R-X-03 PVD bulb caps** — longest-lead supply item. Order in week 1.

---

## Public-release gate checklist (final page)

- [ ] V-S-01 SAM-13-MULE neck-deflection 30-day hold passed
- [ ] V-T-02 SAM-13-ROOT calibrated-tension target hit (65–80 kgf)
- [ ] V-C-01 Cultural-provenance advisor review signed off
- [ ] V-B-01 Heifer Zephyr placement option locked (A soundboard or B stand)
- [ ] R-S-05 SAM-25 eyebolt pull-test passed (if SAM-25 in release scope)
- [ ] All `validation.csv` cultural-category rows closed (V-C-01, V-C-02, V-C-03)
- [ ] `site/index.html` private-review banner removed
- [ ] `README.md` updated to public-release language
- [ ] License files in place (CERN-OHL-W-2.0 for design, CC-BY-4.0 for content)

---

*Tony Koop · Heifer Zephyr · Sambuca SAM-13-ROOT · Fall 2026 capstone · private review*

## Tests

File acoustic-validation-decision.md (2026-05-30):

# Acoustic Validation Decision

Issue: `tonykoop/sambuca#1`

Status: public high-level tracker is acceptable; detailed acoustic validation stays private-review until release gates close.

## Decision

Keep the public issue limited to the decision and gate posture. Do not file detailed public acoustic-validation work yet.

The repo can publicly say that acoustic validation is required, scoped, and not complete. It should not publish detailed measurement results, sensitive source interpretation, private advisor notes, or build-confidence language until the private-review gates are satisfied.

## Evidence considered

- `family-spec.csv` marks `SAM-13-ROOT` as private review and defines `SAM-13-MULE` as the reduced-tension validation build.
- `validation.csv` already separates acoustic checks from public-release blockers. The acoustic rows include SPL, coupled cavity-plate response, tuning drift, Helmholtz frequency, and string-holder-strip voicing checks, while cultural and structural gates remain explicit.
- `design.md` keeps the acoustic model in the Wolfram notebook and states that the repo remains in private review until cultural review, MULE validation, and brand integration are resolved.

## Public-safe scope

Public tracking may include:

- Whether the acoustic validation plan exists.
- Which public files hold the gate definitions.
- Whether validation is complete, incomplete, blocked, or private-review.
- High-level residual risk such as "SPL, coupled response, and tuning drift are unmeasured."

Public tracking should not include:

- Raw private measurement logs before Tony approves release.
- Advisor identities, private correspondence, or redline detail.
- Cultural-source interpretation beyond the already-reviewed public wording.
- Claims that the Sambuca is measured, acoustically validated, fabrication-ready, or public-release-ready before the gates close.

## Current recommendation

Leave issue #1 open as a decision record unless the manager chooses to close it manually after reviewing this PR. The safest public posture is:

> Acoustic validation is planned and gate-defined, but detailed validation work remains private-review until the MULE build data and public-release gates are approved.

## Follow-up gates

- Record SAM-13-MULE SPL, coupled-response, tuning-drift, Helmholtz, and string-holder-strip voicing results in the private build log first.
- Promote only approved summaries into public docs.
- Keep `README.md`, `site/index.html`, and release-facing packet text in private-review posture until the cultural, structural, and brand gates are closed.

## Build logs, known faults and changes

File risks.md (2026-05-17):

# Sambuca — Risk Register

Red-team pass against the SAM-13-ROOT build target and the four sibling variants. Every risk gets a verification test attached. Categories: structural, acoustic, ergonomic, supply, fit/finish, safety, cultural.

Severity scale: **L** = low (cosmetic / recoverable), **M** = medium (rework cost or schedule hit), **H** = high (build-blocking, safety, or release-gating).

---

## Structural

### R-S-01 — Neck cantilever failure under full string tension [H]

The 13-string load resolves into a horizontal pull at the top of the neck (~660 mm above the joint) of roughly 50–65 kgf at the calibrated 65–80 kgf total tension target. The neck-to-body joint sees a bending moment of ~33–43 kgf·m. Sapele cantilever is structurally adequate in calculation, but glue-line strength at the brass collar / scarf joint is the single point of failure.

**Verification:** SAM-13-MULE build at reduced tension (3.0–4.5 kgf/string × 13 = ~50 kgf total). Hold for 30 days, measure neck deflection at the gold cap relative to the body. Pass criterion: ≤2 mm deflection, no audible creak under tuning. Escalate to full ROOT tension only after MULE clears.

### R-S-02 — Brass collar mixed-material seasonal movement [M]

The brass neck collar wraps a glued scarf joint between sapele neck and walnut hull. Brass thermal-expansion coefficient (~19 ppm/°C) is roughly 3× that of either wood. Across a 20°C ambient swing the differential is ~0.4 mm circumferentially on a 60 mm collar — not catastrophic, but enough to telegraph as a hairline gap in finish. Worse: humidity swings move the wood more than the brass, creating a tight-in-summer / loose-in-winter cycle.

**Verification:** Build a test collar on the SAM-13-MULE; install a 0.1 mm gap-monitor at one circumferential position; record at 4-week intervals across a full seasonal cycle. If gap exceeds 0.3 mm, redesign the collar as two half-collars with a hidden expansion gap, or shift to a thinner brass overlay over a structurally-glued wooden interior collar (the brass becomes purely decorative).

### R-S-03 — Keel-port placement vs. structural keel stiffener [M]

The keel port (80 × 50 mm oval at 55% of body length from bow) is cut through the centerline of the keel — exactly where a longitudinal stiffener would normally live if the hull needed one. The cut removes structural capacity at the deepest point of the keel curve.

**Verification:** Run a Wolfram or simple beam analysis on the keel section with and without the port cut. If keel deflection under tension load exceeds 1.5× the no-port case, add a transverse internal brace fore and aft of the port (12 × 12 mm cherry, glued to the inside of the keel). Verify on the SAM-13-MULE before the SAM-13-ROOT cut is committed.

### R-S-04 — Soundboard collapse under combined string and bracing load [M]

The soundboard is 3 mm cedar — thin for a stringed instrument. Under the in-plane pull from the string-holder strip (~50–65 kgf horizontal force) plus the small downward break-angle component, an unbraced cedar soundboard could deflect or crack near the strip. The string-holder strip's hide-glue mounting must transfer load into the soundboard without delaminating.

**Verification:** Light fan-bracing pattern under the strip area (3 × 8 mm cedar braces radiating from the strip toward the inlay band). Pull-test the glued strip on a scrap cedar panel to failure; record breaking load and failure mode. Pass criterion: glue line holds to 2× expected service load.

### R-S-05 — Stern eyebolt pull-through on SAM-19 / SAM-25 harness load [H]

The harness eyebolt (M6 stainless, through-hull with hardwood backing plate) carries the full weight of the instrument when worn (saxophone-harness mode on SAM-25). Instrument weight estimated ~3.2 kg for SAM-25; safety factor of 5× → ~16 kgf working load. The backing plate is 10 × 25 × 40 mm hardwood glued to the inside of the hull.

**Verification:** Static pull test the backing plate to 30 kgf (~9× working load) on a scrap hull panel before the production eyebolt is installed. Record failure mode. Pass criterion: holds 30 kgf for 60 seconds without visible glue-line movement.

---

## Acoustic

### R-A-01 — Small cavity volume + quiet voice on SAM-13-ROOT [M]

The 3.8 L hull volume is small for a stringed instrument with 13 strings. Predicted SPL is below modern lever-harp expectations.

**Verification:** Wolfram parametric sweep across soundboard species × thickness × keel-port geometry produces a predicted SPL curve. Build the SAM-13-MULE and measure SPL at 1 m with a calibrated SPL meter, playing a standard exercise. If measured SPL is more than 6 dB below the prediction, escalate to: (a) thinner cedar (2.5 mm), (b) reduced bracing, (c) larger keel port, or (d) the SAM-13-AE pickup configuration for performance use.

### R-A-02 — Tuning instability under temperature/humidity [M]

Fluorocarbon strings hold tuning well in steady-state but drift in humidity transitions. Geared guitar tuners hidden behind PVD bulb caps should hold position once locked, but the wooden shaft + cord-wrap fingerprint element introduces a sliding-fit interface that could creep.

**Verification:** Tune SAM-13-MULE to standard pitch, leave in playing-temperature room for 24 hours, then measure cents-error per string. Pass: <±10 cents drift on any string. If fail, replace decorative cord-wrap with a glued (non-sliding) version that still presents the visual element.

### R-A-03 — Coupled cavity-plate mode mismatch [M]

The Wolfram model predicts the cavity Helmholtz mode (with keel port) at ~143 Hz and the first plate mode in roughly the same range. If the two are too far apart (>1 octave), the coupled response will have a "hole" in the lower midrange where neither mechanism radiates well; if they coincide too precisely, the coupled pair becomes a single resonance that overwhelms one note.

**Verification:** Sweep frequency response on the SAM-13-MULE with a small speaker driving the soundboard at 50 Hz – 2 kHz; record SPL at the keel port. Look for the coupled-pair signature (two peaks split by ~30–80 Hz). If the spacing is wrong, the keel port `keel_port_long_mm` and `keel_port_short_mm` parameters tune the Helmholtz frequency.

---

## Ergonomic

### R-E-01 — Forward-facing playing position fatigue [L]

The symmetric forward-facing position (long axis between thighs, neck rising away from torso) is comfortable for short sessions but may produce neck or upper-back tension during sustained play because both arms reach forward equally. Different from traditional harp posture (one arm reaches across the body).

**Verification:** 30-minute playing sessions on the SAM-13-MULE with a postural observer. Record posture drift, time-to-first-fatigue, hand position. If sessions consistently produce upper-back fatigue, document recommended-session-length (e.g., "20 min then 5 min break") in the print packet's user guide.

### R-E-02 — Keel port impingement on player's clothing / thigh [L]

The keel port faces forward and downward; with the boat between the thighs, the port may be partially covered by player's pants or thigh contact, reducing radiation toward the listener.

**Verification:** Test on the SAM-13-MULE in seated position with three different player heights / leg-spreads. Document the playing-position photos in `photo-shotlist.md`. If the port is being blocked, document a "thighs-open" playing posture or a small port deflector.

---

## Supply

### R-X-01 — Lapis-look composite or dyed-veneer-and-epoxy availability [L]

The multi-strip lapis band needs 5 parallel strips of dyed-blue veneer (or composite lapis tile). Suppliers vary in color consistency and stock width.

**Verification:** Order test stock from two suppliers; finish-match samples side-by-side. Build a 100 mm test inlay band and confirm CNC routing tolerances. Lead time ~3 weeks; place orders in first month of the schedule.

### R-X-02 — Mother-of-pearl or shell composite for bow inlay panel [L]

The rectangular bow-end inlay panel needs ~100 × 60 mm of pale, period-evoking material. True mother-of-pearl is expensive and brittle. Shell-look composite is workable but visually different.

**Verification:** Compare three candidates (true MOP, abalone composite, pale-stone composite) on a scrap soundboard sample for visual match to the BM photo reference. Pick before committing.

### R-X-03 — PVD-gold-tone brass bulb caps — supplier search [M]

The decorative bulb caps over the geared tuners are the most visible fingerprint element after the neck and lapis band. Off-the-shelf options are rare; this is likely a custom-machined or CNC-turned + PVD-coated part.

**Verification:** Two-pronged search: (a) Maker Nexus shop CNC-turn a sample cap from brass rod + finish at a local PVD shop; (b) source from a small-batch jewelry/clock-parts supplier. Pick the cheaper path that delivers acceptable finish by month 3 of the schedule.

### R-X-04 — Geared guitar tuners fitting inside the neck cross-section [M]

The neck face is 38 mm wide (`neck_width_mm`); standard guitar tuners need ~50 mm of clearance behind the post for the gear housing. The neck depth of 50 mm (`neck_depth_mm`) may be too tight depending on tuner choice.

**Verification:** Order one sample geared tuner, mock-fit into a neck cross-section dummy. If too deep, switch to compact-housing classical-guitar tuners or worm-and-gear harp tuners. Re-spec `neck_depth_mm` if needed.

---

## Fit / finish

### R-F-01 — Multi-strip lapis band CNC tolerances [L]

5 parallel strips × 1.5 mm wide × 0.8 mm spacers requires a 0.8 mm or 1.0 mm end mill on the CNC at depths of 1.5 mm. Tool deflection or breakage is possible.

**Verification:** Run a test inlay band on scrap cedar with the planned end mill; inspect for tool-deflection-induced strip-width variation. Pass criterion: strip width consistent to ±0.2 mm across the band length.

### R-F-02 — Brass collar / wood color transition aesthetic [L]

The brass collar sits between sapele neck and walnut hull. The color transitions need to feel intentional, not jarring. Polished brass is bright; aged/patinated brass is closer to the original gold collar's color.

**Verification:** Finish two test collars — one polished, one chemically aged to a deeper gold tone. Photograph both on a sapele/walnut test joint. Pick before production.

---

## Safety

### R-Z-01 — String breakage at full tension [M]

Fluorocarbon strings under tension store energy; a treble string breaking at ~7 kgf releases that energy as a sharp recoil. The player's face is roughly 200 mm from the top of the neck during play.

**Verification:** Use only fresh strings; replace at the first sign of wear. Document recommended re-stringing intervals in the assembly manual. Note in the user guide: "remove tension fully before any soundboard or strip work."

### R-Z-02 — Saxophone-harness sudden release on SAM-25 [M]

The SAM-25's harness clip is rated for ~16 kgf working load (R-S-05). If the clip fails or the player accidentally disengages it mid-performance, the ~3.2 kg instrument drops to the floor.

**Verification:** Specify a locking (not snap-only) carabiner-class hook for the harness. Document a pre-performance harness check in the user guide.

---

## Cultural

### R-C-01 — Cultural-advisor review finds language insufficient [H]

The "Cultural provenance language (locked for public release)" section of `design.md` is the build packet's claim against misappropriation concerns. The cultural-advisor review gate is one of the three blockers on public release.

**Verification:** Submit `design.md` cultural-provenance section to an advisor with expertise in either Mesopotamian musicology (Andrew Lawler at U Penn / Penn Museum, or equivalent) or living-tradition stewardship advocacy. Document advisor feedback. If they red-line, revise and resubmit. Do not publicly release before written sign-off.

### R-C-02 — *Sambykē* etymological claim contested [L]

The repo and brand term is "sambuca," which evokes the Hellenistic Greek *sambykē* — itself a contested-etymology word. A historian could object that the etymological link to the Sumerian instrument is speculative.

**Verification:** The cultural-provenance language above explicitly acknowledges the uncertainty: "historically debated as a possible descendant of the Sumerian form … not a claim of identity with the Greek instrument." If the cultural advisor wants stronger language, accept the revision; the repo can be renamed if the etymology proves untenable.

### R-C-03 — Imagery in capstone deck and build-log misappropriates living-tradition aesthetics [M]

The Broinwood-style inlay program could pull motifs from the cylinder-seal scenes (Royal Tomb procession, etc.) that, while ancient, are part of the Mesopotamian cultural heritage of modern Iraq. Iraqi cultural-heritage advocates could reasonably ask that imagery be credited to its source.

**Verification:** All cylinder-seal imagery in the deck and build-log is captioned with its catalog source (BM 121198, Penn Museum B16728, etc.) and credited "© Trustees of the British Museum" or "Courtesy Penn Museum, University of Pennsylvania." Confirm with cultural advisor.

---

## Risk summary

| Risk | Severity | Owner | Validation surface |
|---|---|---|---|
| R-S-01 Neck cantilever failure | H | structural-test | SAM-13-MULE 30-day hold |
| R-S-02 Brass collar seasonal movement | M | structural-test | seasonal gap monitor |
| R-S-03 Keel port vs keel stiffener | M | Wolfram + MULE | beam analysis + MULE keel deflection |
| R-S-04 Soundboard collapse | M | structural-test | pull-test on scrap |
| R-S-05 Eyebolt pull-through (SAM-25) | H | structural-test | 30 kgf static pull test |
| R-A-01 Quiet voice on SAM-13-ROOT | M | acoustic-test | SPL measurement vs prediction |
| R-A-02 Tuning instability | M | acoustic-test | 24-hr drift test |
| R-A-03 Coupled mode mismatch | M | acoustic-test | sweep frequency response |
| R-E-01 Playing position fatigue | L | ergonomic-test | 30-min playing sessions |
| R-E-02 Keel port impingement | L | ergonomic-test | seated-position photo set |
| R-X-01 Lapis stock availability | L | sourcing | two-supplier sample compare |
| R-X-02 MOP / shell composite | L | sourcing | three-candidate sample compare |
| R-X-03 PVD bulb caps | M | sourcing | parallel custom-shop + jewelry-supplier search |
| R-X-04 Tuner fit in neck | M | sourcing | mock-fit before commit |
| R-F-01 Multi-strip CNC tolerances | L | CNC-test | scrap-cedar test inlay |
| R-F-02 Brass color transition | L | finish-test | polished vs aged sample |
| R-Z-01 String breakage | M | safety | user-guide doc |
| R-Z-02 Harness release | M | safety | locking hook spec |
| R-C-01 Cultural-advisor review | H | cultural review gate | external advisor sign-off |
| R-C-02 *Sambykē* etymology | L | cultural review gate | advisor language pass |
| R-C-03 Imagery attribution | M | cultural review gate | captions + credits audit |

Three risks are public-release-blocking: **R-S-01** (neck cantilever), **R-S-05** (SAM-25 harness eyebolt), and **R-C-01** (cultural advisor review).

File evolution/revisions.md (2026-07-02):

# Revision Register — sambuca

| Rev | Date | Parent | Delta | Downstream artifacts invalidated |
| --- | --- | --- | --- | --- |
| A | 2026-07-01 | — | Stage 0 intake of current masters (cad/sambuca.scad parametric envelope + cad/SAM-000_master-equations.txt single-source-of-truth). | none (no alpha/beta/production artifacts exist yet; SolidWorks rebuild still pending) |

Stage 0 only. Gate A has not been run; no Alpha compiles, vendor quotes, or production lock exist for this product. SolidWorks MasterLayout rebuild (kora Pack-and-Go migration) remains an open upstream task.

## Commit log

2026-05-17 Initial sambuca instrument packet
    [SAM-000_MasterLayout.SLDPRT, SAM-000_MasterLayout.xlsx, SAM-000_SAMBUCA.SLDASM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]
2026-05-30 feat: add V5 surface — visual-output-register, cad/mcp-session-log, README L-status
    Refs instrument-maker#184
    [visual-output-register.csv]
2026-05-31 wolfram-rename(sambuca): unique {slug}-starter.wl + dedupe + ref fixes (cloud-sync naming) (#5)
    [SAM-000_BoatBody.SLDPRT, SAM-000_MasterLayout.SLDPRT, SAM-000_MasterPart.SLDPRT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]
2026-05-31 Add image-gen concept prompt; wire explorer images
2026-07-01 V5 packet refresh: status line, provenance, parametric OpenSCAD master, evolution intake
    - Cleaned README status line to bold **Status:** L2 V5 build-packet candidate; moved "private review" prose into a new ## Readiness section.
    - Authored parametric OpenSCAD envelope master cad/sambuca.scad (boat-hull/neck; traced to SAM-000_master-equations.txt + family-spec.csv; render check openscad -o STL exit 0; pending_measurement, no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
    - Added register row + provenance rows (scad render check, packet refresh) to cad/mcp-session-log.md; added cad/README file-map row.
    - Added evolution/ Stage 0 intake (manifest, design-intent, revisi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
    [sambuca.scad, visual-output-register.csv]
